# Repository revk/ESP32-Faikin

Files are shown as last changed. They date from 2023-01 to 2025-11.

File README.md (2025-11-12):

### Name change

Yes, it seems Daikin don't like Faikin, and I don't have the time or money to argue.

# ESP32-Faikout

Everyone knows Daikin make some of the best air conditioners out there, mechanically speaking. Sadly their WiFi control modules are not so good, especially the latest models which are all cloud based, require an internet connection to even work, and are slow.

[Faikout](https://www.youtube.com/watch?v=2QziOhK4P70 "Faikout")
Optional cabel
Optional case

This code/module provides local control via web interface, MQTT, and HomeAssistant integration, all with no cloud crap.



* There is also a new [Faikout Remote Control](https://remote.revk.uk/) available, BLE linked to the Faikout, with environmental sensors, available on Tindie now.

PCB designs are included, and also available to buy on [Tindie](https://www.tindie.com/stores/revk/), and on [Amazon UK](https://www.amazon.co.uk/dp/B0G1TP8XCQ). There are other people making and selling, e.g. on [eBay Australia](https://www.ebay.com.au/itm/186860658654).

I'd like to thank the contributors, but contributions are made and accepted on basis that you issue your contribution under the same GPL licence as the project. Forks are allowed on the basis that your forks are on the same GPL licence as the project.

## Trademark

This is an open source project, but bear in mind you cannot sell boards bearing the Andrews & Arnold Ltd name, the A&A logo, the registered trademark AJK logo, or the GS1 allocated EANs assigned to Andrews & Arnold Ltd.

## Further manuals / links

- [Work in progress / release notes](https://github.com/revk/ESP32-Faikout/wiki/Work-in-progress)
- [Wiring](https://github.com/revk/ESP32-Faikout/wiki/Wiring)
- [Setup](Manuals/Setup.md) Manual
- [Controls](Manuals/Controls.md) Manual
- [Advanced](Manuals/Advanced.md) Manual
- [ESP8266 port](https://github.com/Sonic-Amiga/ESP8266-Faikin) of this code
- [list of supported air-con](https://github.com/revk/ESP32-Faikout/wiki/List-of-confirmed-working-air-con-units) WiKi (please update as needed)
- [DoC](Manuals/DoC.md) and Vulnerability disclosure policy
- [S21](Manuals/S21.md) reverse engineered details of `S21` protocol

For support, see issues and discussions.

## PCB and case

The boards from [Tindie](https://www.tindie.com/stores/revk/), [eBay](https://www.ebay.com.au/itm/186860658654), and [Amazon UK](https://www.amazon.co.uk/dp/B0G1TP8XCQ) works with Daikin modules via an `S21` connector, or `X50A` and `X35A` connectors, or similar. The design is updated from time to time so may not look exactly like this.

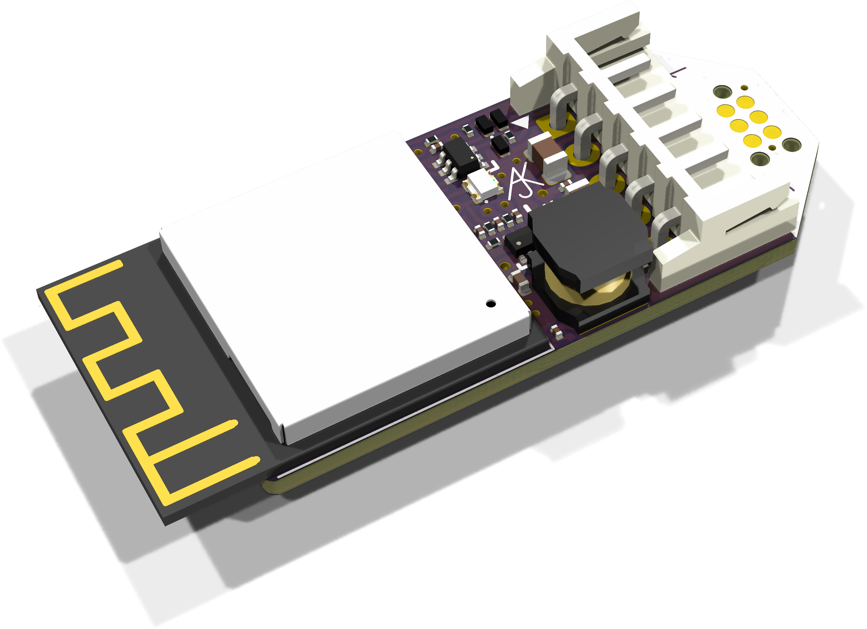
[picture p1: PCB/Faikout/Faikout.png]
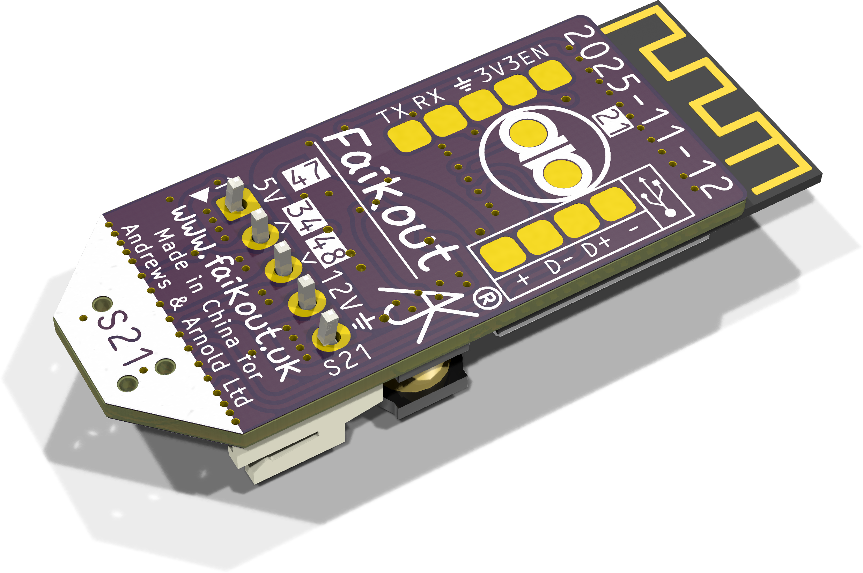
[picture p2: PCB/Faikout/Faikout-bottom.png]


The case design matches the PCB (check dates match). Designed for resin printing.

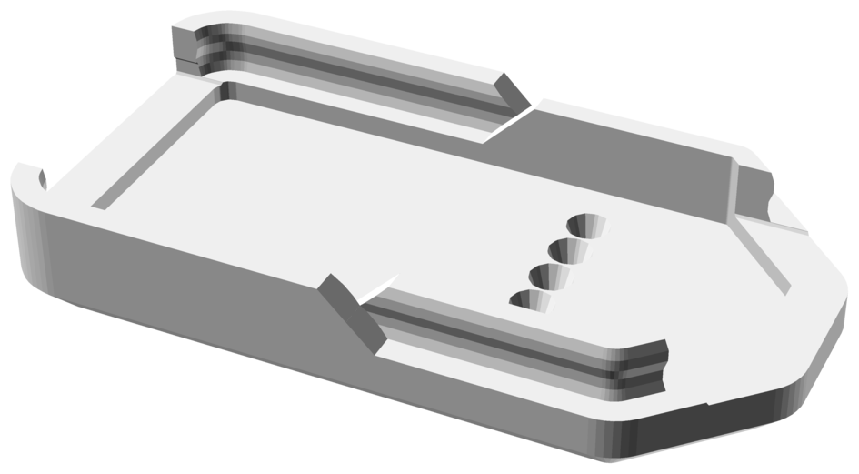
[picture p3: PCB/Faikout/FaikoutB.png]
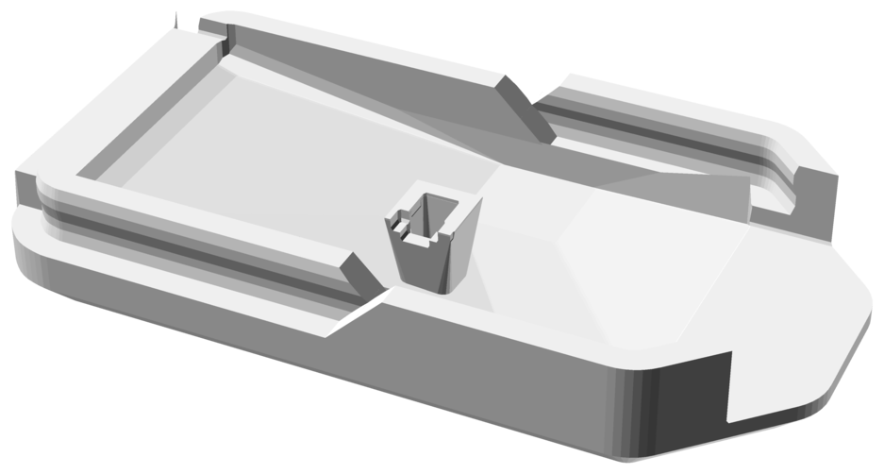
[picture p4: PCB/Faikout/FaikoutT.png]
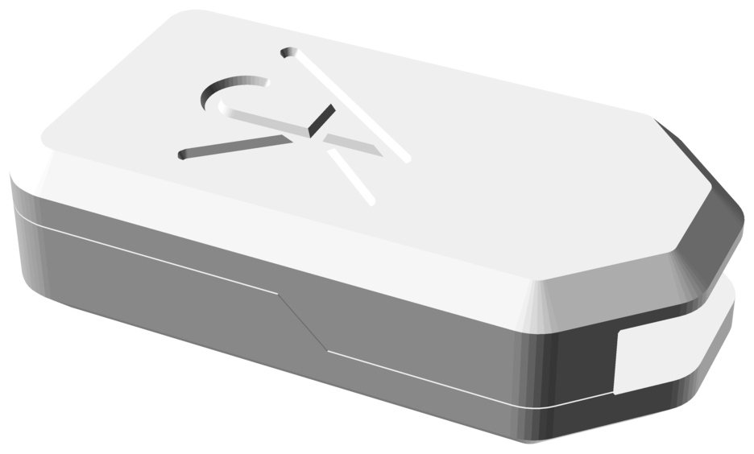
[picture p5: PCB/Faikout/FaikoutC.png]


Supplied in a 70x70 panel as an assembled PCB with snap off parts down to two sizes. 45x36mm or 40x16mm.

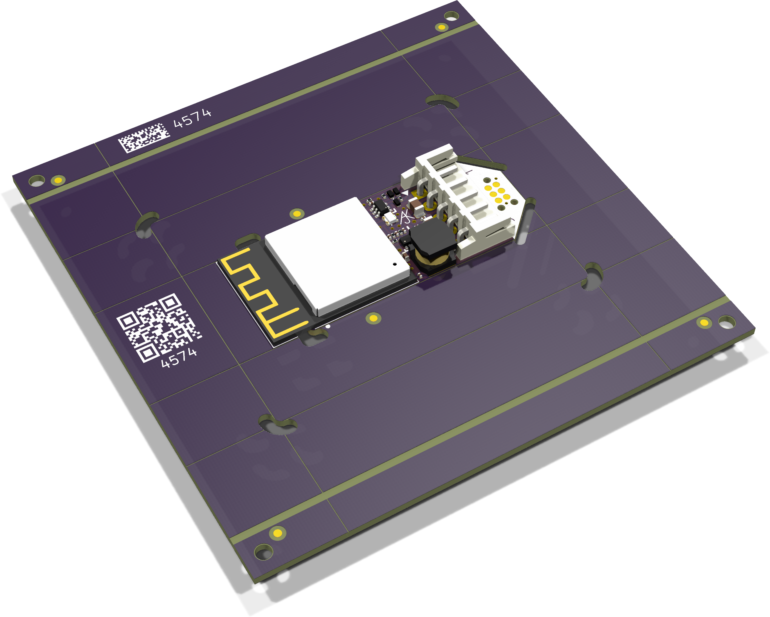
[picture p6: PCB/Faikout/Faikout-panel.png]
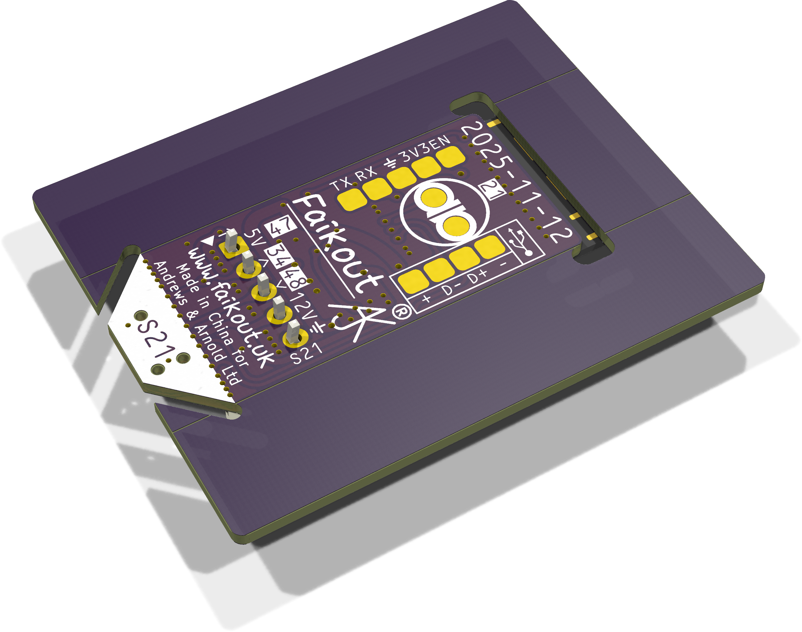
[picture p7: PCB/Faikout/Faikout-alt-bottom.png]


## Why I made this

The history is that, after years of using Daikin air-con in my old home, and using the local http control, in my new house in Wales the WiFi was all cloud based with no local control, and useless, and slow. Just configuring it was a nightmare. I spent all day reverse engineering it and making a new module to provide local control. Pull requests and feature ideas welcome.

This whole project is almost entirely by me, but with some valuable contributions from others (thank you). All of my bits are copyright by me and Andrews & Arnold Ltd who sponsor the whole project, and released under GPL. Whilst not required by the licence, attribution and links would be appreciated if you reuse this.

## How to get one

As mentioned, [Tindie](https://www.tindie.com/stores/revk/), [eBay](https://www.ebay.com.au/itm/186860658654), and [Amazon UK](https://www.amazon.co.uk/dp/B0G1TP8XCQ).

But also, the PCB designs are published, including production files for [JLCPCB](https://jlcpcb.com). You need to remove trademarks, etc, and you would also need something to program them (TC2030 lead). Obviously you need some experience with PCB ordering and diagnostics if getting your own boards made.

# Set-up

Appears as access point with simple web page to set up on local WiFI. On iPhone the setup page auto-loads.

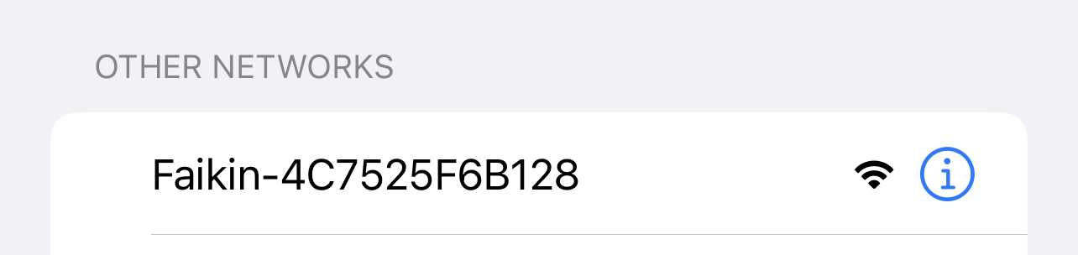
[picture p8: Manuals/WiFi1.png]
WiFi1


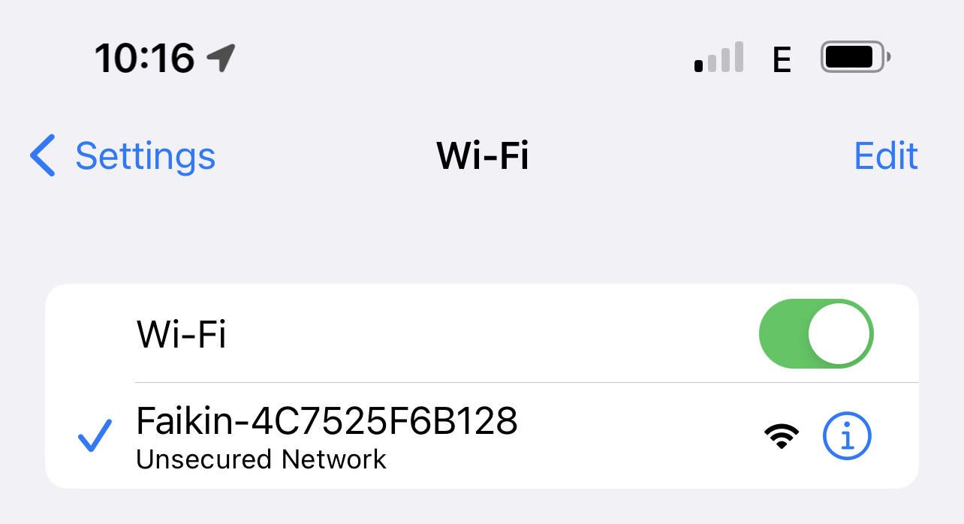
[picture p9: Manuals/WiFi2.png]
WiFi2


# Operation

Local interactive web control page using *hostname*.local, no app required, no external internet required.

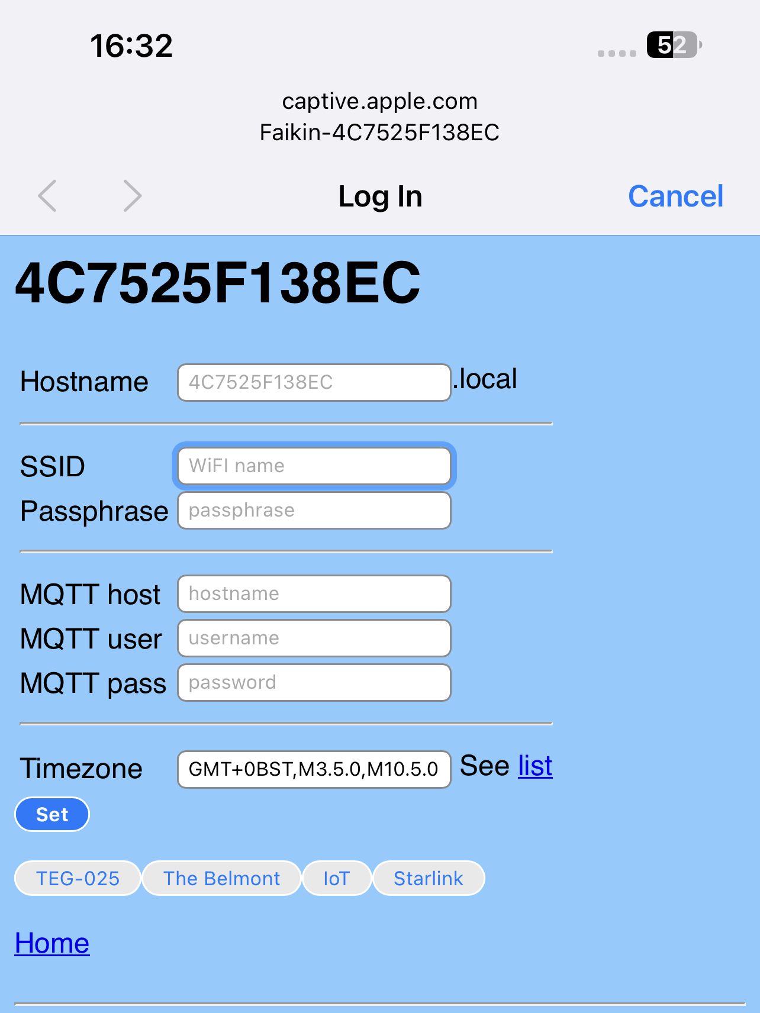
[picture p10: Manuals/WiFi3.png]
WiFi3


- [Setup](Manuals/Setup.md) Manual
- [Controls](Manuals/Controls.md) Manual
- [Advanced](Manuals/Advanced.md) Manual

# Design

* KiCad PCB designs included, with JLCPCB production files
* 3D printed case STL files
* Documentation of reverse engineered protocol included

Basically, Daikin have gone all cloudy with the latest WiFi controllers. This module is designed to provide an alternative.

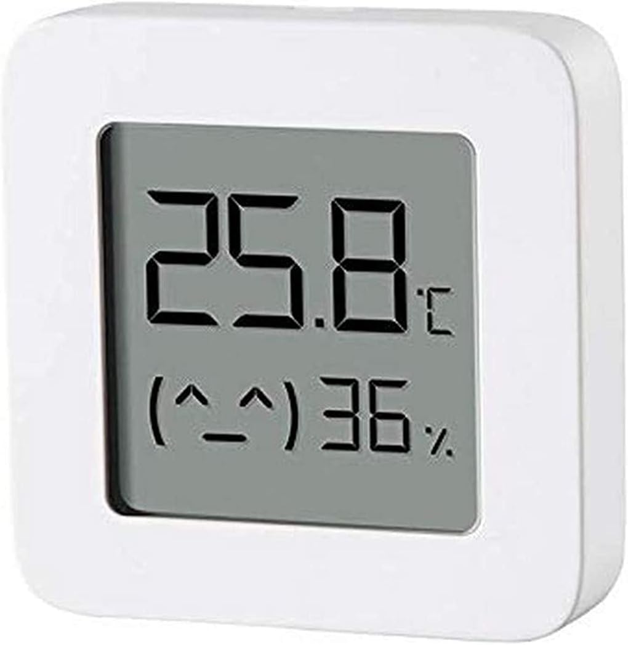
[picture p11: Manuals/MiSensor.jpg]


* Simple local web based control with live websocket status, easy to save as desktop icon on a mobile phone
* MQTT reporting and controls
* Works with Home Assistant over MQTT - note Home Assistant can work with HomeKit
* Includes linux mysql/mariadb based logging and graphing tools
* Works with [EnvMon](https://github.com/revk/ESP32-EnvMon) Environmental Monitor for finer control and status display
* or, works with BlueCoinT and Telink [BLE temperature sensor](Manuals/BLE.md) as a remote reference in an auto mode
* Automatically works out if S21 or X50 protocol (used on bigger/ducted units)
* Backwards compatible direct `/aircon/...` URLs

# Building code yourself

Git clone this `--recursive` to get all the submodules, and it should build with just `make`. There are make targets for other variations, but this hardware is the `make pico` or `make s3` version. The `make` actually runs the normal `idf.py` to build which then uses cmake. `make menuconfig` can be used to fine tune the settings, but the defaults should be mostly sane. `make flash` should work to program. If flashing yourself, you will need a programming lead, e.g. [Tazmotizer](https://github.com/revk/Shelly-Tasmotizer-PCB) or similar, and of course the full ESP IDF environment. The latest boards also have 4 pads for direct USB connection to flash with no adaptor. The modules on Amazon come pre-loaded and can upgrade over the air.

The code is normally set up to automatically upgrade the software, checking roughtly once a week. You can change this in settings via MQTT.

If you build yourself, you either need no code signing, or your own signing key. This will break auto-updates which try to load my code releases, so you need to adjuist settings `otahost` and `otaauto` accordingly. You can set these in the build config, along with WiFi settings, etc.

If you want to purchase a pre-loaded assembled PCB, see [Tindie](https://www.tindie.com/stores/revk/), and [Amazon UK](https://www.amazon.co.uk/dp/B0C2ZYXNYQ).

## Flashing code

You will need to connect a suitable programming lead. Boards have a header for USB. The very latest design (expected on Amazon around Sep 2024) has a tag-connect compatible header for a [TC2030-USB-NL](https://www.tag-connect.com/product/tc2030-usb-nl) lead. Note that the latest boards have testr pads on the back which include USB, so you can solder a USB lead if necessary.

See [https://github.com/revk/ESP32-RevK](https://github.com/revk/ESP32-RevK) for more details of how to flash the files easily.

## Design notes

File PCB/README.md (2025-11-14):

# PCB designs

The design is in [KiCad](https://www.kicad.org) and has production files for JLCPCB. The boards are available on [Amazon](https://www.amazon.co.uk/dp/B0C2ZYXNYQ).

The `PCBCase` directory is a tool for making 3D cases from the PCBs files, these are usually kept up to date as an `.stl` file in the `Faikout` directory. The `Makefile` simply runs this tool.

## Trademark

This is an open source project, but bear in mind you cannot sell boards bearing the Andrews & Arnold Ltd name, the A&A logo, the registered trademark AJK logo, or the GS1 allocated EANs assigned to Andrews & Arnold Ltd.



## Panel

Supplied in a 70x70 panel as an assembled PCB with snap off parts down to two sizes. 45x36mm or 40x16mm.



The panel includes slots and v-cuts to allow the unwanted parts of the panel to be snapped off. On the thicker (1.6mm) boards this can be a tad un-nerving, but just bend along the v-cut to snap the board on the cut line. I make the boards at 1.2mm thickness to make this easier.

The board design also allows the panel to be snapped off down to a 45mm x 36mm small board. This is the same size as commonly used for built-in Daikin WiFi modules, so if replacing the standard Daikin WiFi, it should fit exactly in the case. Obviously this only applies to some models.

You can further snap off down to the actual module, which is currently 40mm x 16mm. This is the usual way the module is used. The 3D print design is for this board.

The back of the board has no components, making it simple to stick to a flat surface with tape - you may want to crop the pins on the 5 pin connector if doing this. Do not stick to a metal surface as this may impact the WiFi or short the pins.

## S21 Connector

The connector is `JST-EH` 5 pin connector. This seems to be pretty standard in Daikin units. It is the connector used on the Daikin WiFi modules `BRP069B41` and `BRP069C41`. This means it should usually be possible to get a lead for your Daikin to a `JST-EH` 5 pin `S21` connector. If you have an `S21` connector on your air-con it will likely be the same pin out, so one to one wiring. If you have an `X50A` connector the wiring is different, and getting a suitable lead is a good idea.

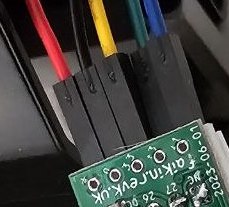
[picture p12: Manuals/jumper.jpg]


From what we can tell, the `S21` pin out is as follows :-

|Pin|Meaning|
|---|---|
|1|5V (not always present)|
|2|Tx from aircon - 5V logic levels|
|3|Rx to aircon - expects 5V logic and has 5V pull up, but some modeles work at 3.3V|
|4|12V, or 14V. We accept 4V to 36V|
|5|GND|

However, there are jumper wires readily available that can be used easily with these connectors, and can be used to connect to the `S21` connector on the aircon PCB one wire at a time.

**Please take care with your air-con unit - disconnect power before opening, and anything you do is at your own risk.**

## GPIO

This board is designed to work with the Daikin air-con, but it is a general purpose board. The latest boards use `ESP32-S3-MINI-N4R2` processor, with previous being `ESP32-MINI-PICO-01`.

The current boards include the GPIO numbers clearly in inverse silk screen.

For example, on this image, GPIO `34` and `48` for Tx and Rx. GPIO `47` is for the WS2812 style LED. GPIO `21` is one of two round pads.

The two round pads in the A&A logo can be shorted three times in a row to factory reset.

There are also test pins which allow connection for USB, and for diagnostics during production. A TC2030 connector is used for production programming.

Bottom

## Programming

The board has pads for a TC2030 USB lead for programming directly using `esptool`.

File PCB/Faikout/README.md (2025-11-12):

# Faikout

## Trademark

This is an open source project, but bear in mind you cannot sell boards or cases bearing the Andrews & Arnold Ltd name, the A&A logo, the registered trademark AJK logo, or the GS1 allocated EANs assigned to Andrews & Arnold Ltd.

## PCB Designs

These files are for use with [KiCAD](https://www.kicad.org).

- [Faikout](Faikout.kicad_pro)

## 3D

3D case designs are normally automatically created from the PCB so as to ensure correct details and placement of apertures, etc.

|Design|Bottom|Top|Combined|
|---|---|---|---|
|Faikout||||

## PCB Images

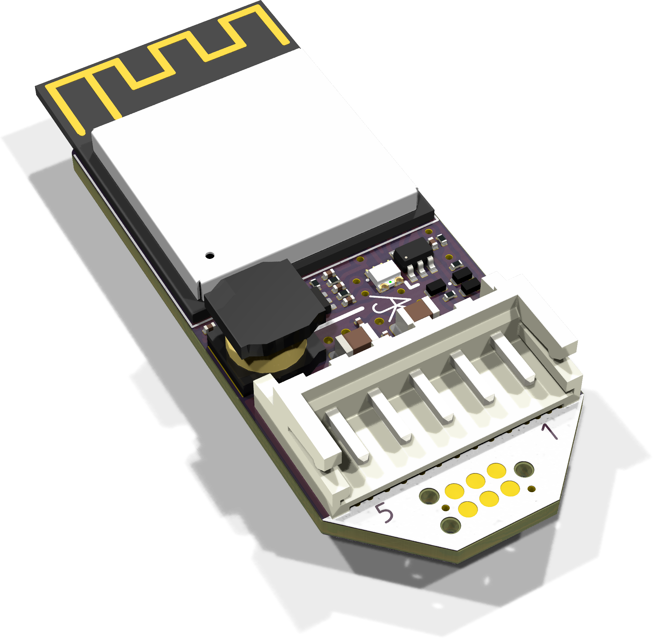
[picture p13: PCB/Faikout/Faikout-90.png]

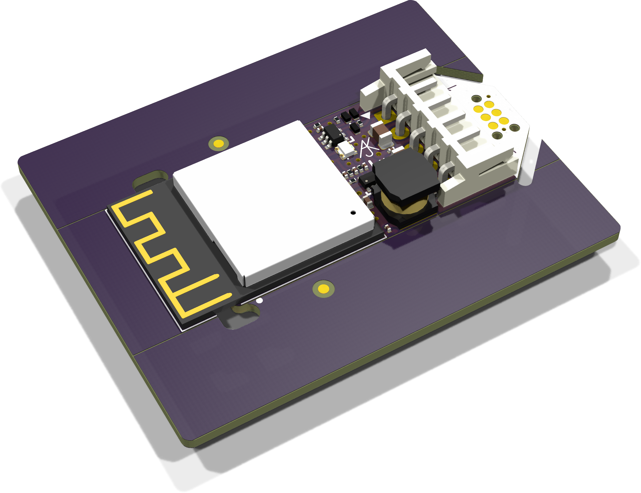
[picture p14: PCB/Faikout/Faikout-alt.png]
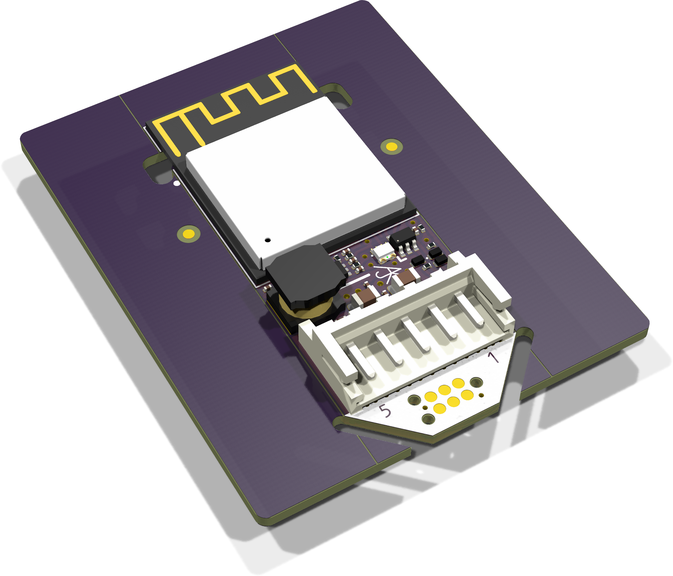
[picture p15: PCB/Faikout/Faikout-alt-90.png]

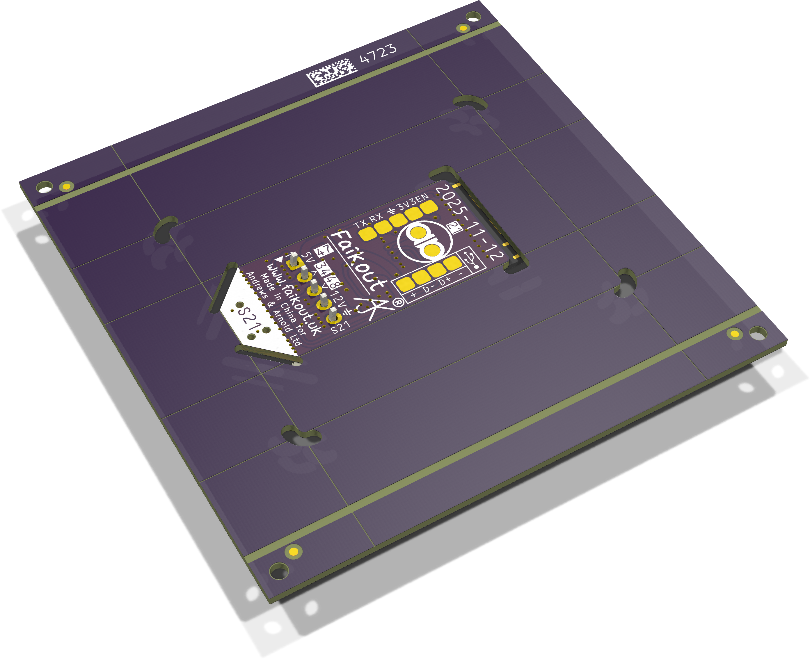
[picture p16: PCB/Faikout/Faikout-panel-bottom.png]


---

*Auto generated README.md 2025-11-12T08:11:45*

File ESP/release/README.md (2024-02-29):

# Reflashing

Ideally you build the code and flash, but that will be your code signing.

You can also flash these binaries.

You need `esptool`

## esptool

`esptool.py -p /dev/ttyUSB0 write_flash 0x1000 Faikin-S1-PICO-bootloader.bin 0x8000 partition-table.bin 0xd000 ota_data_initial.bin 0x10000 Faikin-S1-PICO.bin`

- The `Faikin-S1-PICO-bootloader.bin` needs to be the relevant release bootloader binary file for the chip used.
- The `Faikin-S1-PICO.bin` needs to be the relevant release binary file for the chip used.
- The bootloader address differs between ESP32 versions S1 and S3. For the S1 versions the bootloader is located at 0x1000. For the S3 models this needs to be changed to 0x0.

## 8266 port

The ESP8266 port is maintained by Pavel Fedin; project URL is: https://github.com/Sonic-Amiga/ESP8266-Faikin .
Since this is a backport; it may lack some features of the newest ESP32 version. Please contact the author for any questions.

Flashing command (addresses differ from ESP32 !!!)

`esptool.py -p COM3 -b 460800 --after hard_reset write_flash --flash_mode dio --flash_freq 40m --flash_size 8MB 0x8000 partition-table-8266.bin 0xd000 ota_data_initial-8266.bin 0x0 Faikin-8266-bootloader.bin 0x10000 Faikin-8266.bin`

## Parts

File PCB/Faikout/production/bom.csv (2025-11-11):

Designator | Footprint | Quantity | Value | LCSC Part #
C1, C18, C2, C4, C5, C7 | C_0201 | 6 | 100nF | C76934
C15 | C_0805 | 1 | 47uF 6V3 | C16780
C16, C3 | C_0402 | 2 | 100nF 25V | C56392
C17 | C_0805 | 1 | 22uF 25V | C45783
C19 | C_0201 | 1 | 18pF | C62164
C6 | C_0201 | 1 | 1uF
D1 | SMD1615-Blind | 1 | XL-1615RGBC-2812B | C5349954
D2, D3 | DFN1006-2L | 2 | ~ | C5137770
D4 | D_0402 | 1 | D | C28642302
J1 | JST_EH_S5B-EH_1x05_P2.50mm_Horizontal | 1 | 1x5 | C265103
L1 | L_5x5 | 1 | 4.7uH | C307876
Q1 | SOT-363_SC-70-6 | 1 | BSS138PS | C193381
R1, R2, R3 | R_0201 | 3 | 10k | C106225
R5, R6 | R_0201 | 2 | 150k 1% | C310173
R8 | R_0201 | 1 | 33k 1% | C320835
U1 | SOT-563 | 1 | TPS562246 | C41833479
U4 | ESP32-S3-MINI-1 | 1 | ESP32-S3-MINI-1-N4R2 | C3013941

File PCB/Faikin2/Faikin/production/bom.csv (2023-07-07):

Designator | Footprint | Quantity | Value | LCSC Part #
C1 | C_0402 | 1 | 1uF
C10 | C_0603_ | 1 | 100nF
C2, C5 | C_0402 | 2 | 100nF
C6, C7 | C_0402 | 2 | 33pF
C8 | C_0603_ | 1 | 10uF 50V | C1591
C9 | C_0603_ | 1 | 10uF 6.3V | C1691
D2 | LED-RGB-1.6x1.6 | 1 | RGB | C264508
J1 | JST_EH_S5B-EH_1x05_P2.50mm_Horizontal | 1 | 1x5 | C225427
L2 | L_4x4_ | 1 | 10uH
Q1 | SOT-363_SC-70-6 | 1 | BSS138PS | C193381
R1, R3, R4 | R_0402 | 3 | 10k
R10 | R_0402_ | 1 | 39k2
R11 | R_0402_ | 1 | 1M
R12 | R_0402 | 1 | 220R
R2, R8 | R_0402 | 2 | 100R
R5 | R_0402 | 1 | 680R
R6 | R_0402 | 1 | 2K
R9 | R_0402_ | 1 | 124k
U1 | ESP32-PICO-MINI-02 | 1 | ESP32-PICO-MINI-02 | C2980306
U3 | SOT-23-6-MD8942 | 1 | MD8942 | C2684786

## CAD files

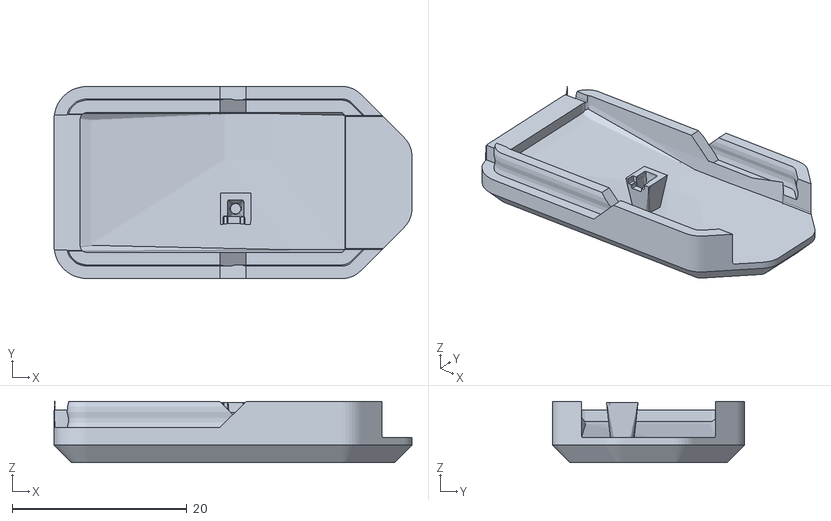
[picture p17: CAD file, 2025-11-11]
PCB/Faikin/FaikinT.stl
41.0 x 22.0 x 6.99

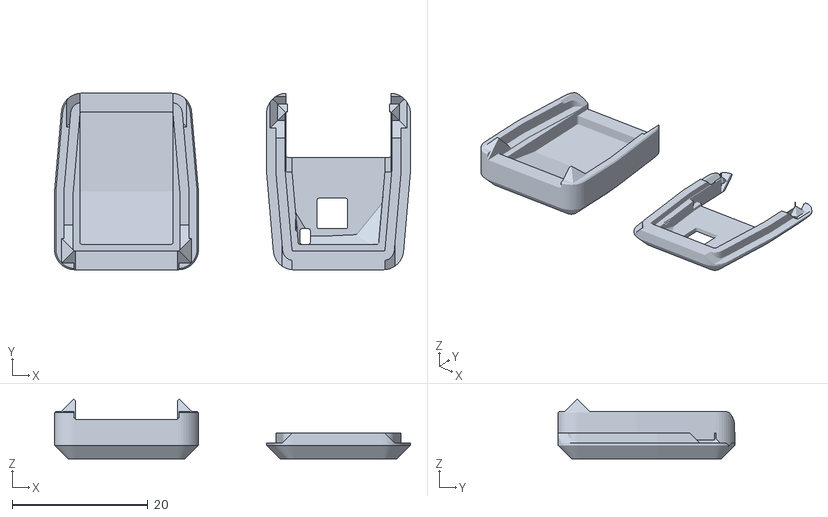
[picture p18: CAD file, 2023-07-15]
PCB/Faikin2/Faikin/Faikin.stl
52.4 x 26.0 x 8.79

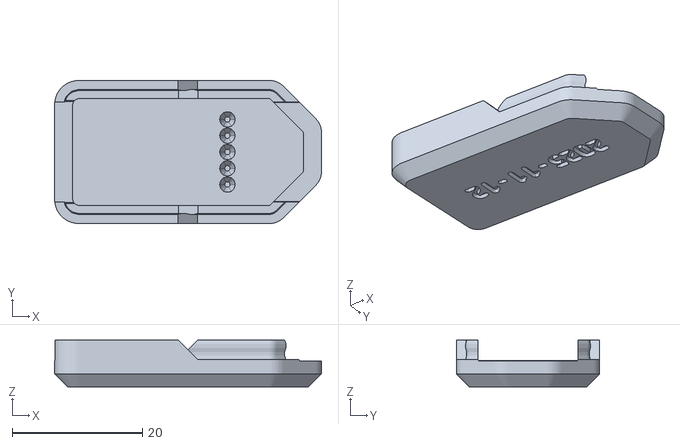
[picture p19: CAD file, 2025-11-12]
PCB/Faikout/FaikoutB.stl
41.0 x 22.0 x 7.20

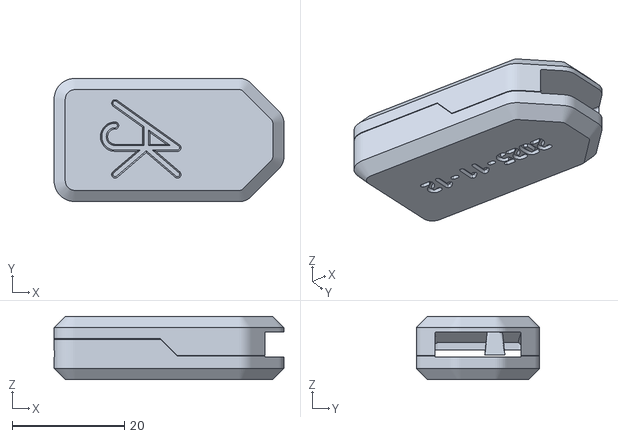
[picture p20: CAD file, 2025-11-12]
PCB/Faikout/FaikoutC.stl
41.0 x 22.0 x 11.3

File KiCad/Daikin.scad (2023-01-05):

// Generated case design for KiCad/Daikin.kicad_pcb
// By https://github.com/revk/PCBCase
// Generated 2023-01-05 14:30:20
// title:	Daikin ESP32-PICO-MINI Module
// date:	${DATE}
// rev:	1
// company:	Adrian Kennard, Andrews & Arnold Ltd
//

// Globals
margin=0.500000;
overlap=2.000000;
lip=0.000000;
casebase=2.500000;
casetop=5.000000;
casewall=3.000000;
fit=0.000000;
edge=2.000000;
pcbthickness=0.800000;
nohull=false;
hullcap=1.000000;
hulledge=1.000000;
useredge=false;

module pcb(h=pcbthickness,r=0){linear_extrude(height=h)offset(r=r)polygon(points=[[13.200000,0.400000],[13.200000,19.100000],[13.082843,19.382843],[12.800000,19.500000],[0.400000,19.500000],[0.117157,19.382843],[0.000000,19.100000],[0.000000,0.400000],[0.117157,0.117157],[0.400000,0.000000],[12.800000,0.000000],[13.082843,0.117157]],paths=[[0,1,2,3,4,5,6,7,8,9,10,11]]);}

module outline(h=pcbthickness,r=0){linear_extrude(height=h)offset(r=r)polygon(points=[[13.200000,0.400000],[13.200000,19.100000],[13.082843,19.382843],[12.800000,19.500000],[0.400000,19.500000],[0.117157,19.382843],[0.000000,19.100000],[0.000000,0.400000],[0.117157,0.117157],[0.400000,0.000000],[12.800000,0.000000],[13.082843,0.117157]],paths=[[0,1,2,3,4,5,6,7,8,9,10,11]]);}
spacing=29.200000;
pcbwidth=13.200000;
pcblength=19.500000;
// Populated PCB
module board(pushed=false,hulled=false){
translate([6.600000,13.906750,0.800000])translate([0.000000,2.700000,0.000000])rotate([90.000000,0.000000,0.000000])m0(pushed,hulled); // RevK:ESP32-PICO-MINI-02 ESP32-PICO-MINI-02
translate([6.600000,6.600000,0.800000])translate([1.250000,-3.600000,2.500000])rotate([-0.000000,0.000000,180.000000])m1(pushed,hulled); // RevK:Molex_MiniSPOX_H4RA 22057055
translate([1.050000,12.950000,0.000000])rotate([0,0,-90.000000])rotate([180,0,0])m2(pushed,hulled); // RevK:C_0805_ C_0805_2012Metric
translate([11.150000,13.375000,0.000000])rotate([0,0,-90.000000])rotate([180,0,0])m3(pushed,hulled); // RevK:R_0603 R_0603_1608Metric
translate([4.100000,9.350000,0.000000])rotate([0,0,90.000000])rotate([180,0,0])m4(pushed,hulled); // RevK:C_0603 C_0603_1608Metric
translate([10.850000,9.600000,0.000000])rotate([180,0,0])m5(pushed,hulled); // Package_TO_SOT_SMD:SOT-323_SC-70 SOT-323_SC-70
translate([4.170000,13.330000,0.000000])rotate([0,0,180.000000])rotate([180,0,0])m6(pushed,hulled); // RevK:D_1206_ D_1206_3216Metric
translate([8.550000,16.250000,0.000000])rotate([0,0,-90.000000])rotate([180,0,0])m4(pushed,hulled); // RevK:C_0603 C_0603_1608Metric
translate([9.125000,18.600000,0.000000])rotate([180,0,0])m3(pushed,hulled); // RevK:R_0603 R_0603_1608Metric
translate([9.900000,13.400000,0.000000])rotate([0,0,-90.000000])rotate([180,0,0])m3(pushed,hulled); // RevK:R_0603 R_0603_1608Metric
translate([12.450000,13.400000,0.000000])rotate([0,0,-90.000000])rotate([180,0,0])m3(pushed,hulled); // RevK:R_0603 R_0603_1608Metric
translate([2.100000,9.850000,0.000000])rotate([180,0,0])m3(pushed,hulled); // RevK:R_0603 R_0603_1608Metric
translate([7.300000,12.950000,0.000000])rotate([0,0,-90.000000])rotate([180,0,0])m2(pushed,hulled); // RevK:C_0805_ C_0805_2012Metric
translate([11.500000,15.900000,0.000000])rotate([180,0,0])translate([0.000000,-0.400000,0.000000])m7(pushed,hulled); // RevK:LED-RGB-1.6x1.6 LED_0603_1608Metric
translate([11.500000,15.900000,0.000000])rotate([180,0,0])translate([0.000000,0.400000,0.000000])m7(pushed,hulled); // RevK:LED-RGB-1.6x1.6 LED_0603_1608Metric
translate([2.100000,8.600000,0.000000])rotate([180,0,0])m4(pushed,hulled); // RevK:C_0603 C_0603_1608Metric
translate([6.450000,16.500000,0.000000])rotate([0,0,180.000000])rotate([180,0,0])rotate([-0.000000,0.000000,90.000000])m8(pushed,hulled); // RevK:SOT-23-Thin-6-Reg SOT-23-6
translate([2.550000,16.500000,0.000000])rotate([180,0,0])rotate([-0.000000,0.000000,90.000000])m9(pushed,hulled); // RevK:L_4x4_ TYA4020
translate([11.600000,18.600000,0.000000])rotate([0,0,180.000000])rotate([180,0,0])m3(pushed,hulled); // RevK:R_0603 R_0603_1608Metric
}

module b(cx,cy,z,w,l,h){translate([cx-w/2,cy-l/2,z])cube([w,l,h]);}
module m0(pushed=false,hulled=false)
{ // RevK:ESP32-PICO-MINI-02 ESP32-PICO-MINI-02
rotate([90,0,0])
translate([-13.2/2,-16.6/2,0])
{
	if(!hulled)cube([13.2,16.6,0.8]);
	cube([13.2,11.2,2.4]);
}
}

module m1(pushed=false,hulled=false)
{ // RevK:Molex_MiniSPOX_H4RA 22057055
N=5;
A=2.4+N*2.5;
rotate([0,0,180])
translate([-A/2,-2.94,-2.5])
{
	cube([A,4.9,4.9]);
	cube([A,5.9,3.9]);
	hull()
	{
		cube([A,7.4,1]);
		cube([A,7.9,0.5]);
	}
	translate([1,6,-2])cube([A-2,1.2,4.5]); // Assumes cropped pins
	// Plug
	translate([0.5,-20,0.6])cube([A-1,21,4.1]);
	translate([0,-23,0])cube([A,20,4.9]);
}

}

module m2(pushed=false,hulled=false)
{ // RevK:C_0805_ C_0805_2012Metric
b(0,0,0,2,1.45,0.2); // Pad size
b(0,0,0,2,1.2,1); // Chip
}

module m3(pushed=false,hulled=false)
{ // RevK:R_0603 R_0603_1608Metric
b(0,0,0,2.8,0.95,0.5); // Pad size
}

module m4(pushed=false,hulled=false)
{ // RevK:C_0603 C_0603_1608Metric
b(0,0,0,1.6,0.95,0.2); // Pad size
b(0,0,0,1.6,0.8,1); // Chip
}

module m5(pushed=false,hulled=false)
{ // Package_TO_SOT_SMD:SOT-323_SC-70 SOT-323_SC-70
b(0,0,0,1.26,2.2,1.2);
b(0,0,0,2.2,2.2,0.6);
}

module m6(pushed=false,hulled=false)
{ // RevK:D_1206_ D_1206_3216Metric
b(0,0,0,4.4,1.75,1.2); // Pad size
}

module m7(pushed=false,hulled=false)
{ // RevK:LED-RGB-1.6x1.6 LED_0603_1608Metric
b(0,0,0,1.6,0.8,0.25);
b(0,0,0,1.2,0.8,0.55);
b(0,0,0,0.8,0.8,0.95);
if(!hulled&&pushed)b(0,0,0,1,1,20);
}

module m8(pushed=false,hulled=false)
{ // RevK:SOT-23-Thin-6-Reg SOT-23-6
b(0,0,0,3.05,3.05,0.5);
b(0,0,0,1.45,3.05,1.1);
}

module m9(pushed=false,hulled=false)
{ // RevK:L_4x4_ TYA4020
b(0,0,0,4,4,2.1);
}

height=casebase+pcbthickness+casetop;
$fn=48;

module boardh(pushed=false)
{ // Board with hulled parts
	union()
	{
		if(!nohull)intersection()
		{
			translate([0,0,hullcap-casebase])outline(casebase+pcbthickness+casetop-hullcap*2,-hulledge);
			hull()board(pushed,true);
		}
		board(pushed,false);
		pcb();
	}
}

module boardf()
{ // This is the board, but stretched up to make a push out in from the front
	render()
	{
		intersection()
		{
			translate([-casewall-1,-casewall-1,-casebase-1]) cube([pcbwidth+casewall*2+2,pcblength+casewall*2+2,height+2]);
			union()
			{
				minkowski()
				{
					boardh(true);
					cylinder(h=height+100,d=margin,$fn=8);
				}
				board(false,false);
			}
		}
	}
}

module boardb()
{ // This is the board, but stretched down to make a push out in from the back
	render()
	{
		intersection()
		{
			translate([-casewall-1,-casewall-1,-casebase-1]) cube([pcbwidth+casewall*2+2,pcblength+casewall*2+2,height+2]);
			union()
			{
				minkowski()
				{
					boardh(true);
					translate([0,0,-height-100])
					cylinder(h=height+100,d=margin,$fn=8);
				}
				board(false,false);
			}
		}
	}
}

module boardm()
{
	render()
	{
 		minkowski()
 		{
			translate([0,0,-margin/2])cylinder(d=margin,h=margin,$fn=8);
 			boardh(false);
		}
		//intersection()
    		//{
        		//translate([0,0,-(casebase-hullcap)])pcb(pcbthickness+(casebase-hullcap)+(casetop-hullcap));
        		//translate([0,0,-(casebase-hullcap)])outline(pcbthickness+(casebase-hullcap)+(casetop-hullcap));
			boardh(false);
    		//}
 	}
}

module pcbh(h=pcbthickness,r=0)
{ // PCB shape for case
	if(useredge)outline(h,r);
	else hull()outline(h,r);
}

module pyramid()
{ // A pyramid
 polyhedron(points=[[0,0,0],[-height,-height,height],[-height,height,height],[height,height,height],[height,-height,height]],faces=[[0,1,2],[0,2,3],[0,3,4],[0,4,1],[4,3,2,1]]);
}

module wall(d=0)
{ // The case wall
    	translate([0,0,-casebase-d])pcbh(height+d*2,margin/2+d);
}

module cutf()
{ // This cut up from base in the wall
	intersection()
	{
		boardf();
		difference()
		{
			translate([-casewall+0.01,-casewall+0.01,-casebase+0.01])cube([pcbwidth+casewall*2-0.02,pcblength+casewall*2-0.02,casebase+overlap+lip]);
			wall();
			boardb();
		}
	}
}

module cutb()
{ // The cut down from top in the wall
	intersection()
	{
		boardb();
		difference()
		{
			translate([-casewall+0.01,-casewall+0.01,0.01])cube([pcbwidth+casewall*2-0.02,pcblength+casewall*2-0.02,casetop+pcbthickness]);
			wall();
			boardf();
		}
	}
}

module cutpf()
{ // the push up but pyramid
	render()
	intersection()
	{
		minkowski()
		{
			pyramid();
			cutf();
		}
		difference()
		{
			translate([-casewall-0.01,-casewall-0.01,-casebase-0.01])cube([pcbwidth+casewall*2+0.02,pcblength+casewall*2+0.02,casebase+overlap+lip+0.02]);
			wall();
			boardh(true);
		}
		translate([-casewall,-casewall,-casebase])case();
	}
}

module cutpb()
{ // the push down but pyramid
	render()
	intersection()
	{
		minkowski()
		{
			scale([1,1,-1])pyramid();
			cutb();
		}
		difference()
		{
			translate([-casewall-0.01,-casewall-0.01,-0.01])cube([pcbwidth+casewall*2+0.02,pcblength+casewall*2+0.02,casetop+pcbthickness+0.02]);
			wall();
			boardh(true);
		}
		translate([-casewall,-casewall,-casebase])case();
	}
}
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

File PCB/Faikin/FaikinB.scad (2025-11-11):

// Generated case design for Faikin/Faikin.kicad_pcb
// By https://github.com/revk/PCBCase
// Generated 2025-11-06 14:41:23
// title:	FAIKIN
// rev:	1
// company:	Adrian Kennard, Andrews & Arnold Ltd
//

// Globals
margin=0.200000;
lip=3.000000;
lipa=0;
lipt=1;
casewall=3.000000;
casebottom=3.000000;
casetop=7.000000;
bottomthickness=0.000000;
topthickness=0.000000;
fit=0.000000;
snap=0.150000;
edge=2.000000;
pcbthickness=1.200000;
function pcbthickness()=1.200000;
nohull=false;
hullcap=1.000000;
hulledge=1.000000;
useredge=false;
datex=0.000000;
datey=0.000000;
datet=0.500000;
dateh=3.000000;
datea=0;
date="2025-11-06";
datef="OCRB";
logox=-5.000000;
logoy=0.000000;
logot=0.500000;
logoh=10.000000;
logoa=-90;
logo="A";
logof="AJK";
spacing=51.000000;
pcbwidth=35.000000;
function pcbwidth()=35.000000;
pcblength=16.000000;
function pcblength()=16.000000;
originx=139.500000;
originy=65.000000;

module outline(h=pcbthickness,r=0){linear_extrude(height=h)offset(r=r)polygon(points=[[17.500000,-3.000000],[17.500000,3.000000],[12.500000,8.000000],[-16.750000,8.000000],[-17.125000,7.899519],[-17.399519,7.625000],[-17.500000,7.250000],[-17.500000,-7.250000],[-17.399519,-7.625000],[-17.125000,-7.899519],[-16.750000,-8.000000],[12.500000,-8.000000]],paths=[[0,1,2,3,4,5,6,7,8,9,10,11]]);}

module pcb(h=pcbthickness,r=0){linear_extrude(height=h)offset(r=r)polygon(points=[[17.500000,-3.000000],[17.500000,3.000000],[12.500000,8.000000],[-16.750000,8.000000],[-17.125000,7.899519],[-17.399519,7.625000],[-17.500000,7.250000],[-17.500000,-7.250000],[-17.399519,-7.625000],[-17.125000,-7.899519],[-16.750000,-8.000000],[12.500000,-8.000000]],paths=[[0,1,2,3,4,5,6,7,8,9,10,11]]);}
module C19(){translate([-0.250000,0.400000,1.200000])rotate([0,0,90.000000])children();}
module part_C19(part=true,hole=false,block=false)
{
translate([-0.250000,0.400000,1.200000])rotate([0,0,90.000000])m0(part,hole,block,casetop); // RevK:C_0201 C_0201_0603Metric (back)
};
module R6(){translate([-0.800000,0.400000,1.200000])rotate([0,0,-90.000000])children();}
module part_R6(part=true,hole=false,block=false)
{
translate([-0.800000,0.400000,1.200000])rotate([0,0,-90.000000])m1(part,hole,block,casetop); // RevK:R_0201 R_0201_0603Metric (back)
};
module R1(){translate([3.300000,5.400000,1.200000])rotate([0,0,90.000000])children();}
module part_R1(part=true,hole=false,block=false)
{
translate([3.300000,5.400000,1.200000])rotate([0,0,90.000000])m1(part,hole,block,casetop); // RevK:R_0201 R_0201_0603Metric (back)
};
module C5(){translate([4.100000,0.900000,1.200000])rotate([0,0,180.000000])children();}
module part_C5(part=true,hole=false,block=false)
{
translate([4.100000,0.900000,1.200000])rotate([0,0,180.000000])m0(part,hole,block,casetop); // RevK:C_0201 C_0201_0603Metric (back)
};
module V4(){translate([-4.500000,-18.000000,1.200000])children();}
module part_V4(part=true,hole=false,block=false)
{
};
module J2(){translate([15.000000,0.000000,1.200000])rotate([0,0,-90.000000])children();}
module part_J2(part=true,hole=false,block=false)
{
};
module D1(){translate([0.300000,3.000000,1.200000])rotate([0,0,180.000000])children();}
module part_D1(part=true,hole=false,block=false)
{
translate([0.300000,3.000000,1.200000])rotate([0,0,180.000000])m2(part,hole,block,casetop); // D1
};
module V5(){translate([-27.500000,0.000000,1.200000])rotate([0,0,90.000000])children();}
module part_V5(part=true,hole=false,block=false)
{
};
module V3(){translate([-4.500000,18.000000,1.200000])children();}
module part_V3(part=true,hole=false,block=false)
{
};
module C16(){translate([-1.250000,-3.500000,1.200000])rotate([0,0,-90.000000])children();}
module part_C16(part=true,hole=false,block=false)
{
translate([-1.250000,-3.500000,1.200000])rotate([0,0,-90.000000])m3(part,hole,block,casetop); // RevK:C_0402 C_0402_1005Metric (back)
};
module D3(){translate([3.400000,6.700000,1.200000])rotate([0,0,-90.000000])children();}
module part_D3(part=true,hole=false,block=false)
{
translate([3.400000,6.700000,1.200000])rotate([0,0,-90.000000])m4(part,hole,block,casetop); // D3
};
module R5(){translate([0.300000,0.400000,1.200000])rotate([0,0,90.000000])children();}
module part_R5(part=true,hole=false,block=false)
{
translate([0.300000,0.400000,1.200000])rotate([0,0,90.000000])m1(part,hole,block,casetop); // RevK:R_0201 R_0201_0603Metric (back)
};
module C7(){translate([2.580000,0.100000,1.200000])children();}
module part_C7(part=true,hole=false,block=false)
{
translate([2.580000,0.100000,1.200000])m0(part,hole,block,casetop); // RevK:C_0201 C_0201_0603Metric (back)
};
module C6(){translate([-0.429742,6.600000,1.200000])children();}
module part_C6(part=true,hole=false,block=false)
{
translate([-0.429742,6.600000,1.200000])m0(part,hole,block,casetop); // RevK:C_0201 C_0201_0603Metric (back)
};
module D4(){translate([2.500000,6.700000,1.200000])rotate([0,0,90.000000])children();}
module part_D4(part=true,hole=false,block=false)
{
translate([2.500000,6.700000,1.200000])rotate([0,0,90.000000])m4(part,hole,block,casetop); // D3 (back)
};
module Q1(){translate([0.100000,5.000000,1.200000])rotate([0,0,180.000000])children();}
module part_Q1(part=true,hole=false,block=false)
{
translate([0.100000,5.000000,1.200000])rotate([0,0,180.000000])m5(part,hole,block,casetop); // Q1
};
module C2(){translate([-1.250000,-7.100000,1.200000])rotate([0,0,90.000000])children();}
module part_C2(part=true,hole=false,block=false)
{
translate([-1.250000,-7.100000,1.200000])rotate([0,0,90.000000])m0(part,hole,block,casetop); // RevK:C_0201 C_0201_0603Metric (back)
};
module R3(){translate([-0.429742,7.200000,1.200000])rotate([0,0,180.000000])children();}
module part_R3(part=true,hole=false,block=false)
{
translate([-0.429742,7.200000,1.200000])rotate([0,0,180.000000])m1(part,hole,block,casetop); // RevK:R_0201 R_0201_0603Metric (back)
};
module D2(){translate([2.500000,5.000000,1.200000])rotate([0,0,90.000000])children();}
module part_D2(part=true,hole=false,block=false)
{
translate([2.500000,5.000000,1.200000])rotate([0,0,90.000000])m4(part,hole,block,casetop); // D3
};
module FID2(){translate([-9.750000,10.000000,1.200000])children();}
module part_FID2(part=true,hole=false,block=false)
{
};
module U1(){translate([0.200000,-1.387500,1.200000])rotate([0,0,90.000000])children();}
module part_U1(part=true,hole=false,block=false)
{
translate([0.200000,-1.387500,1.200000])rotate([0,0,90.000000])m6(part,hole,block,casetop); // U1
};
module C3(){translate([4.800000,-3.700000,1.200000])rotate([0,0,-90.000000])children();}
module part_C3(part=true,hole=false,block=false)
{
translate([4.800000,-3.700000,1.200000])rotate([0,0,-90.000000])m3(part,hole,block,casetop); // RevK:C_0402 C_0402_1005Metric (back)
};
module U4(){translate([-9.750000,0.000000,1.200000])rotate([0,0,90.000000])children();}
module part_U4(part=true,hole=false,block=false)
{
translate([-9.750000,0.000000,1.200000])rotate([0,0,90.000000])m7(part,hole,block,casetop); // U4
};
module C1(){translate([-1.350000,0.400000,1.200000])rotate([0,0,90.000000])children();}
module part_C1(part=true,hole=false,block=false)
{
translate([-1.350000,0.400000,1.200000])rotate([0,0,90.000000])m0(part,hole,block,casetop); // RevK:C_0201 C_0201_0603Metric (back)
};
module V2(){translate([-4.500000,-8.000000,1.200000])rotate([0,0,180.000000])children();}
module part_V2(part=true,hole=false,block=false)
{
};
module C15(){translate([4.100000,2.800000,1.200000])rotate([0,0,90.000000])children();}
module part_C15(part=true,hole=false,block=false)
{
translate([4.100000,2.800000,1.200000])rotate([0,0,90.000000])m8(part,hole,block,casetop); // RevK:C_0805 C_0805_2012Metric (back)
};
module J1(){translate([6.055000,5.000000,1.200000])rotate([0,0,-90.000000])children();}
module part_J1(part=true,hole=false,block=false)
{
translate([6.055000,5.000000,1.200000])rotate([0,0,-90.000000])m9(part,hole,block,casetop,05); // J1
};
module FID3(){translate([-9.750000,-10.000000,1.200000])children();}
module part_FID3(part=true,hole=false,block=false)
{
};
module R8(){translate([-1.100000,-0.600000,1.200000])rotate([0,0,180.000000])children();}
module part_R8(part=true,hole=false,block=false)
{
translate([-1.100000,-0.600000,1.200000])rotate([0,0,180.000000])m1(part,hole,block,casetop); // RevK:R_0201 R_0201_0603Metric (back)
};
module C17(){translate([4.100000,-1.000000,1.200000])rotate([0,0,90.000000])children();}
module part_C17(part=true,hole=false,block=false)
{
translate([4.100000,-1.000000,1.200000])rotate([0,0,90.000000])m8(part,hole,block,casetop); // RevK:C_0805 C_0805_2012Metric (back)
};
module L1(){translate([1.700000,-5.200000,1.200000])rotate([0,0,-90.000000])children();}
module part_L1(part=true,hole=false,block=false)
{
translate([1.700000,-5.200000,1.200000])rotate([0,0,-90.000000])m10(part,hole,block,casetop); // L1
};
module R2(){translate([1.600000,6.900000,1.200000])rotate([0,0,90.000000])children();}
module part_R2(part=true,hole=false,block=false)
{
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

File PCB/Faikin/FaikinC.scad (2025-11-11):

// Generated case design for Faikin/Faikin.kicad_pcb
// By https://github.com/revk/PCBCase
// Generated 2025-11-06 14:41:23
// title:	FAIKIN
// rev:	1
// company:	Adrian Kennard, Andrews & Arnold Ltd
//

// Globals
margin=0.200000;
lip=3.000000;
lipa=0;
lipt=1;
casewall=3.000000;
casebottom=3.000000;
casetop=7.000000;
bottomthickness=0.000000;
topthickness=0.000000;
fit=0.000000;
snap=0.150000;
edge=2.000000;
pcbthickness=1.200000;
function pcbthickness()=1.200000;
nohull=false;
hullcap=1.000000;
hulledge=1.000000;
useredge=false;
datex=0.000000;
datey=0.000000;
datet=0.500000;
dateh=3.000000;
datea=0;
date="2025-11-06";
datef="OCRB";
logox=-5.000000;
logoy=0.000000;
logot=0.500000;
logoh=10.000000;
logoa=-90;
logo="A";
logof="AJK";
spacing=51.000000;
pcbwidth=35.000000;
function pcbwidth()=35.000000;
pcblength=16.000000;
function pcblength()=16.000000;
originx=139.500000;
originy=65.000000;

module outline(h=pcbthickness,r=0){linear_extrude(height=h)offset(r=r)polygon(points=[[17.500000,-3.000000],[17.500000,3.000000],[12.500000,8.000000],[-16.750000,8.000000],[-17.125000,7.899519],[-17.399519,7.625000],[-17.500000,7.250000],[-17.500000,-7.250000],[-17.399519,-7.625000],[-17.125000,-7.899519],[-16.750000,-8.000000],[12.500000,-8.000000]],paths=[[0,1,2,3,4,5,6,7,8,9,10,11]]);}

module pcb(h=pcbthickness,r=0){linear_extrude(height=h)offset(r=r)polygon(points=[[17.500000,-3.000000],[17.500000,3.000000],[12.500000,8.000000],[-16.750000,8.000000],[-17.125000,7.899519],[-17.399519,7.625000],[-17.500000,7.250000],[-17.500000,-7.250000],[-17.399519,-7.625000],[-17.125000,-7.899519],[-16.750000,-8.000000],[12.500000,-8.000000]],paths=[[0,1,2,3,4,5,6,7,8,9,10,11]]);}
module C19(){translate([-0.250000,0.400000,1.200000])rotate([0,0,90.000000])children();}
module part_C19(part=true,hole=false,block=false)
{
translate([-0.250000,0.400000,1.200000])rotate([0,0,90.000000])m0(part,hole,block,casetop); // RevK:C_0201 C_0201_0603Metric (back)
};
module R6(){translate([-0.800000,0.400000,1.200000])rotate([0,0,-90.000000])children();}
module part_R6(part=true,hole=false,block=false)
{
translate([-0.800000,0.400000,1.200000])rotate([0,0,-90.000000])m1(part,hole,block,casetop); // RevK:R_0201 R_0201_0603Metric (back)
};
module R1(){translate([3.300000,5.400000,1.200000])rotate([0,0,90.000000])children();}
module part_R1(part=true,hole=false,block=false)
{
translate([3.300000,5.400000,1.200000])rotate([0,0,90.000000])m1(part,hole,block,casetop); // RevK:R_0201 R_0201_0603Metric (back)
};
module C5(){translate([4.100000,0.900000,1.200000])rotate([0,0,180.000000])children();}
module part_C5(part=true,hole=false,block=false)
{
translate([4.100000,0.900000,1.200000])rotate([0,0,180.000000])m0(part,hole,block,casetop); // RevK:C_0201 C_0201_0603Metric (back)
};
module V4(){translate([-4.500000,-18.000000,1.200000])children();}
module part_V4(part=true,hole=false,block=false)
{
};
module J2(){translate([15.000000,0.000000,1.200000])rotate([0,0,-90.000000])children();}
module part_J2(part=true,hole=false,block=false)
{
};
module D1(){translate([0.300000,3.000000,1.200000])rotate([0,0,180.000000])children();}
module part_D1(part=true,hole=false,block=false)
{
translate([0.300000,3.000000,1.200000])rotate([0,0,180.000000])m2(part,hole,block,casetop); // D1
};
module V5(){translate([-27.500000,0.000000,1.200000])rotate([0,0,90.000000])children();}
module part_V5(part=true,hole=false,block=false)
{
};
module V3(){translate([-4.500000,18.000000,1.200000])children();}
module part_V3(part=true,hole=false,block=false)
{
};
module C16(){translate([-1.250000,-3.500000,1.200000])rotate([0,0,-90.000000])children();}
module part_C16(part=true,hole=false,block=false)
{
translate([-1.250000,-3.500000,1.200000])rotate([0,0,-90.000000])m3(part,hole,block,casetop); // RevK:C_0402 C_0402_1005Metric (back)
};
module D3(){translate([3.400000,6.700000,1.200000])rotate([0,0,-90.000000])children();}
module part_D3(part=true,hole=false,block=false)
{
translate([3.400000,6.700000,1.200000])rotate([0,0,-90.000000])m4(part,hole,block,casetop); // D3
};
module R5(){translate([0.300000,0.400000,1.200000])rotate([0,0,90.000000])children();}
module part_R5(part=true,hole=false,block=false)
{
translate([0.300000,0.400000,1.200000])rotate([0,0,90.000000])m1(part,hole,block,casetop); // RevK:R_0201 R_0201_0603Metric (back)
};
module C7(){translate([2.580000,0.100000,1.200000])children();}
module part_C7(part=true,hole=false,block=false)
{
translate([2.580000,0.100000,1.200000])m0(part,hole,block,casetop); // RevK:C_0201 C_0201_0603Metric (back)
};
module C6(){translate([-0.429742,6.600000,1.200000])children();}
module part_C6(part=true,hole=false,block=false)
{
translate([-0.429742,6.600000,1.200000])m0(part,hole,block,casetop); // RevK:C_0201 C_0201_0603Metric (back)
};
module D4(){translate([2.500000,6.700000,1.200000])rotate([0,0,90.000000])children();}
module part_D4(part=true,hole=false,block=false)
{
translate([2.500000,6.700000,1.200000])rotate([0,0,90.000000])m4(part,hole,block,casetop); // D3 (back)
};
module Q1(){translate([0.100000,5.000000,1.200000])rotate([0,0,180.000000])children();}
module part_Q1(part=true,hole=false,block=false)
{
translate([0.100000,5.000000,1.200000])rotate([0,0,180.000000])m5(part,hole,block,casetop); // Q1
};
module C2(){translate([-1.250000,-7.100000,1.200000])rotate([0,0,90.000000])children();}
module part_C2(part=true,hole=false,block=false)
{
translate([-1.250000,-7.100000,1.200000])rotate([0,0,90.000000])m0(part,hole,block,casetop); // RevK:C_0201 C_0201_0603Metric (back)
};
module R3(){translate([-0.429742,7.200000,1.200000])rotate([0,0,180.000000])children();}
module part_R3(part=true,hole=false,block=false)
{
translate([-0.429742,7.200000,1.200000])rotate([0,0,180.000000])m1(part,hole,block,casetop); // RevK:R_0201 R_0201_0603Metric (back)
};
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

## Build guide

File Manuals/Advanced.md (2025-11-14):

# Advanced operation

There are a number of settings and commands that are available via MQTT. To use these you must have set up the device to connect to an MQTT server. You then need a means to send messages to the MQTT server for the device.

The *hostname* you picked is used for these messages. The format for commands and settings is defined in [RevK library](https://github.com/revk/ESP32-RevK). But is basically quite simple. We'll use `GuestAC` as the example hostname.

|Type|Format|Meaning|
|----|---|---|
|Command|`command/GuestAC/command`|This issues commands to the device to do something now.|
|Setting|`setting/GuestAC`|This allows settings to be set. The payload is JSON, with one or more settings. e.g. `setting/GuestAC {"fanstep":2,"reporting":60}`. With no payload the existing settings are returned in the same format.|
|Setting (direct)|`setting/GuestAC/thing`|This allows a single setting to be set, the payload is the value, e.g. `setting/GuestAC/debug 1`|
|State|`state/GuestAC/whatever`|Status messages - these are normally retained and relate to specific aspects of the operation. With no paramater, e.g. `state/GuestAC` this is the state of the device itself, with `false` meaning it is now offline.|
|Event|`event/GuestAC/whatever`|Event messages are one of things that have happened and are not retained.|
|Info|`info/GuestAC/whatever`|Info messages are informational, and don't relate to a specific event happening.|
|Error|`error/GuestAC/whatever`|Errors are reported using this.|

## Faikout auto

The *Faikout auto* logic allows a set point (with a margin) and a reference to external temperature. It uses simple prediction to see if we are going to exceed the maximum or minimum or be within range (see below), and aims to stay in range by basically turning the aircon just *on* or *off*. It does the *on* or *off* by changing the set point given to the air con to be *higher* or *lower*, in simplest terms.

However there are a few settings to control what *on* and *off* mean in this case. the simplest, default, is *much higher* than current temperature or *much lower* than current temperature, i.e. around ±6℃.

The actual set point logic set a set point, and adds `heatover` or subtracts `heatback` adjustment for *heating* or subtracts `coolover` or adds `coolback` for *cooling*. The basis for these is one of there options.

1. The default (`temptrack` off, `tempadjust` on) is your requested set point, adjusted for the air con temperature not matching your external temperature.
2. Non adjusted (`temptrack` off, `tempadjust` off) just uses the set point you have asked for as a basis.
3. Tracking (`temptrack` on) uses what the air con sees as the current temperature, allowing you to constantly nudge the aircon towards the target you want

There is also a setting hold off adjustments (e.g. when tracking) for a time period (`tempnoflap`).

### Staying in range

The auto mode has a target range, a *min* and *max*. On the web page this is set by a target and tolerance, so if you set 21℃ with ±1℃ that is a range of 20℃ to 22℃. This is the comfort zone, the range in which you would like the temperature to stay.

To achieve this the Faikout looks at the temperature and sets the heating/cooling *on* or *off* as explained above. When heating, it is basically looking to keep the temperature just above *min*, and for cooling just below *max*. Note, it it not *aiming* for the middle, just to be within the range.

When looking at the current temperature it looks ahead, as the aircon has some inertia, it samples every `tpredicts` seconds and looks ahead `tpredictt` periods. This allows it to act before the temperature goes too far one way or the other.

I simplest terms, if heating, if the temperature will be above *min* it turns off, and if it will be below *min* it turns on. However, that would simply mean a temperature hovering around *min*. To aim for somewhere between *min* and *max* it actually adjusts its target, increasing *min* by `pushtemp` (default 0.1℃) so it hovers a bit above *min*. For cooling this works the other way around and relates to *max*.

The temperature band is also used to work out if we need to reverse heating/cooling. This is where *max* comes in for heating (*min* for cooling). If we are heating but spending all the time over *max* we switch to cooling. If we are always within *min* to *max* it will turn off. Bear in mind this is based on predicted temperature, so we may be within *min* to *max* because the heating is turned on/off to keep us there, and that does not turn off as the predicted temp will have gone out of range. There is an adjustment to the switching temperature, e.g. in heating *max* is adjusted by `switchtemp`.

### Thermostat mode

You can set the `thermostat` - this changes the target we use. When not in this mode, heating aims for *min* and cooling aims for *max*. In thermostat mode heating aims for *max* until it gets there, and then lets things cool to *min* before turning back on again, adding hysteresis.

Thermostat mode also disables the `pushtemp`/`switchtemp` adjustment, and makes the default set point reference `min` or `max` depending on the current heating mode and hysteresis.

## Settings

There are a number of standard settings as per the [RevK library](https://github.com/revk/ESP32-RevK), including things like `hostname`, `mqtthost`, `wifissid`, etc. Settings specific to the Faikout module are as follows.

The web pages provide settings for the basic WiFi/MQTT, the Faikout specific settings, and an Advanced settings page listing a lot of more detailed settings.

Note that web settings can be disabled with `websettings`, and the web based control pages can be disabled with `webcontrol`. It is also possible to apply a password for the web settings 9this is not sent security, so use with care on a local network which you control).

### Automatic on/off

Auto mode can be enabled/dissbled via `autoe`.

Every `tsample` seconds the relationship of the adjusted *min*, *max* and *current* are assessed to consider how much time was *approaching* the target band, in the target band, or *beyond* the target band. Two whole samples in a row are considered. Sampling is reset on change of power or mode.

If `auto1` is set, the power on at start of that minute. If `auto0` is set, the power off at start of that minute.

If `autop` is set, and the last sample period is entirely outside the target band, and the current temperature is more than `autoptemp` degrees above or below the target band, then automatic power on.

If `autop` is set, and the last two sample periods are entirely inside the target band, then automatic power off.

### Remote

The system is designed to work with an external remote [Environmental monitor](https://github.com/revk/ESP32-EnvMon). This sends a command `control` periodically.

You can use for your own external control, which takes priority over *Faikout auto*, but you have to send the `control` command regularly.

|Field|Meaning|
|-----|---|
|`env`|Set the current room temperature.|
|`target`|Set the target temperature, either an array of *min* and *max*, or a single number.|
|`margin`|Mainly for when sending `target` as just a number, if present the *min* is reduced by half `margin` and the *max* is increased by half `margin`|

When remote working `autop` is assumed if `autoptemp` is not `0`.

### Reference temperature

In addition to the above, `env` in `control` you can set `autotopic` to subscribe to, and `autopayload` as the field name in a JSON payload in that topic, which is sent periodically will set the reference temperature.

### Special settings

Some more advances settings which you are unlikely to need to ever change.

|Setting|Meaning|
|---|---|
|`debug`|`true` means output lots of debug - notable for S21 this is one line with a set of poll responses. This also causes more fields to be polled than normal, so slower response times.|
|`dump`|`true` means output raw serial communications|
|`uart`|Which internal UART to use|
|`tx`|Which GPIO for tx, prefix `-` to invert the port|
|`rx`|Which GPIO for rx, prefix `-` to invert the port|

## Commands

|Command|Meaning|
|---|---|
|`on` `off`|Power on/off|
|`heat` `cool` `auto` `fan` `dry`|Change mode|
|`low` `medium` `high`|Change fan speed|
|`temp`|Set target temp (argument is temp)|
|`status`|Force a status report to be sent|
|`control`|JSON payload with aircon controls, see below|
|`send`|Force sending S21 message, e.g. `D62000`, can be a JSON string, or a JSON array of strings to be sent. Use \u0080 to \u00FF for high bit bytes|

## Status

Regular status messages are sent.

- `state/` topic indicate current state, and are reported periodically and on some state changes.
- `Faikout/` topic are sent, typically every minute, and intended for the `faikoutlog` command to store in a database. 
- `*MAC*/` topic are sent for HomeAssistant if enabled, and are reported periodically and on some state changes.

The setting `livestatus` causes the `state/` topic on any change.

|Attribute|Meaning|
|---|---|
|`online`|Boolean, if the aircon is connected and online|
|`heat`|Boolean, if in heating mode|
|`slave`|Boolean, set if we are not master for heat/cool and hence cannot do requested mode|
|`antifreeze`|Boolean, set if in antifreeze mode and hence not operating as normal|
|`model`|Model name, if known|
|`home`|Temperature at remote / measured|
|`outside`|Outside temperature, if known|
|`inlet`|Inlet temperature, if known|
|`liquid`|Liquid coolant feed temperature, if known|
|`control`|Boolean, if we are under external/automatic control|

The `faikoutlog` reports the last periods for values. For each value, if it is the same for the whole period it is reported as is. If not, then for numeric is reported as an array of *min*, *ave*, *max*. For an enumerated type it is the current value. For a Boolean, it is a value `0.0` to `1.0` indicating how much it was `true` in the period.

The `fixstatus` setting forces the format as if the value had changed during the period, i.e. min/ave/max array or 0.0-1.0 for Boolean.

## Aircon control

The controls are things you can change. These can be sent in a JSON payload in an MQTT `control` command (with no suffix), and are reported in the `status` MQTT JSON.

|Attribute|Meaning|
|---|---|
|`power`|Boolean, if aircon powered on|
|`mode`|One of `H` (Heat), `C` (Cool), `A` (Auto), `D` (Dry), `F` (Fan)|
|`temp`|Temperature, in Celcius|
|`fan`|One of `A` (Auto), `Q` (Night) and `1` to `5` for manual fan levels|
|`swingh`|Boolean - horizontal louvre swing|
|`swingv`|Boolean - vertical louvre swing|
|`powerful`|Boolean|
|`econo`|Boolean|
|`target`|This can be a single temperature, or an array of two temperatures (`min`/`max`) which forces Faikout auto mode|
|`env`|This is the temperature reference used for the Faikout auto mode|
|`streamer`| Boolean|

There are also settings that can impact the Faikout auto mode. These are also reported in the status messages, if not using remote `control`.

|Attribute|Meaning|
|---|---|
|`autor`|Range for automation, `0.0` means off - this sets the `autor` setting |
|`autot`|Target temp for automation, This sets the `autot` setting|
|`autob`|The name of the BLE device. This sets the `autob` setting|
|`auto0`|Time to turn off HH:MM, `00:00` is don't turn off. This sets the `auto0` setting|
|`auto1`|Time to turn off HH:MM, `00:00` is don't turn on. This sets the `auto1` setting|

For remote controlled Faikout auto mode, you typically send a `control` message with `target` and `env` in the JSON payload. This needs to be sent regularly to avoid it revertign to normal (not Faikout auto mode).

## Debug

All of the protocols are reverese engineered, and some times now things come to light and new models.

The `snoop` and `dump` and `debug` settings can help decode what is happening.

For anyone in the UK trying to reverse engineer operations using an offical remote / control, we have a small number of dual port *pass through* modules to assist with debug.



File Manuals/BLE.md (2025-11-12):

# BLE sensors

Supported temperature sensors - once BLE is enabled, these appear in the list of found sensors (on main page, unless settings are password locked).

## ELA BlueCoinT

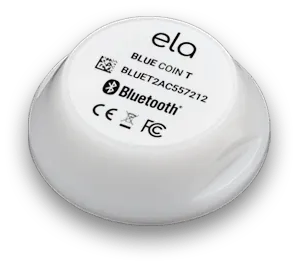
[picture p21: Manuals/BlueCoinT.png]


The ELA BlueCoinT is an industrial BLE temperature sensor from [ela innovation](https://elainnovation.com/en/product/blue-coin-t-en/). They are not cheap (€31), but are waterproof (not hot tub proof though, sorry). It is sealed and had battery build in - non changable.

I purchased some of these direct from ELA, and they arrived and were announcing temperature via BLE.

It appears with the name as printed on it, usually somethiung like `C T 802B03`, though the app allows this to be changed.

**However** I ordered some from Amazon and they were not advertising. I had to download the app and *activate* via NFC - which was very tricky as the sensor is small, so has to be in just the right place by the top of my phone.

## Telink  sensors (e.g. Mi Temperature and Humidity Monitor 2)



It seems there are a lot of very cheap sensors (£9), even with displays. Amazon sell the [Mi Temperature and Humidity Monitor 2](https://www.amazon.co.uk/dp/B08C7KVDJW). However, it seems the price can be as low as £3 from AliExpress.

It does need a CR2032 battery. But the battery is replaceable. Not waterproof.

These sensors seem to require an app, and then to be activated. The app needs a login, I nearly did not add them at all. However, it seems someone has done some customer firmware and it is easy to reflash!

The instructions are [here](https://github.com/pvvx/ATC_MiThermometer#flashing-or-updating-the-firmware-ota) and pretty easy to follow. You go to a [web page](https://pvvx.github.io/ATC_MiThermometer/TelinkMiFlasher.html), select `Connect` and find the sensor, select `Activate`, then `Custom Firmware`, then `Start flashing`. Simple as that, takes a few minutes. Note the `LYWSD03MMC` may be more complex as only accepting signed updates now.

You can reconnect (it changes its name to start `ATC_...`) but then you have loads of options.

The default `custom format` advertisement is understood. The device will appear with its MAC address as its name. If you use Home Assistant, BTHome and BTHome2 advertisement are also understood by Faikout and will be recognised automatically in HA so it may be worth sending BTHome/BTHome2 config while you have the Telink paired.

## GoveeLife



There is support for one of the [GoveeLife sensors](https://www.amazon.co.uk/gp/product/B0CDX6SNJ3/).

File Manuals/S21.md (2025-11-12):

# Daikin S21 protocol

The Daikin has an `S21` and `S403` port which talks the `S21` protocol. This is not documented by Daikin, and so all of this document is based on reverte engineering and testing.

- The protocol has a common format, but the exact messages and features are not the same from model to model, so not all work on all models.
- The reverse engineering is far from complete, and may have errors, but the idea is to update this document, and in particular to cover the usage of `S21` protocol by the Faikout code.
- Some settings are in more than one place, so different on different models!

# Physical

The physical interface is basic serial data, low is `0`, high is `1`. However the Daikin appears to operate with a 5V internal pull up on Tx and Rx lines, and a pull down. The Faikout uses a FET each way, which means internally the lines are inverted.

The `S403` port is a *non-isolated* `S21` port, i.e. it is at **MAINS POWER** levels, and dangerous. Any connected device, such as a Faikout, needs to be inside the case.

The `S21` port pin out is 1:1 the same as the Faikout pin out :-

|Pin|Meaning|
|---|---|
|`1`|5V reference. If connected to the Faikout, it is used as a pull up for Tx line. Not always connected.| 
|`2`|Tx (from aircon)|
|`3`|Tx (to aircon)|
|`4`|Power, notionally 12V, used to power the Faikout. Faikout can handle 4V to 35V.|
|`5`|GND|

Note that pin 1 is usually marked with a triangle/arrow, and unusually it is not GND.

# Data packets

The serial data is 2400 Baud, 8 bit data, even partity, 2 stop bits.

The packet format uses ASCII a lot, but not entirely. The payload design avoids clashes with STX/ETX for example. The basic packet format is :-

||Example packet|
|---|---|
|`02`|STX (start of packet)|
|`46`|First byte of packet type, e.g. `F`|
|`51`|Second byte of packet type, e.g. `Q`|
||Additional bytes of payload, normally none or 4 bytes/characters, avoiding `00`-`1F` bytes by design|
|`97`|Checksum|
|`03`|ETX (end of packet)|

The checksum is the sum of all bytes after the initial `02` STX byte, to end of payload. But if this is ETX (`03`) then ENQ is used instead (`05`). This avoids ever seeing ETX (`03`) within a packet.

The payload is empty for some simple poll requests, and in almost all other cases is 4 bytes/characters.

The other end then sends an ACK (`06`) byte if OK, or NAK (`15`) if not OK.

# Data formats

The 4 byte/characteer payloads are used to convery various types of data.

## Simple characters

- Simple number, e.g. a character `0` to `7` for a status, each number having a meaning.
- Value coding, e.g. a character `@`± value, e.g. for temp `@` is 18.0℃, `A` is 18.5℃, but can also be negative, so `?` is 17.5℃
- More complex valuue, e.g. fan speeds can be `3` to `7` but also `A` or `B`
- Bigger number, e.g. a character ` ` (space) plus value 0-100 for *demand*|

## Bits/flags

In some cases the character can contain bits. This is based on `0`. This allows bits 0, 1, 4, 5, 6, or even 7, to be used based on `30` (`0` chartacter).

## Numeric decimal

In some cases a numeric value is conveyed as 4 characters, but they are backwards, and have a `+` or `-`, so `581+` means `+185` which means 18.5℃. There are also cases where this is just a value, e.g. `001+` may be 100° angle of a vent.

## Numeric hex

In somde cases a numeric value is hexadecimal, and again backwards, so `25A3` means `0x3A52` which is 14930.

# Request/response

The general operation is that the controller sends a message (which gets an ACK), and the aircon sends a response message (which the controller ACKs).

The request can be a simple poll for data, which gets a status response message, or could be a command to change a value.

# D/F/G commands

The commands starting `F` are used to poll for responses starting `G`. However you can also send a command starting `D` to set the value. The format for the `G` response and `D` command are the same. These are generally *settings*, but in some cases *sensors*.

Using `D` to set a value results in next `F` poll returning the `G` response with the new value. However, in some cases the selected value cannot be accepted by the aircon, in which case it is not returned as new value. It may be returned as old value, or may be limited, e.g. setting a target set-point out of range will usually end up set to the *max*/*min* that is allowed. It is also possible for settings to change independantly, e.g. via IR remote, etc.

||`D`/`G` Meaning|
|---|---|
|`1`|Main control mode: power/mode/set-point/fan|
|`3`|Auto start/stop logic|
|`5`|Swing/vents|
|`6`|Additional settings: powerful mode|
|`7`|Additional settings: Econo mode|
|`9`|Course temp measurement: inside/outside|
|`H`|?|

# R/S commands

The commands starting `R` are used to poll for responses starting `S`. These are normally *sensors*.

||`S` Meaning|
|---|---|
|`H`|Inside temp|
|`a`|Outside temp|
|`X`|Set point temp|
|`N`|? another temp|

# Payloads

The following are the known payloads. Where settings have more than one place (e.g. econo) you can usually work it out on basis that one of the controls does not exist (NAK) and the other does. So you can tell based on which `D` commands work and which do not.

||Byte 0|Byte 1|Byte 2|Byte 3|
|---|---|---|---|---|
|`G1`|Bit 0: Power on|Mode|Set point (`@` based)|Fan mode|
|`G3`|Bit 1: Powerful|
|`G5`|Bit 0: V-Swing, Bit 1: H-SWing|
|`G6`|Bit 1: Powerful, Bit 6: comfort, Bit 7: Quiet|Bit 7: Streamer||Bit 3: Sensor, Bit 2+3: LED|
|`G7`|Demand ('0'+*0-100*)|Bit 1: econo|
|`G9`|Home temp (`@` based)|Outside temp (`@` based)|
|`GM`|Hex, Wh total energy usage|
|`SL`|Fan rpm, numeric (multiply by 10 for rpm)|
|`Sd`|Compressor rate, numeric|
|`SN`|Vertical swing angle|
|`SH`|Home temp, numeric (0.1℃ steps)|
|`Sa`|Outside temp, numeric (0.1℃ steps)|
|`SI`|Liquid temp, numeric (0.1℃ steps)|

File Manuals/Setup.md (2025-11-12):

# Faikout - set-up

The *Faikout* is a small circuit board that can replace the common Daikin air-con control WiFi modules.

- Local web control over WiFi, no cloud/account needed, no Internet needed
- MQTT control and reporting
- Integration with Home Assistant using MQTT

## Installation

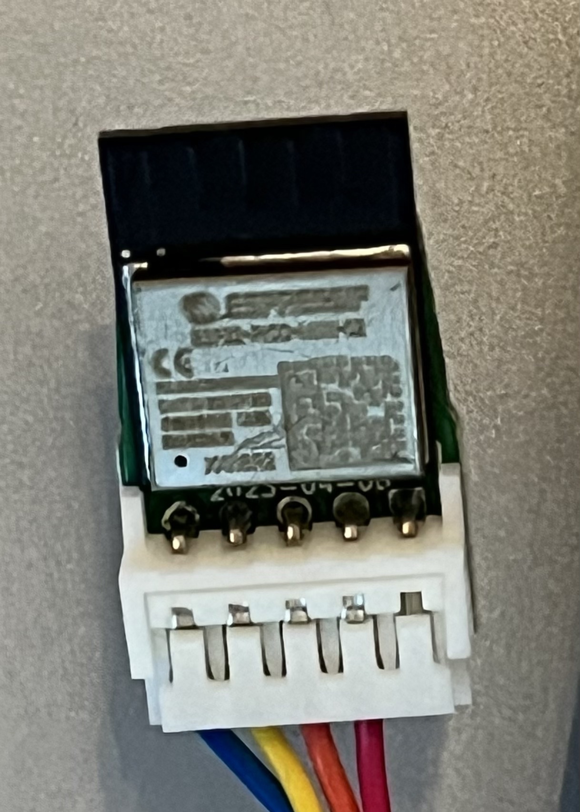
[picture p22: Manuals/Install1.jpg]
The latest boards have the 5 pin connector to match the plug for the official Daikin WiFi modules. Simply plug in.

However, you do need a lead, and Daikin charge a lot for these. Typically it will be an S21 lead. However customers have reported simple header wires (i.e. wires with sockets on each wire intended to go on 0.1" pitch headers) work just as well. You need to locate the GND, Power, Tx, and Rx pins on the S21 connector and connect appropriately as marked on the PCB. The board is designed to handle 4V to 40V power, and the air-con typically provides 12V.

A 3D printable case design is included on GitHub.

## LED

There is an LED on the module. It is possible to disable it with a setting, e.g. `setting/GuestAC {"blink":[0,0,0]}`. Otherwise it blinks a colour.

If `dark` is set, then only loopback or offline show, otherwise the LED is off.

|Colour|Meaning|
|----|-----|
|Green solid|Startup (first few seconds)|
|Red|Heating (heat or auto mode)|
|Blue|Cooling (cool or auto mode)|
|Orange|Fan mode|
|Cyan|Dry mode|
|Yellow|Power off|
|Magenta|Daikin is offline|
|Red/Green/Blue|Loopback test|
|White|Rebooting|
|White/Red|No wifi config|
|White/Blue|AP+sta mode|
|White/Cyan|AP mode|
|White/Magenta|No wifi on|
|White/Yellow|Link down|

Note that the loopback is useful for testing, a simple link from Tx to Rx will set loopback and flash LED in a repeating sequence red, green, blue, testing the Tx, Rx, and LED are all working as expected.

## WiFi set up

Once installed, the LED should light up and blink.

Look for a WiFi Access Point called Daikin (or Faikout), e.g.

WiFiAP

Select this and it should connect, needing no password.

WiFiAP

On an iPhone this should automatically open a web page. On other devices you may need to check the IP settings and enter the *router IP* in to your browser. The page looks like this.

WiFi

Enter details and press **Set**. Setting a *Hostname* is a good idea so you can name your air-con. For HomeAssistant you will probably need an MQTT username and password. If not in the UK, please look up the *timezone* string needed in the link provided.

### Hostname

Pick a simple one work hostname to describe your air-con, e.g. GuestAC.

### SSID/Password

Enter the details for your own WiFi. You will note a list of SSIDs that have been seen are shown - you can click one to set the SSID to save typing it. Make sure you enter the passphrase carefully. If the device is unable to connect the page should show an error and allow you to put in settings again. Only 2.4GHz WiFi is supported, and some special characters in SSID may not be supported.

### MQTT

If using MQTT, which could be Home Assistant running MQTT, enter the hostname or IP address of the MQTT server.

In addition you will usually see the option for an MQTT *username* and *password* - these are usually needed if using Home Assistant MQTT server. You can add a user on Home Assistant and then enter the details here.

## Accessing controls

Once set up, the device connects to your WiFi. From the same WiFi you should be able to access from a web browser using the hostanme you have picked followed by `.local`, e.g. `GuestAC.local`.

The controls page shows the controls for your air-con, and also has a link for *WiFi settings* allowing you to change the WiFi and MQTT settings if needed.

# Software Upgrade

We recommend you upgrade the software when you receive the device, as new features are often added.

Go to the web page, and select *WiFi settings*. You can click on *Upgrade*. This does need internet access.

## Re-flash Firmware

If you've forgotten your login credentials or, for some reason, you are denied access to the settings page, you will need to reflash your device.

### Prerequisites:

- A USB to serial converter (such as this one: Amazon Link or Tasmotizer-PCB).
- Some Dupont wires.
- Download the correct firmware binaries for your device (PICO, S1, or S3) from this link.
- Note that newer boards may need a TC2030 lead for USB instead

### Connection
Connect the USB to serial converter according to this pinout diagram::
357787461-10591127-4cfe-4293-a29b-56408e83f4b8

### Erase Flash
Run the following command in the shell::

``` 
esptool.py --chip esp32s3 erase_flash
```

### Flash the New Firmware
Run the following command in the shell (for S3 chip):

```
esptool.py -p /dev/cu.usbserial-A50285BI write_flash 0x0 Faikout-S3-MINI-N4-R2-bootloader.bin 0x8000 partition-table.bin 0xd000 ota_data_initial.bin 0x10000 Faikout-S3-MINI-N4-R2.bin
```

or (for S1 chip)

```
esptool.py -p /dev/ttyUSB0 write_flash 0x1000 Faikout-S1-PICO-bootloader.bin 0x8000 partition-table.bin 0xd000 ota_data_initial.bin 0x10000 Faikout-S1-PICO.bin
```

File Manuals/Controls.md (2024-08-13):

# Web controls

The web controls can be accesses using the name that has been set, we'll use `GuestAC` as an example. So visit `GuestAC.local` as a web page.

Example

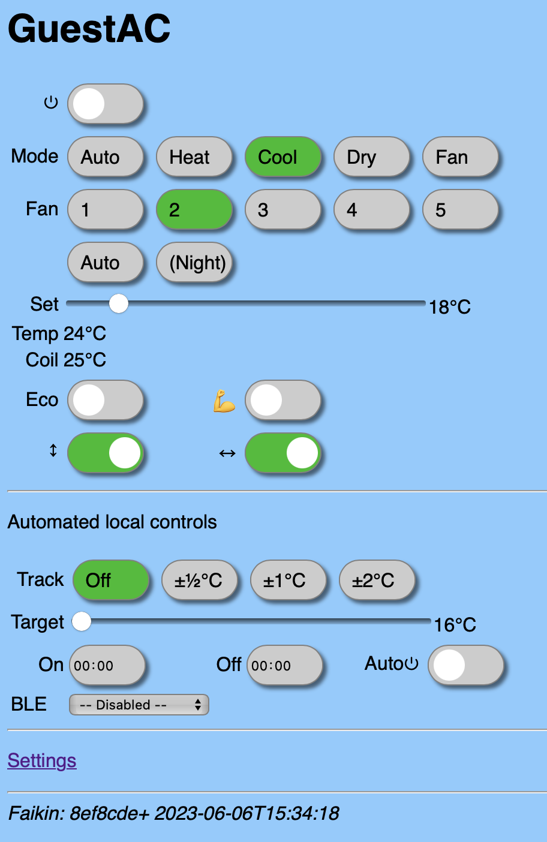
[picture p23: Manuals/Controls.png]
Controls


## Main operation

The first section coverrs teh direct controls and status for the air-con unit. the exact options depends on the units and settings.

Making changes has immediate effect, and changes by other means, such as IR remote, show immediately (within seconds).

## Automated controls

The automated controls allow a separate layer of controls to be applied. These work by setting "Cool" and "Heat" as needed to achieve a desired temperature, much like the air-con's own "Auto" mode. But with more options.

The "Track" setting, if not "Off", enables the auto setting of *heat* and *cool* modes to aim for a target within a range.

The "Target" is the target temperature. You will see the "Set" in the main controls change to be many degrees below or above the target at various times to *aim* for the target.

The "On"/"Off" times can be set. If not `00:00` (midnight) then they cause the air-con to turn on, or off, at the time specified. Note, you may need to ensure the correct timezone in *settings*. Each is disabled by setting `00:00` (midnight) or setting both to the same time.

The "Auto⏻" control enables automatic *on*/*off* based on temperature. If well outside target range and off, it turns on. When inside range for a time when on, it turns off.

## BLE

The *Target* uses the air-con's own temperature sensor normally, but if you have a BlueCoinT BLE or Telink sensor you can select that as an external reference. This allows the room to be controlled based on a sensor that may be by your bed or where your sit.

For more about sensors, see [here](BLE.md).

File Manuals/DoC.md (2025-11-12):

# Compliance statement

The Faikout hardware is an open source PCB design in this repository, and so you can make it yourself. However, we (Andrews & Arnold) do have the boards made and imported and we sell them.

# Not a product

*CE/UKCA*: What we sell is very specifically an "assembled PCB", a "component", and not itself a "finished product". It has no case, leads, or power supply. You need to snap out of the PCB panel. Whilst the system on chip has a CE mark in itself, we don't make any CE/UKCA conformance statement for this as a product as it is not a product. If someone sells/installs air conditioning units with these modules then the whole thing is a product and they need to ensure compliance with legislation.

*Other regulations*: It is unclear if the UK law: [The Product Security and Telecommunications Infrastructure Act 2022](https://www.legislation.gov.uk/ukpga/2022/46/contents), and [The Product Security and Telecommunications Infrastructure (Security Requirements for Relevant Connectable Products) Regulations 2023](https://www.legislation.gov.uk/uksi/2023/1007/contents/made) apply here or not. As we say, it is not a "finished product". However, just in case it does apply, this statement is an attempt to meet the requirements.

As the Faikout hardware can be made and distributed by anyone, obviously, if they make it, they have to consider compliance, so this statement only applies to cases where we (Andrews & Arnold) have made the Faikout hardware, or distribute it.

# The product (if somehow it is deemed a product)

As the Faikout hardware is a general purpose module / circuit, it only really makes sense to make any statement about it "as supplied", which is with the Faikout software pre-loaded for your convenience.

If you choose to load any other software, or even build a variation of the Faikout software with your own (or someone else's) changes, then it is no longer "as supplied", and you now have a different "product" (if it is a "product") that you have made, so compliance is then up to you.

It may be that the regulations also apply to the Faikout software even when loaded on your own hardware, this too is not entirely clear, or entirely clear which country's laws would apply, especially as that typically means you "build" the software yourself (so is it your software now, built in your country, from a regulatory point of view?).

The code is also in a fork built for ESP8266, and may be in any number of other forks. Obviously I cannot make any statement for those forks, or clones, or copies based on this code.

# Type/batch

So, the "product" (if it is one) is the software on this repository, all batches and builds, on the Faikout hardware made and supplied by Andrews & Arnold, and "as supplied", or as updated from this repository or OTA server.

# Who

The software is made by Adrian Kennard, and other contributors. However, I can only speak for me (Adrian Kennard), I have no idea if any and all contributors also need to make a compliance statement, sorry.

When Andrews & Arnold manufactures and distributes boards, its name is "Andrews & Arnold Ltd", UK company 3342760, and its registered office address is Enterprise Court, Downmill Road, Bracknell, Berkshire, RG12 1QS.

# Statement made by manufacturer

The hardware covered here is made by/for Andrews & Arnold. This statement is prepared by Adrian Kennard, director Andrews & Arnold, on behalf of the "manufacturer".

# Compliance

It is the opinion of the manufacturer that we have complied with Schedule 1 & 2, and 5.1-1 of ETSI EN 303 645. Specifically that where passwords are used, they are user specified, and that we have a vulnerability disclosure policy, etc.

- Normal web access to controls for your aircon on the Faikout have no passwords.
- Access to settings can have no password, or can have a user specified password.

# Vulnerability disclosure policy

Please raise any security issue on this GitHub respository. I would expect to reply promptly but at the very least within one month, and will provide any status updates on the GitHub issue. As this is free software with no contract or warranty, saying I'll reply in a month is not a contractual statement. In practice I usually reply within hours.

Please note that not all *issues* are *security issues*, and this policy applies only to "security issues".

# Support / updates

Updates are made available via this repository. I also provide an OTA server, with full and beta releases. Some older code did not auto update but allowed manual updates, however, these days, auto updates are enabled by default.

The ultimate place to get the latest code, with any security updates, is this repository.

# You can help

Not something the legislation seems to consider, but I am also happy to consider merge requests that address a vulnerability.

# Support period

I plan to continue to support this product until I get bored, or drop dead, whichever is sooner. I expect that to be many more years.

# Issued

The place this was issued? Well, err, this repository, issued on 2024-03-14 (Pi day). Though check the GPG signature for definitive date/time.

Failing that, it was issued from my computer, in Wales.

# Signed

See [signature](DoC.md.asc).

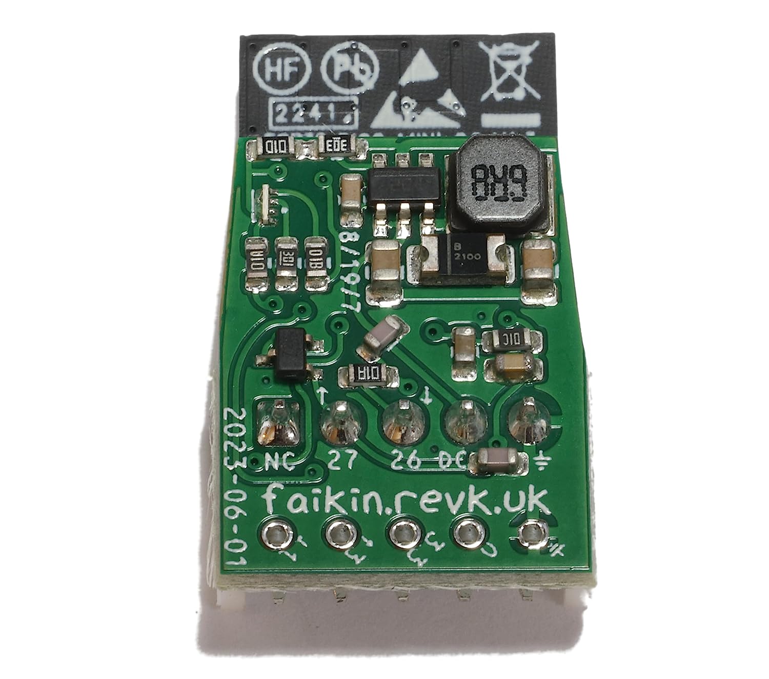
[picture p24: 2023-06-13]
Manuals/Board.jpg

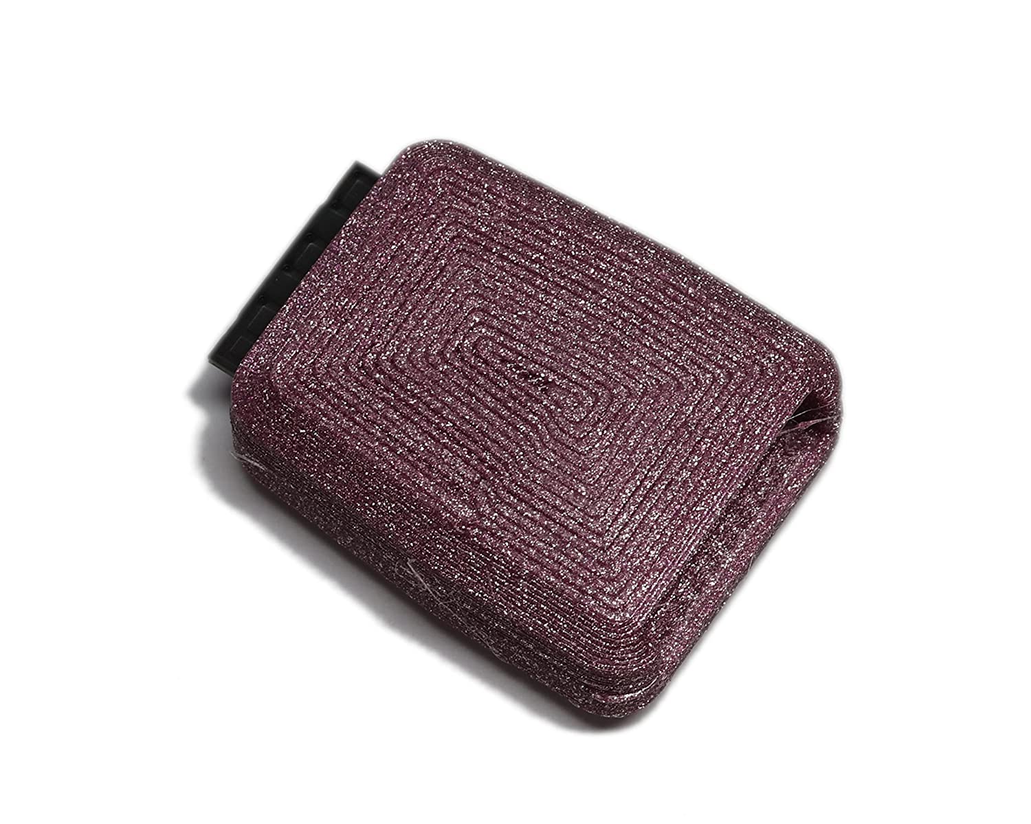
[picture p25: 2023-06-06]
Manuals/Cased.jpg

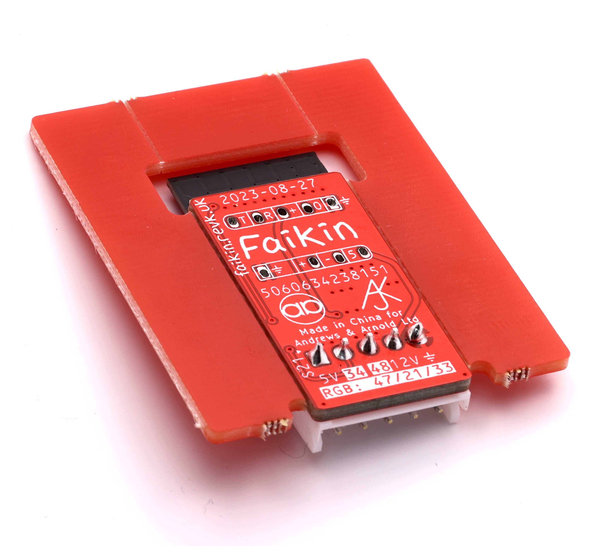
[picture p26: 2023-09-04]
Manuals/knockout.jpg

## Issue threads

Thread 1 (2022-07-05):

Will it be possible to purchase this board?

msx80, 2022-07-05:
Hi there, i'd really love to have one of these boards. Are you planning on selling some of them?

Thank you!

revk, 2022-07-05:
I have a few prototypes, but getting components is a nightmare. When we can get components we expect to sell, yes. Are you in UK, if so I could post you a one of the prototypes maybe, for some feedback…

Boki3333, 2022-07-16:
> I have a few prototypes, but getting components is a nightmare. When we can get components we expect to sell, yes. Are you in UK, if so I could post you a one of the prototypes maybe, for some feedback…

Hey mate.
May i ask you , what is your email to contact you ?

revk, 2022-07-17:
I don't usually give out emails, but tweet at me and we can DM.

Boki3333, 2022-07-17:
> I don't usually give out emails, but tweet at me and we can DM.

I do not have tweeter, facebook, nothing .. (
I see also here its not possible to sent messeges....
I am modern, but still not as modern to be everywhere.
I use either mail, or apps for chat.

Please send me email on : moja.poraba@gmail.com

Thank you in advance.

Boki3333, 2022-07-17:
> I don't usually give out emails, but tweet at me and we can DM.

First question : Which element is to be choosen for onboard connector from AC to the module ?
                         I am searching this onboard right-angle male plug, but i am not able to find it.
                         I am using EasyEda, to do module based on your published schematics.
                 
 Second question : Why Rx signal acts as " reversed " ? Is there any specific reason behind this ?
                              It has to be reversed constantly or the reason is ESP32 module ?
                      
 Third question : Since i do not see any benefits in ESP32, and my whole home is automated based on Esp8266, probably
                           i could do the same module, only with Esp8266 instead of ESP32, correct ?
                           And those " rgb " lights are actually not needed for me, so i would remove them.
                           I will check more in detail, why those RGBS are for, but in my case not needed.
                   
  THANK YOU in ADVANCE for your replies and your help.
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

revk, 2022-07-18:
1. The RGB LED is just for show, it is on most of my boards and in this case shows cooling/heating, so not needed.
2. The Daikin units I have already have a lead, and it has a connector that plugs in to this (5 pin connector but only 4 pins used). I believe on most of them the PCB side is called S21, and you need to set the s21 flag in the settings in my code for that as I have not yet made it automatically detect.
3. No reason you could not do this on an ESP8266, it is just serial comms - but the code is all designed for ESP32, so no idea how difficult it would be to make it compile for an ESP8266, sorry. I'd suggest an ESP32 would be easier.
4. The Rx uses a FET because the Daikin is 5V not 3.3V. For Tx, sending 3.3V to the Daikin works and is safe, but for Rx it is not ideal for it to be 5V in to the ESP. I works, but using a FET is a better way to do it, and has the side effect of inverting the Rx signal. My code is designed to allow inverted or non inverted GPIO for Tx or Rx so not a problem if you make a circuit that is not inverted.
5. I do have a load of spare unpopulated PCBs if you want me to post you one.

Boki3333, 2022-07-19:
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

Hi.

Thanks for all the answers, i appreaciate it, and it makes things clearer to me.
Please look at my number 2 more accurately, so that i could solve it :)

1 ) Ok, i understand.
3) Yes maybe can be easier, but Esp8266 has enough of the " needed capacity " for this work. So yes,
    this code will have to be compiled - rewritten for Esp8266. So this means work work work work......
4) Yes, i know, that 5V tolerancy on pins for esp8266 are ok, but not ok, if you understand what i mean. Its quite
    an interesting way of " solving " this tollerancy, and leaving it for RX. I was thinking about putting rather
    a 10k resistor , so that RX pin would be connected on 1 side and then on other side 5V from voltage converter.
    Maybe that should do the work also, what you think ? But since it works with this FET, and the side effect is " inversion " ,
    probably i should leave it.... You think so ?
5) You mean by " unpopulated " as not assembled and for ESP32 ? Is this what you mean

And here is this nr.2 , that i do not have answer for yet :
S21 - i am not able to find in EasyEda. There is so many different parts, i had to focus on the ones, that i am assuming
will fit.
Here are few examples  - much appreciated for your cconfirmation :
a) https://datasheet.lcsc.com/lcsc/1810222341_Ckmtw-Shenzhen-Cankemeng-W-2510R05P-F000_C169030.pdf
b) https://datasheet.lcsc.com/lcsc/1810221937_BOOMELE-Boom-Precision-Elec-C61410_C61410.pdf
c) https://datasheet.lcsc.com/lcsc/1810221710_BOOMELE-Boom-Precision-Elec-C45012_C45012.pdf ( looks excatly the same
    as the previous one )

Boki3333, 2022-07-19:
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

Look, here are attached pictures from the Module, and from the cable.
And those parts do not look like molex to me, neither similat to the one i have choosen, because
in my " chosen parts " there can not be any " click " sound , because are unshielded from the side.
What you advise ?
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

revk, 2022-07-19:
Odd, there were additional comments on here but not showing now. The connector on the board is 4 pins, and could be simple 0.1" molex style pins which will fit in the 5 pin socket on the end of the remote control lead, if that makes sense.

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
.

Boki3333, 2022-07-21:
> Odd, there were additional comments on here but not showing now. The connector on the board is 4 pins, and could be simple 0.1" molex style pins which will fit in the 5 pin socket on the end of the remote control lead, if that makes sense.
>
> 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 .

Hey there.... Been busy with the module.
Yes, i see that comments are not showing ? What is this ?
Well, i have found the correct connector. Its from JST, and also i have managed to do the module, based on Esp82, because as i said , esp32 is not needed.

Here is a picture of a module, i created.

What you think ?
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

It fits perfectly into Daikin unit :)

Boki3333, 2022-07-25:
> Odd, there were additional comments on here but not showing now. The connector on the board is 4 pins, and could be simple 0.1" molex style pins which will fit in the 5 pin socket on the end of the remote control lead, if that makes sense.
>
> 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 .

Hi there.
I hope this reply and request will stay, and will not be gone.
I had almost no time to get back, i was completely busy with some work.
May i ask you few more questions about the design ?

1) You wrote on schematics " TX and RX " pins, when actually you used on ESP32 not TX and RX pins, but GPIO26 and GPIO27 .
    This is a bit confusing to me, because you marked original TX and RX pins differently. I dont get this.
    Is this TX or RX used for connection to Daikin or i am missing any point  ?
2) Colors of the wires are assigned as my assumption is :
    BLUE - GND
    YELLOW - Power
    ORANGE - TX
    RED - RX
3) If my assumption is correct, please help me out witht he correct connections :
    ORANGE - TX   goes on TX pin on ESP ?
    RED - RX goees on RX pin on ESP ?
    Am i right or is it turned around as :
    ORANGE - TX  goes on RX pin on ESP ?
    RED - RX goes on TX pin on ESP ?
4) Why you used regulator Vin / 4V -60 for mains and then Vout 5V ? Daikin Vin is higher then 5V ?

Thank you very much in advance for your answer .

revk, 2022-07-26:
1. The ESP32 can assign Tx and Rx on any of the three UARTs to any GPIOs. I have assigned those to the communications with the Daikin module. The "default" tx and rx on UART 0 are assigned to the 5 pin pads (J2) for programming.
2. The schematic shows the order of J1: GND, DC Power, Tx (to Daikin),Rx (from Daikin). Looking at your cable, and mine, that is Blue, Yellow, Orange Red, yes.
3. As per the schematic, with arrows on the tabs even, the third pin is Tx *to* Daikin, forth is Rx *from* Daikin.
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
msx80, 2022-07-27:
Hi all, in the end i went ahead and made myself a board, out of off the shelf components. They're a bit bigger but still fit the slot quite nicely. Seems to work well, i've done 3 now and the first is up for more than a week without issues.

For the software, i used Tasmota to handle all the basic configuration/http/mqtt stuff, and i wrote driving code with Berry (tasmota esp32 scripting language).

If anyone is interested, sources and pictures are at https://github.com/msx80/FakeA41

revk thanks again for your kind offer and for the informations you made available on this repo!

PS at 2400 baud the ESP32 is more than fast enougth to drive the serial with software, which i did on my project so you can choose any two pins

boehla, 2022-09-17:
> I have a few prototypes, but getting components is a nightmare. When we can get components we expect to sell, yes. Are you in UK, if so I could post you a one of the prototypes maybe, for some feedback…

Hello revk, are you selling devices now? Would be interested in one device. I am from AT.

revk, 2022-09-17:
Once components are available I plan to have some made up and sold on Amazon, but that is not likely before next year at this rate, sorry.

boehla, 2022-09-17:
> Once components are available I plan to have some made up and sold on Amazon, but that is not likely before next year at this rate, sorry.

Ok thanks for the info :)
With the KiCad folder it should be possible to order an already assembled pcb?
Otherwise I can wait.

revk, 2022-09-18:
Well yes - making a BOM for your supplier may need a bit of editing but all the details are there.

nightwatcher74, 2022-09-18:
Hi revk,

at first... I'm an absolute ESP32 beginner... :(

What do you think, would it be possible to user an M5Stack Atom Lite Module for the Daikin integration??
https://shop.m5stack.com/products/atom-lite-esp32-development-kit
(The Grove Pins G26/G32 are 5V)

There is also an 6-24VDC => 5V available:
https://shop.m5stack.com/collections/m5-accessories/products/5v-buck-converter-unitme3116am6g

when i understand it correctly, it should be possible to connect in the following scheme:

Daikin     => ESP32
 V+         => PowerConverter +
GND       => PowerConverter -
RX           => G26 (Grove Pin)
TX           => G32 (Grove Pin)

is it possible to run ESP32-Daikin in such an environment??

Thanks
Frank

revk, 2022-09-19:
It should run on any ESP32. The make file has builds for solo ESP32 even, ESP32 PICO, and ESP32 WROOM. And you can configure the GPIOs to use over MQTT.

mx5gr, 2022-09-24:
@nightwatcher74  I am interested in this as well, i.e. using a M5 Atom Lite (for small size) and a buck converter.

However, the GPIOs of the Atom are at 3.3V. Isn't a level shifter required as well since the Daikin serial I/O operates at 5V (if I am not mistaken)?

revk, 2022-09-24:
You can get away with it, but in my design I added a FET to do the level shift on input. On output the Daikin is happy with 3.3V to its input.

mx5gr, 2022-09-24:
I am thinking of powering the Atom through the USB connector and use a readily-available level shifter, such as https://www.sparkfun.com/products/12009 (High side the Daikin 5V supply and as channels the two respective lines, Low side the 3.3V coming from the Atom and 2 respective GPIO lines).

I am thinking of a bidirectional connection. If Daikin is happy with 3,3V as its input, the ESP32 might not be happy with the 5V coming from the Daikin unit to its respective GPIO input.

In that sense, not even a buck converter is required... that is, if my assumptions are correct :) :) :)

Closed 2022-12-30.

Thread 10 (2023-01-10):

Automatically work out if S21

revk, 2023-01-10:
Try initial comms as S21 or not and work it out, rather than a config.

antonsb, 2023-01-11:
Does this means that S21 socket interconnection may be supported as well?
Currently my BRP069C4X has very small connector that i have problem to find online as well as connect pins to it without cutting the wire - thus voiding warranty on the unit. But there is a free S21 slot

revk, 2023-01-11:
There is an MQTT based setting for S21 mode, but I really should make it auto detect some time. Both types of unit I have had a WiFi connect lead and the Daikin WiFi so was easy.

antonsb, 2023-01-11:
lead goes to mine as well, but it's small JST SHJ 1mm pitch type connector (on both sides).On PCB it does not connect to S21,but to some other port module looks like this:
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

antonsb, 2023-01-11:
If it worked from S21,it would be much easier (at least for my case) to make custom wire harness, then to hunt down that small connector.

revk, 2023-01-11:
I can look in to making it auto detect soon. But I can probably sort a make menuconfig for S21 in the mean time. Probably in the morning.

antonsb, 2023-01-11:
Damn that's fast. I just ordered JST EH for S21 from Ali, not sure when they will arrive and i will be able to test this.

revk, 2023-01-11:
Well I hope it works. I'll let you know when I have tested.

revk, 2023-01-12:
I have added the S21 setting to make menuconfig now. Like the other settings this is just the default and can be overridden using MQTT, but it should allow you to build an S21 based build to try.

antonsb, 2023-01-12:
build seems to be working for me with S21 option, i would check functionality next week as i will get some connectors for cabling

revk, 2023-01-20:
Ok not working very well...

revk, 2023-01-20:
It seems to be working well now, and clean from power up as well.

Only concern is the non S21 model could, with a lot of poking crap at it, get in to a state of just reporting errors. This may mean we need a null header or some such. Something to consider if the problem is seen in the wild.

Closed 2023-01-20.

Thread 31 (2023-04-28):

Is an external temperature source supported?

matt-nz, 2023-04-28:
Firstly thanks for the great project, since I couldn't order the PCB not being in UK I built a very simple version using just an ESP32 and 32pin dev board which handles the 12v power conversion. I learnt that ESP (and experienced in previous projects) can handle 5v on input pins so didn't even use a level shifter (Just removed the use of invert on TX). I then used dupont wires to connect to the S21 port ran those out of the metal shielded areas and taped internally on the side. All working great so far and discovered in HA.

Anyway my question was I was looking at the docs and code and I see there is support for an external remote [Environmental monitor]. Can I just a sensor for my home assistant and get HA to send a temp update when it changes? I tried using MQTT on topic `command/heatpump/control` with a payload of
`{
  "env":"22"
}`
but didn't seem to work as expected, instead it looked like auto control was activated and a scale of builtin / external being applied.

I just want to change the temperature source to be external rather than the heatpumps inbuilt is that possible with the current build?

revk, 2023-04-28:
Basically it handles some specific MQTT messages from the other sensor. I may even have documented them now.

But also can now handle a BlueCoinT BLE temperature sensor directly, which seems to work very well.

revk, 2023-05-28:
The external temp logic only works by the Faikin controlling the settings hight/low, it is not possible to tell the Aircon the external temperature itself sadly (that would be nice), so sending external control temperature tells it to take control, setting heat/cool/fan accordingly. This means you need to send target too as the Faikin can no longer rely on the target from the Aircon itself as that would need to be set high/low to control it.

An example of the external control is:

`command/GuestAC/control {"env":22.00,"target":[16.000,32.000]}`

Closed 2023-05-28.

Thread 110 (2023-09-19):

Work With ESP-Home

fantasiataiwan, 2023-09-19:
Can Faikin work with ESP-Home?

revk, 2023-09-19:
The hardware is just an ESP32 with serial at right levels. If esp home can run on ESP32 and handle inverted UART to a Daikin then I see no reason why not. You would need a suitable serial lead to load code (see Tasmotiser).

joshbenner, 2023-09-19:
I use [esphome-daikin-s21](https://github.com/joshbenner/esphome-daikin-s21) on a Faikin board. README there includes the config I use for dealing with the serial invert.

fantasiataiwan, 2023-09-28:
I tried to flash esphome and your v1.bin but it's not working.
I haven't see the hotspot SSID maybe I have something wrong haha.

revk, 2023-10-28:
The board is pretty generic, so maybe raise this with the esphome designers. The schematic for this board is published.

shikousa, 2023-11-26:
@revk What is the reason that your board is inverting the TTL-UART?

revk, 2023-11-26:
The reason is down to the fact the Daikin works at 5V. Using a FET each way is an inexpensive solution to allow that to work with the 3.3V of the ESP32. It has the side effect of inverting, but as the ESP32 has hardware tx/rx invert options it is no problem.

shikousa, 2023-11-26:
I was thinking of an ADUM1201 to also get isolation. There is the 3,3V from the ESP32 for VDD1 of the ADUM1201. On PIN1 of the S21 socket is there always 5V? This would be for VDD2 of the ADUM1201. Then the ADUM1201 might also be an approach, what do you think?

revk, 2023-11-26:
Most 3.3-5V converters expect a 5V supply. The issue is the Daikin units and wiring vary so I can't be sure to always have a 5V available. It does seem the signal to the Daikin does have internal pull up though, so this circuit has been found to work well.

shikousa, 2023-11-26:
In your schmatic you take PIN1 for having the 5V for PIN3 (RX). What if these 5V are not available?

revk, 2023-11-26:
Yes, that is just in case. What seems to be the case is the data to the Daikin always has a pull up, so just the FET pulls down. And sometimes there is 5V (not on my units, for example). By having both there is a good chance of it working with all models (that have S21 or X50A). So far it seems to be working well.

shikousa, 2023-11-26:
Thanks. It would be interesting how other gateways have solved this. The Zennio KLICDDv3 has KNX, actually it should have a galvanic isolation.

revk, 2023-11-26:
I did not consider isolation necessary, but I understand some Daikin have non isolated S21 like ports but they then sell an adaptor to isolate. It would obviously be more complex to add isolation.

shikousa, 2023-11-26:
The power consumption of an ESP32 is pretty high, recommended is a supply with 500mA. Do you know if PIN4 (>5V) can deliver this long term.

revk, 2023-11-26:
My understanding is that the 5V cannot deliver the power needed.

shikousa, 2023-11-26:
Yes, but you are using PIN4 with e.g. 12V. Do you know what this PIN can deliver?

revk, 2023-11-26:
We have had no problem with the 12V (often reported and 14V, or some such) powering the ESP32.

Closed 2023-10-28.

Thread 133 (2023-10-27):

BLE Device (show all temps on web page)

ckvsoft, 2023-10-27:
I would be interested to know how Faikin gets the BLE data. Is this queried directly via Bluetooth or in the mqtt broker?
The strange thing is,
In Faikin "none" was always offered as a choice. Thereupon
I installed ESP32-BLE-Env on an ESP32. This was apparent relatively quickly in the mqtt broker. In Faikin it took a while until he was available for selection.

Now I sent the same values   to the mqtt broker via my Raspberry with onewire sensor. However, this data is not recognized by Daikin. What are you looking for/filtering for here?
I turned on the ESP32-BLE-Env for testing purposes and the BLE entry remains in Faikin. Even if I delete all related data from the mqtt broker.
Please provide some details
Thanks

revk, 2023-10-27:
The Faikin uses same library as ESP32-BLE-Env, just make sure latest version.

So it should see the same devices, directly, via BLE.

The library recognises a few different types, including ELA Bluecoin, and refreshed simple temperature sensors with ESP Home mode, and another mode.

wurmtal868, 2023-10-27:
For Xaomi device I had to flash the custom FW using the Telink Flasher webpage. I had to disconnect the Telink Flasher before the sensor appeared in the menu of the Faikin module.

revk, 2023-10-27:
The sensor has to be advertising, which normally means it has to not be in a "connected" BLE session, if that helps.

ckvsoft, 2023-10-27:
My mistake. Until now I thought I needed ESP32-BLE-Env which reads the device and forwards it to the mqtt broker.
And then Faikin gets the temperature from the mqtt brocker. I then manually sent such entries to an mqtt broker and was wondering why Faikin doesn't recognize this data.
I misunderstood and misinterpreted everything

revk, 2023-10-27:
There are also commands via MQTT to tell the Faikin current and target temp from my environmental monitor/display project - they are also in the manual.

But no, the BLE is done direct.

ckvsoft, 2023-10-27:
can you give me an example?
I can't find anything about what an mqtt message looks like

revk, 2023-10-28:
Best to look in the manual. An MQTT message has a topic (text with / separators) and a payload (which can be anything but is quite often JSON these days).

ckvsoft, 2023-10-28:
Yes, I already know what a message looks like. Just not the one for Faikin. where does Faikin expect this point to be accepted as the current temperature. I can't find any information in the description

revk, 2023-10-28:
OK, so `command/nameoffaikin/control` with payload like `{"env":20.6,"target}:[20,21]}`

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

ckvsoft, 2023-10-28:
Thanks. I guess I missed that :)

ckvsoft, 2023-10-28:
should I see the sent temperature on the Daikin webpage? Like with BLE-Env?

revk, 2023-10-28:
Hmm, not sure, maybe.

ckvsoft, 2023-10-28:
If you ever have time. I would like the sent remote temperature to be displayed and used in Faikin Web in the same way as the BLE device temperature is displayed and used. That would be great
Thanks

revk, 2023-10-28:
I'll have to look in to it... Should be easy enough to add to the web page.

ckvsoft, 2023-10-28:
Wenn Du schon dabei bist. Kannst Du vielleicht auch die Außentemperatur anzeigen?

revk, 2023-10-28:
I thought it did that, but OK, yeh, will look at what temperatures we have and display them all.

ckvsoft, 2023-11-01:
@revk
Since the update (Faikin-S1-PICO: faf663c 2023-11-01T11:51:03) the coil temperature is no longer displayed instead of additional temperatures

revk, 2023-11-01:
I cannot see any changes that would have caused that!

However, I agree, mine is not showing it either!

Ah, javascript error, FFS, OK, one sec.

ckvsoft, 2023-11-01:
@revk
Nice. Is back ;-)
Are you on the other side of the temperature display or are you busy doing something else?

revk, 2023-11-01:
Uh?

revk, 2023-11-01:
Ah, OK, is `outside` the only one left?

revk, 2023-11-01:
Ok I have added outside, making an release now.

ckvsoft, 2023-11-01:
That's great. Thanks
Now all that would be missing is the temperature for remote (command.DaikinWZ.control, DaikinWZ is my Faikin climate in the living room)

revk, 2023-11-01:
OK is that a temp we have? Do you know the S21 command to get it?

ckvsoft, 2023-11-01:
The temperature comes from the mqtt server. Or have I misunderstood that?

ckvsoft, 2023-11-01:
ESP32-Envmon sends to the mqtt server and faikin then also displays this temperature from the mqtt server. That's what I mean

revk, 2023-11-01:
Sorry, I am being thick today, ok, I'll take a look.

revk, 2023-11-01:
I may look in the morning

ckvsoft, 2023-11-01:
Thanks. No problem
Just don't stress, I'll survive until then ;-)

revk, 2023-11-02:
It is showing the external temp but next to the internal.

My plan it so re-layout all the temps we show to much clearer. Maybe even add tooltips.

Hopefully this morning.

revk, 2023-11-02:
I have changed the display for temperatures (and BLE humidity) completely. Should be a lot clearer.

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

ckvsoft, 2023-11-02:
That's pretty clear.
If I want to emulate an EnvMon on my Raspberry, sending the message command.Faikin.control is probably not enough. Can you tell me which message faikin is looking for to find out the status?

revk, 2023-11-02:
It just expects the control message regularly (not sure of timeout, maybe once a minute). If they stop for any length of time it reverts to normal control mode rather than trying to manage the aircon to a remote temperature/target.

ckvsoft, 2023-11-02:
Thanks.
That's strange, I send the message every second
`command/nameoffaikin/control` with payload like `{"env":20.6,"target}:[20,21]}` but it doesn't show up in Faikin.

I'm assuming that `nameoffaikin` is the name I gave my climate. In my case `DaikinWZ`

revk, 2023-11-02:
Is that a typo? Target ending } not "  ?

ckvsoft, 2023-11-02:
Yes ;-)
`{"env":21.44,"target":[22,23]}`

revk, 2023-11-02:
Working now?

ckvsoft, 2023-11-02:
Unfortunately no.
Are you sure there isn't some way to check whether a device is online? You can't tell from the command whether there are any changes coming. For example, my temperature has risen. not changed for 2 minutes.

revk, 2023-11-02:
Well, it is on-line if it is sending us messages, and not on-line if it is not. That seems pretty simple.

MQTT can do retained messages and "last will" messages, which means a device could leave a "state" in the MQTT server that says on-line or off line, but making such messages for your app will be much more work, and at the end of the day, just "whether we are seeing the messages" seems the obvious way to do this and is pretty fail safe - i.e. even if a device claims to be on-line, if not sending messages we should stop assuming it is on-line.

Example of my MQTT messages for this, if that helps

`
command/GuestAC/control {"env":19.12,"target":[16.000,32.000]}
`

No, the `.000` won't be significant. Send at least every minute (there is a config setting for the timeout I believe).

Just to check, you have BLE turned off on the Faikin, yes, as it does either MQTT external messages or BLE external, not both.

ckvsoft, 2023-11-02:
It seems like I'm too stupid for it or we're talking past each other.

Example:
I send a message to the MQTT server 10.1.1.254 port 11883

`command/DaikinWZ/control {"env":21.1,"target":[22.0,23.0]}`

These are saved in the data point.

On the other hand, Faikin is connected to this MQTT server and checks whether there is anything in the data point command/DaikinWZ/control.

However, this data point is not deleted if I no longer send messages. Aside from the fact that I don't see anything in Faikin, how would Faikin know it wasn't an old entry?
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
ckvsoft, 2023-11-03:
state/DaikinWZ

```
{
  "ts": "2023-11-03T08:55:47Z",
  "id": "308398D3D848",
  "up": 5,
  "mqtt-up": 1,
  "app": "Faikin",
  "version": "d24d314",
  "build-suffix": "-S1-PICO",
  "build": "2023-11-03T08:31:25",
  "flash": 8388608,
  "rst": 3,
  "mem": 57560,
  "spi": 2091372,
  "ssid": "ckvsoft_ext",
  "bssid": "78D294E9E754",
  "rssi": -51,
  "chan": 6,
  "ipv4": "10.1.1.88"
}
```

revk, 2023-11-03:
OK and if you send `command/DaikinWZ/test`

ckvsoft, 2023-11-03:
status
```
{
  "protocol": "S21",
  "env": null,
  "online": true,
  "home": 13.5,
  "heat": true,
  "fanrpm": 0,
  "comp": 0,
  "outside": 9,
  "liquid": 22,
  "power": false,
  "mode": "H",
  "temp": 25.5,
  "fan": "A",
  "swingh": true,
  "swingv": false,
  "econo": false,
  "powerful": false,
  "comfort": false,
  "streamer": false,
  "sensor": false,
  "quiet": false,
  "autor": 0,
  "autot": 25,
  "auto0": "00:00",
  "auto1": "00:00",
  "autop": false
}
```

ckvsoft, 2023-11-03:
> OK and if you send `command/DaikinWZ/test`

test = {"ts":"2023-11-03T09:16:08Z","description":"Unknown","prefix":"command","suffix":"test"}

revk, 2023-11-03:
OK you do not get an `info/DaikinWZ/debug` message?!

ckvsoft, 2023-11-03:
> OK you do not get an `info/DaikinWZ/debug` message?!

no

revk, 2023-11-03:
Arg, I see  ` "otahost": "ota.revk.uk",`

I thought you changed it to get my test code!

ckvsoft, 2023-11-03:
Thought I should put it back. Sorry

ckvsoft, 2023-11-03:
switch back. now
`debug = {"prefix":"command","target":null,"suffix":"control","payload":"{\"env\":21.4,\"target\":[17.0,26.0]}"}`

ckvsoft, 2023-11-03:
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

revk, 2023-11-03:
OK it is definitely seeing the `control` - I need to add more debug for you... One moment.

revk, 2023-11-03:
Yeah change `otahost` back **when we have finished**... Stay with it for now so we can test with extra debug.

I have added more debug, so upgrade and see if any new response to `control` now.

ckvsoft, 2023-11-03:
`debug = {"autob":true,"remote":false,"min":17.000000,"max":26.000000,"env":21.000000}`

looks like min/max has been adopted

`automation = {"hot":true,"approaching":600,"beyond":0,"samples":600,"period":900,"temp":13.00,"min":17.00,"max":26.00}`

revk, 2023-11-03:
OK I said BLE and this would not work together, you have `"autob": "A4C138BECD3C"`

I suspect this issue is that this is left set after you tried BLE, and then turned off BLE.

So I need to clear/ignore `autob` if BLE is off. I'll make that change now.

ckvsoft, 2023-11-03:
I once had BLE in operation. Apparently it doesn't turn off when you turn it off

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

revk, 2023-11-03:
Yes, BLE sensors off, but you had picked one at some point, and that is still stored. I'm issuing new code now. Try that in a few minutes.

ckvsoft, 2023-11-03:
Habe ein Update erhalten doch
`debug = {"autob":true,"remote":false,"min":17.000000,"max":26.000000,"env":20.900000}`

revk, 2023-11-03:
That is not updated. Try again.

ckvsoft, 2023-11-03:
Up to date
Faikin-S1-PICO: 0faa4d0 2023-11-03T10:52:44

revk, 2023-11-03:
Ok I'll build and issue again anyway, but that code does not even have the "debug" output. It should just work now.

ckvsoft, 2023-11-03:
Nice
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

Got two more things.
The min/max target replaces the +/-, or what is it used for?

I have an error that the temperature of 32 degrees cannot be set. Can your Daikin do that? Mine can only do a maximum of 31

revk, 2023-11-03:
Min/max is whatever you want. When not using this, the settings do ± values instead, yes.

It will be whatever the Daikin can do. I think mine can do 32C, but I know it varies from model to model.

ckvsoft, 2023-11-03:
Thank you for your efforts and sorry for being so lazy

ckvsoft, 2023-11-03:
Env works now. But if no more messages are sent, Env still remains visible

revk, 2023-11-03:
It is not really geared up for it coming and going. It should stop doing the "auto" control if no messages sent but might not remove the last value from the screen. This could perhaps be improved.

revk, 2023-11-04:
OK, odd, I have checked. Looks like the default timeout is 10 minutes. After that the remote control logic and env all get cancelled. Loading the main page after that should no longer show Env temp.

It looks like the power has to be on for that, so that is something I can improve.

Closed 2023-11-03.

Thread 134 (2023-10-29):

Regular reboots and failing auto updates

ozonejunkieau, 2023-10-29:
Good Day,

Just wondering if you were able to provide some pointers on how to diagnose this one.

FWIW the unit is connected to a CTXM25RVMA unit via the S403 connector, powered from the +14V pin.

I've got a few behaviours that aren't quite right:
1) The unit sometimes just fails to connect, but if left alone will apparently come good after a few hours. During this time the Web UI is accessible and MQTT is up, it just polls awaiting a response. Even a complete power cycle of the unit doesn't seem to convince it to connect.

2) Frequent logging of `error/spareroomac/comms {"protocol":"S21","badlength":"3","command":"SD","data":"303030"}`. I assume this is just an unsupported command that hasn't timed out yet, possible related to the frequent reboots?

3) Frequent Reboots:
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
This is a plot of the reported uptime values from the unit. The unit only seems to report them very infrequently, though it appears to reliably report the initial near zero value reliably?

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
This includes the reported memory usage, so it doesn't appear to be running out of memory?

_Hardware Version_
Relatively recent files from git ordered from JLC directly:
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

_Software Version_
Built using `make s3`  from commit `1272a2fdd7793b5dcdab628740e00f53368a868c`. I've tried issuing an update command to force an upgrade to the current version on the cloud but I get an error `ESP_ERR_OTA_VALIDATE_FAILED` - is this related to having to generate a self signed certificate as part of setting up the environment for the `make` script to run? Or possibly due to using a newer version of the firmware than is currently published?

Thanks for any help you are able to provide, and additionally thank you for what appears to be a most excellent project!

revk, 2023-10-29:
Very comprehensive report indeed!

The log shows it trying S21 which will fail but it should cycle through some options within a few seconds and find the right one. So odd if taking a long time. I suspect if the rebooting is solved it won't be an issue though. Even so, it should have saved the protocol to use when it next boots. So it is unexplained.

I suspect the reboot is the main problem. Can you connect a serial console and get a log of the reboot / crash when it happens. That will be the big clue as to what is wrong.

There is both serial and USB on the back of the board.

revk, 2023-10-29:
Oh. And yes. The upgrade is signed. You can set otahost to point to your server to upgrade to your build.

ozonejunkieau, 2023-10-29:
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

Thanks for the pointers.

When the unit is working it reports the protocol as S21 in the status message, which I believe is expected. Apparently the only difference between the S403 pinout and the S21 pinout is that the S403 is not isolated. There is an adaptor board available from the manufacturer to provide the S21 signals in the usual isolated fashion.

On this point - I'll have to work out the best way to safely capture the data from the unit, no isolation means that I can't directly connect to a laptop. I'll see what I can work out.

Just quickly, is there an explanation in the docs somewhere on what the reported "spi" value is that is broadcast as part of the state? When the unit goes through an "unstable patch" I do see this value jump around a bit.

What is the best method for setting up a PCB that I have programmed myself to support the auto update features, or is this not really a supported configuration.

revk, 2023-10-29:
Ah, OK, S403 must be S21 then, sorry, my mistake. So yes, good.

And yes, I see the issue, if not isolated, ouch, OK.

"spi" is the amount of external RAM (psram connected via SPI). There is internal RAM and external - either getting low is bad.

You can set up the auto upgrade using your own host, the URL is just the name of the binary. But it won't load from *my* updated binaries as they are signed with my key. So you'd have to build whenever I issue new code. Not sure of a good way around that.

ozonejunkieau, 2023-10-29:
I left a script running last to acquire logs via MQTT from the host, and it seems the periodic reboots are occurring as the OTA update is failing.

The timestamps where the uptime resets line up with an attempt to apply an update, which fails and then reboots the device. I've attempted to turn this off this morning by setting `setting/spareroomac/otaauto` to `0`. I'll see how that behaves today.

revk, 2023-10-29:
Ah, bingo, yes, there is a catch for failing to auto update. If there is no update that is different. But any failure causes a reboot. Wow. Well spotted.

ozonejunkieau, 2023-10-30:
Yep, that was definitely the cause of the reboots! After turning off automatic updates, no reboots and the uptime plot seems well behaved - thanks very much for that! Do you mind if I submit a pull request with some improved notes on the build process that note this as likely if you build yourself?

Unfortunately, the data from the unit still doesn't seem all that reliable in its collection - I'm seeing pretty regular time periods of more than 30 minutes where the unit drops offline and no data is received at all:
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

Even when the unit is online I get the following in what appears to be every poll:

```
info/spareroomac/tx {"protocol":"S21","dump":"0252449603","RD":""}
info/spareroomac/rx {"protocol":"S21","dump":"0253443030302703","SD":"000"}
error/spareroomac/comms {"protocol":"S21","badlength":"3","command":"SD","data":"303030"}
```

I assume this is just a message that my unit doesn't support, though it's still retried every time from what I can see?

revk, 2023-10-30:
Pull request is fine. Thanks.

As for comms, that is odd. An unsupported message has a specific response and my code stops sending unsupported messages.

That seems more like some sort of comms problem. It could be interference or more likely a marginal timing of some sort. It may be that some tweaks to the protocol handling are needed.

The fact it takes long to recover is also a concern. It may be worth my adding a pause when there is an issue to help things that have got out of step somehow.

revk, 2023-10-30:
I have issued code with a an extra part flush and pause on any error in S21.

ozonejunkieau, 2023-10-30:
> I have issued code with a an extra part flush and pause on any error in S21.

Thanks very much for that, I've just built and updated the firmware, will see how it goes over the next 12 or 24 hours.

FWIW, I'm still seeing the regular `error/spareroomac/comms {"protocol":"S21","badlength":"3","command":"SD","data":"303030"}` lines in the log output.

revk, 2023-10-30:
That is odd, I hope it recovers faster. There is a debug setting and I think a dump setting which may offer more clues.

ozonejunkieau, 2023-10-30:
> That is odd, I hope it recovers faster. There is a debug setting and I think a dump setting which may offer more clues.

Yep, one of the posts above includes the dump output that goes with that error. I'll log all the MQTT data overnight again and see if it yields any differences.

I was also reflecting on your comment about timing - as I mentioned, I'm using the non isolated S403 port to get this data, I'm wondering if the few microseconds of difference in timing that may arise from not have optoisolators in the signal path may be a factor here. Is the timing of the protocol analysis likely to be that sensitive?

revk, 2023-10-30:
The timeouts are quite long, having checked, so that seems less likely now. Other than playing with an oscilloscope it may be hard to tell.

revk, 2023-10-31:
The bad length looks like a red herring, seems `SD` response is normally 3 bytes, and the code was expecting more. The `SD` is only sent in debug.

ozonejunkieau, 2023-10-31:
Ahh okay, thanks for that!

I've not had a chance to go through my device log in detail yet, but the slightly modified code is definitely more reliable at reporting data. The longest period that I've seen is now 15 minutes between data points, which is substantially improved!

I do think there may be something in the interference idea too, I'm slowly gaining confidence to deploy a second one of these so will be intrigued if the behaviour is the same. At the moment I'm a bit worried about the very high input impedance of the unprotected FET gate, wondering if some parallel capacitance and a board level pull up may help - have you tested anything like this?

revk, 2023-10-31:
The input should be driver both ways by the air-con so I was not expecting any problems on that - the problem is the air-con seem to vary from model to model, and the only issue I had was actually with Tx to the Daikin which needed the current circuit.

matt-nz, 2023-11-01:
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

I've been following this thread with interest as I have a second AC with only the S403 port and I don't have the S21 adapter board (KRP413AB1S). From what I read you have connected via the S403 and it mostly works? I understand somewhat what non isolated means in electronics but I'm not clear what risks or additional precautions I should take if I wanted to try this. Have you just connected the Faikin / ESP32 directly in the same way as with the S21?

revk, 2023-11-02:
Everyone please bet careful not to electrocute yourself. And don't blame me if you do!

matt-nz, 2023-11-02:
Haha, 😊 thanks. I'm not going to electrocute myself more likely I wondered if it's non isolated that mains voltage flows nearby / though so want to avoid a short circuit or damage AC or Faikin.

ozonejunkieau, 2023-11-04:
Sorry for the delay in getting back to this - I think I have finally worked out a few more things to be useful!

I think the periods that I am now missing a few minutes at a time are due to a bit of a quirk in the way I was logging MQTT data. I was only graphing data that was provided by the `state/spareroomac/status` topic, and this would sometimes go periods of many minutes with no apparent update. Having said this, I've now gone back through my logs and I can see that the `Faikin/spareroomac` topic gets a more frequent update of almost the same data and it appears to be still being reported during my times of missing logged data. I've just updated my logging script to include data from the second topic, so will see how that behaves over the next few days.
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
revk, 2023-11-04:
It would be interesting to know if it can work without the pull up, ie it was just a loose connection.

My experience so far is the daikin has an internal pull up. The 5V pull up was done "just in case" there is a model without.

But good write up. I may update the manuals to explain the non isolated port. So you have a pin out & picture?

ozonejunkieau, 2023-11-04:
I'll grab some photos tomorrow from the two units that I have - they have slightly different connectors (because who needs standards). I'll also grab the exact model numbers to add to the wiki page too.

I do also have some photos of how I have done the install too, one of the S403 connectors I had was a 2.0mm pitch connector that was particularly narrow, but I managed to get it working with a Dremel and a 2mm JST connector to start with.

My own adventures have basically entirely been based on this thread: https://community.openenergymonitor.org/t/hack-my-heat-pump-and-publish-data-onto-emoncms/2551/99. Someone has documented the S403 pinout and provided high resolution images of the Daikin conversion board in it.

revk, 2023-11-04:
Ah, nice.

ozonejunkieau, 2023-11-05:
Just in case you would like some photos for any of the doco:

Populated S403 Connector on an FTXM71UVMA. 2.0mm pitch connector, using a heavily modified JST connector to mate with the pins.
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

Matching module, with Polymorph as strain relief and wrapped in heatshrink. Mounted within the shielded enclosure:
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

S403 connector on a CTXM25RVMA. This one is 2.54mm pitch:
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

Closed 2023-11-03.

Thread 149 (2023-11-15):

[BUG] Device is not working after flashing binary from release folder

UgniusBur, 2023-11-15:
**Faikin hardware**
FDXM50F9

**Daikin hardware**
2023-09-08 Faikin PCB + custom made X50A + X35A -> S21 lead.

**Describe the bug**
I have recently assembled a Faikin device to connect to my AC unit.  Everything flashes, the device creates a hotspot and successfully connects to the house wifi. After flashing and connecting the LED is always RED/WHITE it does not change any color (even after connecting wifi still red/white). If I connect 34 and 48 pins together - the LED doesn't change too. The oscilloscope on those pins is also silent. The device looks like stuck in some kind of loop(?) and doesn't change LED modes, UART is not working.  Is there any chance that release firmware is not correct? I do not rule out the possibility that it is my soldering issue, but I have tried 2 different boards and the behavior is the same. Is there any way to debug print this device?

**To Reproduce**
Steps to reproduce the behavior:
1. Flash device using: command `esptool.py -p /dev/ttyACM0 -b 460800 --before default_reset --after hard_reset --chip esp32s3 write_flash --flash_mode dio --flash_size keep --flash_freq 40m 0x0 Faikin-S3-MINI-N4-R2-bootloader.bin 0x8000 partition-table.bin 0xd000 ota_data_initial.bin 0x10000 Faikin-S3-MINI-N4-R2.bin
`
2. Connect to Faikin's Wifi
3. Enter wifi SSID  and password

**Expected behavior**
UART is sending any info. LED light changes regarding status. Loopback test is working

revk, 2023-11-16:
Sorry for delay, the loopback test may not work on latest board unless 5V is connected. Also may not show on oscilloscope unless 5V connected or connected to the Daikin which has an internal pull up.

Can you check with the 5V connected and see if there is data flowing?

UgniusBur, 2023-11-16:
Thank you for the reply.

I have tried to power up 5V. Now I see inverted UART data on lines every ~20 seconds, but no loopback mode indication.

I am a little bit concerned why my LED is not changing. The documentation mentions that it should be BLUE/WHITE(?) but the LED is always RED/WHITE no matter what.

P.S. I already tried it on Daikin - no luck. Even with RX/TX swapped. That's why I put it under the oscilloscope.

revk, 2023-11-16:
When not connected to loopback, it should cycle through inverted and non inverted and two different baud rates.

Once looped back the LEDs should change to red/green/blue cycle.

Yes, blue/white means AP and wifi mode - once connected to your wifi it should stop the AP and just be something else. red/white is non wifi config. Is it definitely connecting to your wifi?

I don't suppose you have another one in case it is faulty?

UgniusBur, 2023-11-16:
I am 100% it is connected to wifi. I can connect to Faikin control page using local network.

I have a few spare boards, they all act the same, but they are hand soldered.
Is there ant posibility to print any debug logs to the USB?

revk, 2023-11-16:
The latest boards have 4 pads for USB on the back of the processor, and allow USB logging using esptool.

Is it on mqtt? If so we can send new settings including upgrading to a test build I can make with extra debug.

UgniusBur, 2023-11-16:
I connected to the logs using ‘make monitor’.
I can see that device prints “Loopback” once, but LED is still RED.

What I also noticed:
1. TX is always HIGH (inverted uart) while rx is always LOW (normal uart). Shouldn’t it swap between interted/normal modes?
2. I can confirm that device transmits “something” and my Daikin has 5V power. But when trying to power on using webpage - nothing works. Do Faikin waiting for some kind of response?

revk, 2023-11-16:
Rx on the Faikin will be low, it expects to be drive.

Tx should (if not connected to loop back) cycle between inverted and non inverted. The MQTT should show something for this. Once it gets a sane response it knows what mode it is in and should communicate.

It could take a minute to find the right setting, but then it stores it in flash to be quick next time.

UgniusBur, 2023-11-16:
I have found why LEDs are not working:
sdkconfig defined LEDs to a single pin: `CONFIG_REVK_BLINK "47 47 47"`.
Both "Blink LED GPIO(s) defined in library" and "Blink LED update done in library" were enabled. I disabled "Blink LED GPIO(s) defined in library" and now it is working.

Now I need to find out why UART is not communicating with daikin.

revk, 2023-11-16:
Ah, sorry, missed the fact it is your build. Yes, the code has moved on with the chip design a bit.

Check the GPIOs very carefully!

Send setting/... as well or erase flash and re flash, as GPIO settings are designed to persist once first set and not follow new defaults in code.

UgniusBur, 2023-11-16:
I noticed the same behavior in release firmware too. I built it by myself only because I wanted to have more debugging options.
I think I need to create MQTT server to be able to access settings then.

UgniusBur, 2023-11-16:
I managed to create an MQTT server.  I tried to power on Daikin using power (0/1) slider in the web application.
It instantly turns off and I can see: "{"field":"power","error":"Setting cannot be controlled"}" on topic: "error/AC/control".

How should I interpret this message?

revk, 2023-11-16:
If it has not managed to talk to the Daikin it will not know what settings can be controller. Need to get it talking first.

UgniusBur, 2023-11-16:
I swapped TX/RX lines and got messages to "error/AC/comms" topic:
`
{"protocol":"X50¬Rx","timeout":true}
{"protocol":"S21¬Rx","cmd":"F1","noack":true}
{"protocol":"X50¬Rx¬Tx","timeout":true}
{"protocol":"S21¬Rx¬Tx","cmd":"F1","noack":true}
{"protocol":"X50","timeout":true}
`

Now I have swapped lines back and this topic is silent. I assume that it already communicated.

revk, 2023-11-16:
Ok that suggests it is talking.
There is a setting for `debug` and `dump` that can be set to `1` which shows what it is sending and receiving.

UgniusBur, 2023-11-16:
I periodically get these lines:

```
{"protocol":"X50","dump":"06AA0701000146"}
{"protocol":"X50","dump":"06AA0701210026"}
{"protocol":"X50","cmd":"AA","payload":"00"}
{"protocol":"X50","cmd":"CA","payload":"0000000000000000000000000000000000"}
{"protocol":"X50","cmd":"CB","payload":"0000"}
{"protocol":"X50","cmd":"AA","payload":"01"}
{"protocol":"X50","dump":"06AA0701000146"}
{"protocol":"X50","dump":"06AA0701210026"}
{"protocol":"X50","cmd":"AA","payload":"00"}
{"protocol":"X50","cmd":"CA","payload":"0000000000000000000000000000000000"}
{"protocol":"X50","cmd":"CB","payload":"0000"}
{"protocol":"X50","cmd":"AA","payload":"01"}
```

revk, 2023-11-16:
Hmm, does the topic explain if `tx` and/or `rx` on those? It may help.

UgniusBur, 2023-11-16:
Sorry, should have thought about it first:

```
info/AC/tx {"protocol":"X50","dump":"06AA0701000146"}
info/AC/rx {"protocol":"X50","dump":"06AA0701210026"}
info/AC/rx {"protocol":"X50","cmd":"AA","payload":"00"}
info/AC/cannot-tx {"protocol":"X50","cmd":"CA","payload":"0000000000000000000000000000000000"}
info/AC/cannot-tx {"protocol":"X50","cmd":"CB","payload":"0000"}
info/AC/tx {"protocol":"X50","cmd":"AA","payload":"01"}
info/AC/tx {"protocol":"X50","dump":"06AA0701000146"}
info/AC/rx {"protocol":"X50","dump":"06AA0701210026"}
info/AC/rx {"protocol":"X50","cmd":"AA","payload":"00"}
info/AC/cannot-tx {"protocol":"X50","cmd":"CA","payload":"0000000000000000000000000000000000"}
info/AC/cannot-tx {"protocol":"X50","cmd":"CB","payload":"0000"}
info/AC/tx {"protocol":"X50","cmd":"AA","payload":"01"}
```

revk, 2023-11-16:
OK good, data is going both ways! This is a good start...

OK, this may be something I can look in to. It may be a timing issue, as AA is getting a reply. It could be a timeout change needed.

UgniusBur, 2023-11-16:
I turned the AC unit off and on again. Looks like the output is the same...

I forgot to mention that this unit is "fresh" and was never started with any other controller. Maybe it has something to do with this "not ready" response.

revk, 2023-11-16:
OK not a scenario I have encountered. Mine had other controllers, but did not expect any sort of setting the enable them. I guess it is possible. I mean we could carry one ignoring the `00` response perhaps. Line 479-480 of `Faikin.c` if you want to play.

revk, 2023-11-16:
That would be a shame. I hope it works.

UgniusBur, 2023-11-17:
I bought an original Daikin controller. It is not able to connect either. I sniffed UART - I get the same response.
1. I got faulty Daikin.
2. I should do some kind of start-up procedure I don't know about.

revk, 2023-11-17:
Wow, and if you find an installation process for it, please do let me know :-)

UgniusBur, 2023-11-21:
Okay, so it was my mistake. Ducted Daikins must have remote controller: wall mounted or infrared in order to work. Just Wi-Fi controller is not enough for proper functionality.  They all must be purchased separately.

I have installed wall mounted controller and now Wi-Fi is working. For now I just tested the original Wi-Fi adapter, not Faikin but I already hate the genuine one. The Onecta app is terrible. If you want you change the temperature you have to set it multiple times because it likes to "wooble back" (I think it reads actual value from the cloud and sets the temperature back) and such simple operation becomes exhausting.

Also I regret my choice to install ducted Daikin. I wanted to hide it in the ceiling, and it hid well BUT IT SCREAMS ALL THE TIME. There is no auto fan mode. You just set the fan speed and it spins 24/7. No matter what temperature. It doesn't bother during the day time but that constant fan blow is terrible at night. The lowest fan is already too loud. I would love if I would be able to make it spin a little bit slower or just turn it off when the temperature is right. Now I have to manually turn on/turn off the entire AC to achieve such functionality and I don't know if it is very efficient.

UgniusBur, 2023-11-21:
By the way I am closing this issue but I still see that release firmware does not control LEDs. It just lights them all and RGB is always white. I can open another issue for this.

revk, 2023-11-21:
OK? But check what is set in blink matches the GPIOs

Closed 2023-11-21.

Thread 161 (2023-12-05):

[BUG] Odd behavoir when using the auto mode with BLE temp sensor in Home Assistant

wurmtal868, 2023-12-05:
**Faikin hardware**
S1 / S3 Mini modules from Amazon

**Daikin hardware**
Daikin Perfera Mulitsplit

**Describe the bug**
When I try to turn on the fan to stir up the air in my living room while heating with my wood stove, the Faikin module sets cooling mode on instead of turning on the fan.
Same happens, when I turn on heating in Home Assistant while the BLE temp is higher than the auto set temperature. The idea of tuning the heating on while it's warm enough, is that the AC unit should keep a minimum temperature in room when fire burns down.

This is happening despite the lock mode "on" for  heat/cool modes and is not obvious when using the HA GUI.
Home Assistant just shows auto mode although I pushed the button for heat or fan only.

**To Reproduce**
Set Lock mode "on". Auto mode on with BLE sensor.
Turn the indoor unit off while in heat mode is on.
The Faikin GUI will show heating while the unit is off.
When the BLE temperature  is higher the auto set temperature, turn the unit on.
The mode will be switched to cooling.

**Expected behavior**
When tuning on the indoor unit, I expect the unit to stay in last mode chosen. If it's warmer than the max temperature for heating it should do nothing until the temperature drops below the lower threshold for heating.
If it's cooler than desired in cooling mode it should do nothing.

**Additional context**
I'm not sure how to address the issue when tuning on just the fan in HA. In any case the unit should not switch between heating and cooling with Lock Mode="ON"

revk, 2023-12-05:
When turning on, it sets heat/cool depending on whether hotter or colder, normally. When running it waits before "switching" to minimise switching back and forth all the time. This is intentional behaviour. It may be worth documenting.

There is now a `lockmode` (can be set from settings link on web control page) which stops it switching mode. However, looking at the code, the "initial" heat/cool is not disabled when that it set. I'll make a change for that so you can use `lockmode`.

wurmtal868, 2023-12-05:
I don't understand, I think I set the lockmode in the web control page.
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

revk, 2023-12-05:
Yes you did, but as I said, the code was not honouring that for the initial start from power off.

I have issued code now that does, so upgrade.

wurmtal868, 2023-12-05:
I updated the FW and it did not switch :-)
However,
instead of waiting for the temperature to drop the unit starts heating:
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

wurmtal868, 2023-12-05:
This may be related to a issue I have when I set two indoor units hooked to the same outdoor unit to keep the same temperature. Both are set to 17°C " Wohnen" is fine within 0.5° while "Kochen" is going higher and higher  :-(
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

When only one unit is on at the same time everything seems to be fine.

revk, 2023-12-05:
I think I have seen Daikin do that. At the end of the day this is just applying settings to the Daikin. If, when you have it set to heat to lower than current temp it still heats, that is how it works. I'm not sure what other setting we could sensibly apply in such cases.

revk, 2023-12-05:
Err, ok, then don't turn it on?

I have not tried making it cancel what you do generally. It does have an auto on/off control you can use instead. Maybe that will do what you need?

Or are you saying it did auto turn on?

Sorry if I am misunderstanding.

I may have to make that consider lock mode as well?

wurmtal868, 2023-12-05:
A multisplit will heat up all indoor at the same time and the indoor unit decides whether the fan should be on for heating. For some reason the fan turns on although the temperature is already higher than the set temperature. Is possible that the Faikin turns on the fan when it detects that the compressor is on because another indoor unit requested heat?

wurmtal868, 2023-12-05:
Do you have a minute for a call?
https://meet.jit.si/GloriousMethodsUnveilRuthlessly

revk, 2023-12-05:
You can see what it is doing to the settings now.

I am not clear what you want it to do exactly, sorry. This sounds like a work around for something the Daikin does rather than a bug at this point. I'm just going out at the moment.

wurmtal868, 2023-12-05:
Do you have access to an Daikin Multisplit set up?

wurmtal868, 2023-12-05:
I have two three way split units. Using in a hybrid heating system with my wood stove.The third indoor unit on both systems is installed in the basement and usually turned off. My idea is to set abase temperature with the other AC units and heat up rooms individually to a higher value by either increasing the set point for the room or firing up my wood stove. When I just try to maintain a minimum temperature of 17°C like above the two units hooked to same outdoor unit diverge which I don't understand, when both set to exactly the same values. The happened on both outdoor units.

revk, 2023-12-05:
I have not tried to create anything for multiple units to work together at all. The only logic I have is to report when one is not working because it wants to cool when another is heating or the other way.

It is an interesting idea, but may be better for a separate tool, e.g. something on a raspberry Pi, or using home assistant. The Faikins can simply take instructions over MQTT.

It may be possible for the Faikin to do more - we do have settings to control the offsets for "not heating" and "not cooling" which could maybe be used to adjust what it sent to the Daikin in these cases. e.g. telling it to heat to an even cooler temperature, etc. It may be worth trying the various settings.

wurmtal868, 2024-01-19:
I think, I figured out why some of the indoor units keep heating beyond the BLE temperature limit.
In my hybrid system when using my wood stove, the heat in the room does not come from the indoor unit.
When BLE limit is reached, the Faikin module set the indoor unit to some 2K less than desired BLE temperature.
However,
to achieve the new temperature limit the indoor unit will heat up itself to some 3-4K more than this new limit because it tries to compensate for a temperature gradient inside of the room. Especially in my  bedroom the tmeperatur gradient is exactly the opposite from what is expect from the indoor unit, when heating with wood. So 2K delta is not enough to turn off the indoor unit.

revk, 2024-01-19:
There are settings to adjust how much over/under it aims for, see [Manual](https://github.com/revk/ESP32-Faikin/blob/main/Manuals/Advanced.md)

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

Closed 2023-12-05.

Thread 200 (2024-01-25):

Floating part in stl file

mike-yowen, 2024-01-25:
There is a floating part in the case stl file. Is this an artifact or actually something that should be printed?

https://github.com/revk/ESP32-Faikin/blob/main/PCB/Faikin/Faikin.stl

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

revk, 2024-01-25:
It is an artefact, don't print. I need to work out how to eliminate it.

Closed 2024-01-25.

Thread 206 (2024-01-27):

General Troubleshooting

smnino, 2024-01-27:
I am having a few issues that I hope someone can assist me with.

I am no electronics major but I have a very basic understanding. I am working with a Daikin FTX18BXVJU head unit.  I purchased my Faikin from Amazon UK although I am located in the US.

I can get the board to boot via usb serial adapter by connecting the usb adapter's VCC pin and GND to the Faikin's 12V and GND. The Faikin boots up fine and I can access the web UI. The VCC pin of the adapter is providing 4.9 volts to the Faikin. The Faikin only boots when voltage is connected to the 12V pin on the board.

My AC has an S21 connector. When I measure the voltage of the AC's pins, I get 4.9 on pin 5 and 9.4 on pin 4. When I connect the GND on the AC to GND on the faikin board and pin 5 on the AC to the  12V pin on the faikin board, the AC's control board starts making a slight buzzing noise and then the pizo buzzer beeps as if the AC's board is rebooting? At no point does the faikin boot. The faikin's LED does not light up at all. I am afraid to continue attempting this as I do not want damage the AC's control board.  I literally just had this AC installed less than 2 weeks ago.

I am including a few images of the AC's control board as well as the Faikin. I have updated the Faikin to the latest OTA firmware.

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

revk, 2024-01-27:
The S21 is connected one to one.

The power for the failing is on the "12V" (which may be 14V even). It actually works with anything from 5V to 35V.

The 5V connection (pin 1) is for a pull up. It does not power the Faikin board. If you try to power the Faikin from this it is likely to not have enough current (hence upsetting the aircon if you do that).

Elwell, 2024-01-27:
As the daikin boards aren't terribly clearly marked, it might be worth
having a diagram/ photo in the readme indicating which end of the s21 is
pin1. I was nervous of hooking mine the wrong way round (and couldn't
trivially find a ground reference to check pinout against). Can confirm
that jumper leads fit nicely, but I checked the shape of the connector vs
references multiple times.

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

revk, 2024-01-27:
I could add a 1. But as the plugs only fit one way around and it is one to one wired this has not really come up before. I agree that it is very unconventional of Daikin not having GND on pin 1 though. I'll see if the manual can be a tad clearer.

Elwell, 2024-01-27:
Yeah, your board is fine. It's the aircon end that wasn't clear (from the top side - it may well be marked underneath but I'm not pulling it out). Knowing it's a 1:1 maping meant I was holding yours beside it when running cables

revk, 2024-01-27:
Yeh, if you have the right plugs, it should be simple to make a one to one cable. If using jumper wires, I can see it may be harder. The board does have a "1" on it, I see.

smnino, 2024-01-27:
So, I made a 1:1 cable and I get no response from the faikin or the AC. I checked the continuity of the cable and the cable is good on all connections.

The faikin does nothing...

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

smnino, 2024-01-27:
> Not an expert, but I would double check your measurements of the board. The 5V pin shouldn't be next to the 12V pin on the S21 connection. You are attempting to connect here, correct?
>
> ![image](https://private-user-images.githubusercontent.com/10055220/300152952-92b262dc-5d92-440a-9e8f-e2b6084796b9.png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)

Yes, this is where I am connecting as this is labeled on the board as S21.

revk, 2024-01-28:
Can you check voltages on back of Faikin relative to GND (brown, pin 5)?

smnino, 2024-01-28:
I have gotten it to work. Seems there was something amiss with the cable I had made. When I removed the cable and used header cables, I was able to get it working.  An option to purchase an S21 cable along with the faikin would have been nice. I certainly would have paid extra for one....

Thank you for making this available to me & the masses.

My shipment from the UK came pretty quickly, maybe a week or 10 days and I didn't need a forwarder or have to pay anything extra. That said, if there is anything I can do to assist distribution of the fakin in the US, please let me know. The Daikins are starting to become popular here in the states and the faikin should be included with every unit in my opinion.

One more thing; Is there a way to change the display from celsius to fahrenheit?

revk, 2024-01-28:
If I could find a sensible source of S21 cables I would sell, or at least recommend/link. It does seem the most common configuration.

As for Fahrenheit - I was half expecting this one day. The underlying protocol is all Celsius, which makes it tricky.

I suspect Home Assistant can cope.

One option would be on the web interface to output the temperatures and even the settings in F along side the C, so you actually set in C but can see what that means in F. Would that help?

smnino, 2024-01-28:
Yes, seeing the conversion from C to F would be helpful. Although, it may not be worth the effort as I have it integrated into home assistant now and as you suggested, HA converts it fine.

There's very little about the faikin to be found. I did find a thread [here](https://community.home-assistant.io/t/need-daikin-wifi-use-the-open-source-faikin-esp32-hardware-instead-of-the-official-wifi-modules/644370/8) and posted the following questions. (C to F you've already answered)

- Is there a way to change the UI display from celsius to fahrenheit
- how does one set the timezone? The linked list doesn’t look anything like the default values
- I don’t understand a few of the UI icons: Green Dot/Blob, emoji with hands above head, left/right arrow, teddy bear
- what are the temps listed? They are labeled ‘Home’ & ‘Outside.’ Does the unit have an outdoor thermostat as well as one in the head unit?

revk, 2024-01-28:
The buttons all have mouse over tool tips (but not easy on a mobile).

The timezones should match the linked page, what time zone are you in? I'll look.

The temps come from the air-con, and yes there is an outside temperature sensor. Home is the inside one built in. Others relate to coolant temperature, etc.

smnino, 2024-01-28:
I did not mean to imply 'it was just you' I just didn't understand what they meant, like the teddy bear?

As for the TZ, I'm in the New York, eastern TZ.

revk, 2024-01-28:
Sorry.. fair enough. That is, I believe "comfort" mode, whatever that does.

I'll look up timezone when I get up. It is 2:30am in my timezone :-)

revk, 2024-01-30:
Ok following that link, under `America` I see

`{"name":"New_York", "tz":"EST5EDT,M3.2.0,M11.1.0"},`

So set `tz` to `EST5EDT,M3.2.0,M11.1.0`

gentlecat, 2024-02-06:
Just to add another datapoint, I ran into the same issue with buzzing sound after plugging in Faikin into S21 using jumper wires. Missed the fact that connector is supposed to be one to one. The sound seems to be happening due to backwards connection. Luckily that didn't break anything. Faikin started working fine after I flipped the wires.

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

Wasn't sure if my models (CTXS07WVJU9, FTXS09WVJU9, FTXS15WVJU9) will have the right connector since they were not listed in the wiki, but it turned out they do. I added them to the list already.

Thanks for making this awesome alternative! Shipping from Amazon UK to Canada was pretty quick.

Closed 2024-01-27.

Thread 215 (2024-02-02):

[BUG] powerful mode is changing from on to off on its own once enabled.

turbolooser, 2024-02-02:
When I switch on powerful mode then its changing back to off and on and vice versa (flipping) every couple of seconds

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

revk, 2024-02-02:
Ok that is weird, I am away for a few days, but I'll see if I can reproduce it when I get back.

MuzzaMcD, 2024-02-03:
I believe the black Asterix next to the Set 28C slider control indicates that you are in Faikin Auto mode. (?)
Not sure that trying to also tell the unit to enforce 'Powerful Mode' is logical.
I see that when Faikin Auto mode is Enabled the message " ✷ Automatic control means some functions are limited" is displayed.
In other words, on the one hand the Faikin Auto setting is trying to perform gradual controls to keep your unit at a specific set temperature and in a very specific range +-1c (?)  but the 'Powerful' request button is saying 'all in' (max thrust from the engine room'), forget set temperature just pump as much heat (or cool) as possible now.

revk, 2024-02-04:
Even so, it should not be flipping continuously. Does you aircon have *powerful*, it seems some settings are used for different things on different models.

Failing that, enabling `debug` and logging MQTT messages may give a clue what is happening.

revk, 2024-02-05:
If you can get me a dump, I'll re-open. I could not reproduce it here.

Closed 2024-02-05.

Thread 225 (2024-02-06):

[BUG] thermostat breaks hysteresis

miniluma, 2024-02-06:
**Describe the bug**
When _thermostat_ is not set to 1, the heating hysteresis is not working properly.
E.g. lower target temp is 20.5°C
BLE sends 20.48 -> heating starts (code goes in "if" because current < min), but hysteresis is not set to 1.
BLE toggles a bit and sends 20.52 after a second -> heating stops (code goes in "else" because current >= min)
As a result, AC is constantly going on and off within seconds around _min_.

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

revk, 2024-02-06:
Once it is set it is comparing to
max, surely?

miniluma, 2024-02-06:
> Once it is set it is comparing to max, surely?
>
> 20.52 is < max (I assume) so stays on (does not do else).

Yes, after I set thermostat to 1, it worked fine.

max was 21.5

miniluma, 2024-02-06:
But was defaulted to thermostat = 0 obviously

revk, 2024-02-06:
I mis read as when `thermostat` is set, sorry.

That is not a bug, that is how it is designed. It uses some prediction so normally does not change constantly, but it makes it a very tight temperature control.

Feel free to set `thermostat` to `1` if you prefer that way of working.

miniluma, 2024-02-06:
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

No, no, that's not how I prefer to work. (as you can see here as well https://github.com/revk/ESP32-Faikin/discussions/226) ;-)

Then, I don't understand how it should work with thermostat=0.
It behaved like this yesterday:
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
I had heatover=0, heatback=6, Automation on with Target=21 and +/-0.5°C and BLE sensor for Room temperature configured.

Maybe you have a hint how I can get it running as you expect.

revk, 2024-02-06:
Which line is temperature, the dark one? that looks pretty level. But yes, it turns on/off a lot. That is how I expect it to work, to maintain a very close temperature between min and max.

miniluma, 2024-02-06:
The black line is the inlet temp.
The red line is the settemp of the unit.
The dark red line is the fan speed.

All values are from the Daikin cloud, not from faikin, so it's a bit delayed.

miniluma, 2024-02-06:
Btw, the blue line here is the power consumption of the outdoor-unit.
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

revk, 2024-02-06:
OK so inlet temp was very flat. So as expected.

miniluma, 2024-02-06:
Sure, because the compressor only had a couple of seconds to a minute or two to pump something into the pipes and the fan was far below level one speed (like 400rpm).
To explain the situation:
The room was at ~20.5°C with 12°C outside air temp. The door was closed and all rooms around (below, above, and at the sides) were heated. With no active heating, it would take hours to come from e.g. 20.6 to 20.4.

The logic war jumping from 24 to 16°C unit target temp while the BLE temp was at 20.5 +/- 0.02. My desired room temp was set to 21.
So even if the inlet temp was stable, the unit wasn't really running and the algorithm wasn't doing something useful to reach towards the desired temp.
Probably, some internal values ran away ;-)

Today morning, the room was at ~19.8 and I tried again. thermostat=0, heatover=0, heatback=6, switchtemp=pushtemp=0
desired 21 +/-0.5
It set fan to 5 (I think this is expected) and did some target-temp control and heated the room to 21.4x (let's say ok). Fan was reduced to 4 an approx 21.3.
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
Now, it seem to cool down.
So far, so good.

One thing (refers to the discussion): The outdoor unit took >300W for nearly the whole time. With a lower target temp (inlet-2 or 3) and fan level 1, it takes 120-200W and the room temp is more stable. Of course, it takes longer to reach max, but the desired room temp is 21, not 21.5. ;-)

revk, 2024-02-06:
OK it is working perfectly for me like this, so rather puzzled.

There are settings to find turn it, to adjust where the targets are for heating and cooling, to make it close. A ±0.02 is very tight.

Closed 2024-02-06.

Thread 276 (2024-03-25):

Faikin does not connect to Emura 3

migueldc73, 2024-03-25:
I finally found the right PA 2mm pitch connector and got my Emura s21 port connected to the Faikin.

The Faikin clearly gets power and I can access the webpage, but there seems to be no connection with the FTXJ50A2V1BB indoor unit
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

System is offline and I also cannot turn it on neither via the webpage or Home Assistant
I also don't get temperate info in Home Assistant

I connected the S21 pins 1-5 to the same pins on the Faikin as per the instructions
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

I have suspicion that there is something wrong in the pin layout though
Pin 5 (black) : GND, seems to be OK on both
Pin 4 (red) : VCC 12V seems to be OK on both as the Faikin boots and I get the webpage
Pin 3 (yellow) : should be RX on S21 side, hence TX on Faikin side ? Faikin board just says "48"
Pin 4 (orange) : should be TX on S21 side, hence RX on Faikin side ? Faikin board just says "34"
Pin 5 (brown) : I connected it through as per isntructions although many users say it's "unused"

The Emura 3 Wifi seems to work fine as I can turn it on/off and change settings via the Onecta cloud app.

So what did I do wrong ?

revk, 2024-03-25:
It is normal 1:1, you don't normally swap tx and rx at all. It is always an issue with Tx and Rx and shoes side it is viewed from, Pin 1 (not 5) is typically unused, yes. 48 is "from the Faikin" (see little arrow), and 34 is "to the faikin" (again, and arrow). Does that help?

migueldc73, 2024-03-25:
I actually didn't swap the TX and RX, sorry should have said that.

If you look at the pics of both S21 and Faikin side, yellow is on Pin 3 on both sides, same for orange on Pin 4

Do you think I should disconnect Pin5 (cut brown cable ) ?

revk, 2024-03-25:
Depends what voltage, if 5V, should be fine, if GND, then would break it.

migueldc73, 2024-03-25:
I could measure the pins. Do you think yellow and orange should be swapped then on my setup if you look at both pictures ?

revk, 2024-03-25:
I would hope they have not gone for a different wiring.

If you can check voltages from pin 5 (GND) to each other pin when not connected to the Faikin.

Be very careful in case there are mains levels on anything!!!

migueldc73, 2024-03-25:
So I have
GND to Pin 4 (red) : 14.4V
GND to Pin 3 (yellow, supposedly TX) : 0V
GND to Pin 2 (orange, supposedly RS) : 0V
GND to Pin 1 (brown, unused) : 0V

migueldc73, 2024-03-25:
I cut the brown wire (nothing exploded, LOL), but still same issue
- Faikin is alive and on the LAN
- system still offline, so no communication over TX/RX

Is there maybe a setting (or dipswitch) on these new Emura 3 to enable/disable communication over S21 ?
But then it's still weird there is 14.4V over pin 2

revk, 2024-03-25:
OK, you have me at a loss now. Sorry, not sure if anyone else in a discussion may have an answer on this.

The fact the rx/tx are 0V not 5V is a concern, and probably why not working. I guess maybe it needs enabling?

migueldc73, 2024-03-25:
The problem is probably my self-made cable with PA connector. I measured the voltage directly on the S21 connector and the TX/RX seem to have 5V there.
Luckily my official Daikin EKRS21 cable just arrived at my Daikin shop, so will try that tomorrow.

revk, 2024-03-25:
Cool.

migueldc73, 2024-03-26:
So I connect the EKRS21 cable and the Faikin started up, but then it completely hung.
The magenta/white flashing light went on solid for a few seconds and then died out completely
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

I suspect something is wrong with my Faikin unit, but why is a mystery.

Checking the voltages on the end of the new EKRS21 cable now to be sure

migueldc73, 2024-03-26:
So it seemed that the 15V I took from the S21 is not stable (called my Daikin dealer to maybe replace the board), so I took the 5V from Pin1 (unused) of the S21 and fed it into Pin 4 (supposedly 12V) on the Faikin.

**Do you think the Faikin will run reliable with 5V ?**

I can now control my untit, turn it on/off, but it does weird things like turning telling the fan settings are wrong, selected temperature is jumping around, ....

revk, 2024-03-26:
The voltage is not the issue, it is the current available. On a normal S21, the 12V (or more) usually has enough power, but the 5V seems to be just a low current reference of some sort. So usually you can't run off the 5V.

If you have a 5V that is running the Faikin at all then it is likely an actual power supply, so is probably fine. The Faikin itself will be fine at 5V (the reg is rated roughly 4V to 36V).

migueldc73, 2024-03-26:
Well, I am actually powering the Faikin from the 5V (so-called reference, pin 1) and it starts up fine.
So you are saying that if it boots up from the 5V, it will probably be running fine all along, right ?

The behaviour of my indoor unit is very strange though. I can turn on/off and select mode, but when I try to change fan speed, it gives this error message that the fan speed is wrong. Will make some screenshots later.

revk, 2024-03-26:
Yes, if that works then it has to be a power feed of some sort, I suspect.

Fans are fun, but we can dump the S21 messages and see.

migueldc73, 2024-03-26:
ok, will do that later. I guess the manual explains how to dump the messages either from the Faikin webpage or HA ?

Something weird though : I powered the Faikin from the 5V of a USB connector on my laptop and sometimes it just stops working after a few mins, but now I restarted it seems to be running 10mins fine...

migueldc73, 2024-03-26:
I think there is actually something wrong with my unit, because even after disconnecting my Faikin I have strange fan behaviour
- in Heating mode, I can only select Auto fan. It is not possible to choose Silent of any of the manual fan modes. Not with the Onecta app, but also not the remote control. I actually noticed this issue already right after the install, because I thought it was Onecta related.
- in other modes, it does work though
- my other 4 units are Stylish (with the old local API wifi module) and everything works fine there.

So, there is no point to let you debug if there is most probably something wrong with my unit.

But Daikin support will be a tough cookie, I'm afraid

migueldc73, 2024-03-26:
it might also be that because I used Pin 1 (5V, probably reference) as power source for the Faikin, that it somehow makes the TX/RX voltage variations flaky, resulting in flaky serial communication.

So, does anybody know of any other source of 5-15V power on the Daikin board ?
With enough amps obviously,

revk, 2024-03-26:
It should not, we drive low, using the internal pull up on the Tx, and the Rx goes in to a FET, so both should be fine whatever power we run from. Only other possible is maybe also connecting the 5V to pin 1 as that will then add a pull up to 5V on the Faikin side.

migueldc73, 2024-03-26:
OK, so we have now contained and identified that
1) using 5V instead of 15V ps is not an issue as long as the Faikin boots and runs
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
migueldc73, 2024-03-26:
Well, I actually integrated the Faikin directly into Daikin AC local integration into HA.
That's maybe why Mosquitto didn't recognize it, either one or the other.

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

Is the Daikin AC integration logfile useful to you ?

migueldc73, 2024-03-26:
I have to admit that everything seems to be working fine now, apart from the one issue that is when changing from any of the modes to heating mode, this fan error pops up in HA (as well as in the Faikin web interface)

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

migueldc73, 2024-03-26:
Update :
- this fan mode message actually always appears after changing any mode (so not only heating) and changing temperature.
- You then see the dot (undefined fan mode)
- after 5-10 seconds, HA corrects itself and the actual mode (auto, silent, 1-5) appears and it all seems to work as it should

Seems like a status feedback issue on the fan state.

MUN0X, 2024-03-26:
> I have to admit that everything seems to be working fine now, apart from the one issue that is when changing from any of the modes to heating mode, this fan error pops up in HA (as well as in the Faikin web interface)
>
> ![Screenshot_20240326_164941_Home Assistant](https://private-user-images.githubusercontent.com/107763234/316943431-70cd4bd7-bd2a-41f8-a50d-1b876fed088e.jpg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)

Unrelated question bit how did you configure that mushroom card?

migueldc73, 2024-03-26:
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

It's the new Tile Card, available since a few months on HA. I am quite happy with it, considering I make most of my cards completely with custom yaml code

MUN0X, 2024-03-26:
Nice! Missed that introduction completely. Might have to redo my heating dashboard now 😀

migueldc73, 2024-03-27:
Everything work fine for 24hours and I thought I was out of the storm, but something weird happened just now
- can't access the Faikin over the local IP address
- I can ping it though
- MQTT in Home Assistant is working fine (no fan errors)
- Daikin HA integration is not working though (worked fine yesterday, allthough with the fan error)
- rebooting Faikin (so power off through the mains and back on) solves the issue

It seems like the Faikin state gets corrupted. So I wonder
- known bug ?
- wrong setting (will send screenshots in a min)
- not enough amps on the 5V (but then I guess it would just power off and not even be pingable...)
- something wrong with my Faikin ?

migueldc73, 2024-03-27:
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

sjaakie09, 2024-03-27:
mine has also this issue can't access the Faikin over the local IP address
I can't  ping it though the last known address? and also not with lan scan?
is there an other way to find the unit it also does not been shown with the host name?

MUN0X, 2024-03-27:
I had the same problem a few days ago with 1 of my faikins. Worked fine via mqtt, webinterface was not available. Unplugging it resolved the issue.

migueldc73, 2024-03-27:
Would be nice if we get fix for this because I actually like the Faikin HA integration

Pro Daikin HA :
- responsiveness
- See the fan states with same naming convention as Daikin : Auto, 12345 and Indoor Silent
- it's elegant to see my Emura integration next to the other Daikin's with the old local API wifi module

Pro MQTT
- Offers more functionality (actually all of them)
- no annoying fan error bug

revk, 2024-03-28:
I am not sure I understand your fan issue. Does it not work even via the Faikin web interface.

By the way, "silent" is a known issue, and a problem with the underlying S21 protocol, but other fan modes should all work as expected.

revk, 2024-03-28:
New beta.

1. I have changed `temptrack` to mean basing target on Daikin measured temp
2. I have added `tempadjust` to mean applying the adjustment for Daikin measured not being external measured

migueldc73, 2024-03-28:
> I am not sure I understand your fan issue. Does it not work even via the Faikin web interface.
>
> By the way, "silent" is a known issue, and a problem with the underlying S21 protocol, but other fan modes should all work as expected.

I will make a detailed report later today, but I suppose it's better we start a new thread for this, right ?

Closed 2024-05-06.

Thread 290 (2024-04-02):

[FEATURE] Modulate hvac_action (Home Assistant) based on fan and compressor activity

sm-Fifteen, 2024-04-02:
**Daikin hardware**
Two FTXS12LVJU heads (connected to the same multiizone compressor) with one Faikin each, plugged over S21 port

**Is your feature request related to a problem? Please describe.**

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

On Home Assistant's climate history graphs, my heatpumps appear to be running constantly so long as they are turned on, even though the fan and compressor activity graph shows pretty clearly that it's not actually running for most of that time. (Note: despite the names, both these controllers are connected to the same compressor)

**Describe the solution you'd like**
Even with no direct marker of demand, fan and compressor activity could be enough to guess what the indoors unit is doing.

* In heating mode
  * Fan & compressor running: Heating
  * Compressor running but no fan: Defrosting/Hot start (`HVACAction.PREHEATING`) or possibly idle on a multizone if a different head is runnning
    * Could pe possible to distinguist between each if demand is available?
    * Unclear (to me) how individual Faikin controllers could be aware of the state of other heads on the same pump.
  * Compressor and fan not running: Idle (`HVACAction.IDLE`)
  * Fan running but not compressor: Unclear, but you can see it happen in the graph. Might just go with `HVACAction.FAN`
* In cooling mode
  * Mostly the same, but with cooling (`HVACAction.COOLING`)
* So on for dehumidify (`HVACAction.DRYING`) and fan-only
* Off is obviously just `HVACAction.OFF`

**Describe alternatives you've considered**
I believe the "demand" field normally provides that information in a more accurate way, but as I found out while investigating  #101, it turns out that my unit not only doesn't have energy metering (or it's at the very least not being reported), but also does not report demand or powerful mode (among others).

```js
{
  "G1": "16FA", // Status, currently Fan-only, target 21C, powerful
  "G2": "=;\u0000\u0080",  // Unknown
  "G3": "0þþ\u0000", // Timer
  "G4": "0\u0000\u0080\u0000",  // Unknown
  "G5": "2?0\u0080", // Swing
// No G6 : Active modes (powerful, quiet, comfort airflow, flash streamer, intelligent eye)
// No G7 : Current demand, econo mode
  "G8": "0\u0000\u0000\u0000", // Unknown
// No G9 : Demand
// No other G
  "SH": "542+",
  "SI": "062+",
  "Sa": "090+",
  "SL": "980",
  "Sd": "000",
  "SN": "440+",
  "SM": "440+",
  "SX": "012+",
  "SD": "000"
}
```

Not being able to read demand is unfortunate (it looks to be about how much each indoor unit is reporting to the compressor that it wants to heat/cool), because  I was hoping to use that in home assistant to more accurately track when each is actually heating or cooling. It might still prove useful for other users, though, assuming the metric says what I think it does.

revk, 2024-04-02:
In this just the hvac action field?

I added that to show what the "Faikin auto" mode is doing, as it was apparently not clear.

It is not trying to actually work out what is going on otherwise.

MUN0X, 2024-04-02:
What you describe will most likely not work for multi-splits.

Also dont forget that units have a “searching” routine when idle. They will turn their fan on for 1,5min every 6 minutes.
In your logic this will trigger “heating” while another unit is active.

sm-Fifteen, 2024-04-02:
In this just the hvac action field?
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

I prefer leaving the units in default Daikin config rather than mamaged Faikin config, personally. One of the downsides of the Home Assistant HVAC integration is that you can't (AFAICT) make your own custom sensors, so if this sort of introspection isn't provided by the device, you can't make that kind of "algorithm" work with local config.

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

Is this what these little fan spikes mean? Can you describe in more detail what that behavior is and why you think it would make such a heuristic not work properly?

sm-Fifteen, 2024-04-02:
I actually tried putting a custom state tracker together, and it looks mostly reliable so far, for what it's worth.

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

It's basically just tracking the variables I mentionned before:
* Is compressor running? (hz > 0)
* Is fan running? (hz > 0)
* Is coolant warm? (temp > 15°C)

And then I try making a truth table of the probable action for the given combo of variables at every HVAC mode (currently just heating, as this was a quick test written on my phone).

It's not perfect, you can see an orange sliver in the second screenshot where the compressor and fan are both running, but the fluid is still colder than 15°C. It also can't distinguish between the "stand by for defrost" and "stand by for warmup" phase, but there's no HVAC action that woukd distinguist the two, so that's probably fine. I think it's looking like a promising heuristic, and certainly better than making it look like it's heating all the time.

sm-Fifteen, 2024-04-02:
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

Interesting, good to know. I would have to check if this is a fan speed that units normally reach down to in any mode, as the service manual (for my unit at least) seems to say there is an "LLL speed" that the automatic fan setting will never reach (unclear whether that includes night/quiet/motion sensor away mode, though "SL speed" seems more likely).

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

If that's what the units use for that "searching routine", and nothing else, there might be a way of identifying and discarding these, though I understand that this may probe tricky, as this is the sort of behavior that can vary between units. Even if it can't be done, though, and these short fan bursts to circulate the air intake are erroneously seen as heating activity, I would still consider it an improvement over the current state of things.

sm-Fifteen, 2024-04-04:
> > One of the downsides of the Home Assistant HVAC integration is that you can't (AFAICT) make your own custom climate sensors, so if this sort of introspection isn't provided by the device, you can't make that kind of "algorithm" work with local config.
>
> I use this via HACS: https://github.com/jcwillox/hass-template-climate to make scripted climate wrapper entities with custom logic

Actually, having looked into it a bit more, since these are MQTT devices, I may be able to declare custom devices that point towards the same topics as the originals and replace the `action_template`, at least for testing while figuring out the logic. Haven't had any luck so far, though, and testing detection of the defrost cycle is going to get trickier as we move into spring.

Also, HAss' [HVAC MQTT entities](https://www.home-assistant.io/integrations/climate.mqtt/) don't currently have the "preheating" action, so defrosting would have to be labeled as either cooling or drying.

sm-Fifteen, 2024-04-05:
The truth table of states I had in mind goes like this:
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
trullock, 2024-04-05:
@sm-Fifteen Please share your HA implementation :)

sm-Fifteen, 2024-04-05:
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

Would you accept a PR if were to get a Faikin implementation working?

> @sm-Fifteen Please share your HA implementation :)

It's just a "Data entry" template object that uses Jinja logic to return a string matching the current state. I haven't been able to make an HVAC entity reflect that yet.

revk, 2024-04-05:
I'd rather some S21 that provides the state.

sm-Fifteen, 2024-04-05:
> I'd rather some S21 that provides the state.

Understandable, and I would rather go with that myself, but the power meter thing (specifically how my unit doesn't report it, nor powerful mode), combined with how Daikin's own thermostats don't seem to display that info is all making me start to think that there could very well not be any S21 flag for that.

Assuming there isn't, you would rather report nothing at all, outsite of Faikin's auto mode?

revk, 2024-04-05:
Well for now, it seems a lot of guess work to get anything remotely correct, to me.

There is a lot in S21 we do not understand and one thing I am planning it more tests and documentation.

sm-Fifteen, 2024-04-05:
> Well for now, it seems a lot of guess work to get anything remotely correct, to me.
>
> There is a lot in S21 we do not understand and one thing I am planning it more tests and documentation.

That's fair. I did notice the wiki page documentaing S21 seems to be somewhat behind what the code knows how to handle, so that would definitely be a good thing. It might also be a good thing to list what official devices were tested to find these signals, in case there are some interesting ones that have yet to be tried (like Daikin One adapters + thermostats or ~~the [wired navigation remote](http://4ae617e62d.nxcli.net/content/commercial/accessories-and-controllers/navigation-remote-control-brc1e73brc1e72brc1e52a7/)~~ nevermind, that's P1P2-only).

The logic I'm proposing isn't as complicated and "guessy" as it may look, since at its core it's mostly "if stuff is spinning and the liquid's hot, then it's heating, and if it's cold we're cooling", with a few edge cases and the added ambiguity of dealing with multi-zone systems.

revk, 2024-04-05:
As long as you are not trying to Jia Tan me, I'll maybe take a look.

hubrikt, 2024-04-20:
Is there any way to stop reporting "HVAC_Action" in HomeAssistant?

@sm-Fifteen have you been able to prepare the template in HA to define your truth table?
Thanks!

revk, 2024-04-20:
Setting `nohvacaction`

sm-Fifteen, 2024-04-22:
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

@hubrikt : I tried, but no luck. The correct hvac_action does show up in the state viewer in the dev tools, but the UI amd sensors don't reflect it. Looks like this is for display purposes only, and the actual state needs to come from the MQTT topic.

For good measure, here's what I was using in my HAss config:

```yaml
homeassistant:
    customize:
        climate.faikin_entree_mqtt_hvac:
            action_topic: DC9999EEEEEE
            action_template: |
                {% set fan_running = value_json.fanfreq > 0 %}
                {% set comp_running = value_json.comp > 0 %}
                {% set liquid_warm = value_json.liquid > 10 %}
                {% if value_json.mode == 'off' -%}
                    "off"
                {%- elif value_json.mode == 'fan_only' -%}
                    {% if fan_running -%}
                        fan
                    {%- else -%}
                        idle
                    {%- endif %}
                {%- elif value_json.mode == "heat" -%}
                    {% if not comp_running -%}
                        idle
                    {%- elif not fan_running -%}
                        idle
                    {%- elif fan_running and liquid_warm -%}
                        heating
                    {%- else -%}
                        cooling
                    {%- endif %}
                {%- endif %}
```

It doesn't do anything useful (it sets the entity's state attributes according to the dev tools, but that's not recognized by the HVAC integration) and doesn't implement cooling and dry modes, but it shows the logic I was going for.

sm-Fifteen, 2024-09-05:
I hope we can find a "native" way of doing this as part of #408. Home Assistant just added a "defrost" action as  complement to the existing "preheat" action, and while it's not mentionned in the [MQTT climate documentation](https://www.home-assistant.io/integrations/climate.mqtt/), there are tests in home-assistant/core#121448 which show that it would be recognized.

Closed 2024-04-05.

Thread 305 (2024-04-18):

FXDQ32A3VEB  (FXDQ-A3) doesn't have X50A or S21 port (wiring diagram attached)

alexcf, 2024-04-18:
I've got a FXDQ32A3VEB (i think 4 actually!), which are connected to a Madoka (piece of shit*) controllers. Looks like they're using the Diii-Net method to connect them.

Looking at the board, I've got an X35A for power, but no X50A for comms. The notes say: X24A (wireless controller), X33A (adapter for wiring) and X38A (multi-tenant connector) - is X24A interchangeable with the S21? Pic attached.

\* why anyone in their right mind would think building a BLE based controller was a good idea needs a good talking to.
PS. RevK - great work :)
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

geni0602, 2024-04-18:
Did you try to measure the voltage on the x24a?
https://github.com/revk/ESP32-Faikin/wiki/Wiring#connector
Do you get 5v pin1 and 12-14v Pin 4 GND is pin 5?

alexcf, 2024-04-18:
OK, so closer inspection on the board (also finding out that my multimeter is broken), I noticed there is an X50A but it's not listed on the wiring diagram. I'm still going to test the voltage on those pins though, but... After a bit more digging, it looks like the X24A is designed for the infrared remote control, so generally just a receiver :(

alexcf, 2024-04-27:
Confirmed all working!

alexcf, 2024-04-27:
I was wrong. I couldn't get this working. It seems like the X50A isn't wired in. :(

yiannosi, 2024-10-19:
Did you find a solution? I think I am facing a similar problem..

Closed 2024-04-27.

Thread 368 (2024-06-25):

[BUG] - 'dict object' has no attribute

1mfaasj, 2024-06-25:
**Faikin hardware**
Bought from Amazon.co.uk

**Daikin hardware**
- BRP069C4x
- connected the faikin device in the S21 port.

**Describe the bug**
my Home Assistant log reports these warnings, very often. Similar to https://github.com/revk/ESP32-Faikin/issues/365 but now for different attributes. It began actually when you asked me to switch to beta and I enabled Additional HA switches.
now I switched back to 'normal' but the warnings stays.

```
Template variable warning: 'dict object' has no attribute 'power' when rendering '{{value_json.power}}'
Template variable warning: 'dict object' has no attribute 'streamer' when rendering '{{value_json.streamer}}'
```

I already used powerful mode and stream/filter options in the faikin interface:
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
but the warnings stays

when I execute
state/FaikinZolder1/ha
it gives me:
```
{
  "online": true,
  "target": 25,
  "temp": 24.5,
  "outside": 24,
  "liquid": 24.5,
  "comp": 0,
  "demand": 100,
  "Wh": 268700,
  "fanfreq": 0,
  "mode": "off",
  "fan": "auto",
  "swing": "off",
  "preset": "home"
}
```

revk, 2024-06-25:
`power` is not `powerful`

But odd. Does it all go away if you turn it on?

1mfaasj, 2024-06-25:
No, I've tried every option

revk, 2024-06-25:
- Ok what status is HA looking for?
- What does the status post have on MQTT?
- Are you on latest beta?

1mfaasj, 2024-06-25:
Hi the warning above disappeared when I clicked on some buttons, but after testing further with beta the mqtt device becomes unavailable in HA. Even after a reboot of the faikin device, HA or completely power off-on doesnt recover it.
After switching back to Normal release it is available again. I did this three times now (normal to beta and visa versa)
Any idea what is causing this?
It works when I use the Faikin interface by its IP address. Only not in HA.
No logs in HA about the unavailable state.

1mfaasj, 2024-06-25:
Looks similar https://github.com/revk/ESP32-Faikin/issues/369

revk, 2024-06-26:
I don't understand how, but the current beta release was built with an old version of the library that broke availability.

1mfaasj, 2024-06-26:
ok let me know if I can test

revk, 2024-06-26:
The beta is done, so yeh, test.

1mfaasj, 2024-06-27:
looks like the issue is resolved with the latest beta (both). thanks!

Closed 2024-06-27.

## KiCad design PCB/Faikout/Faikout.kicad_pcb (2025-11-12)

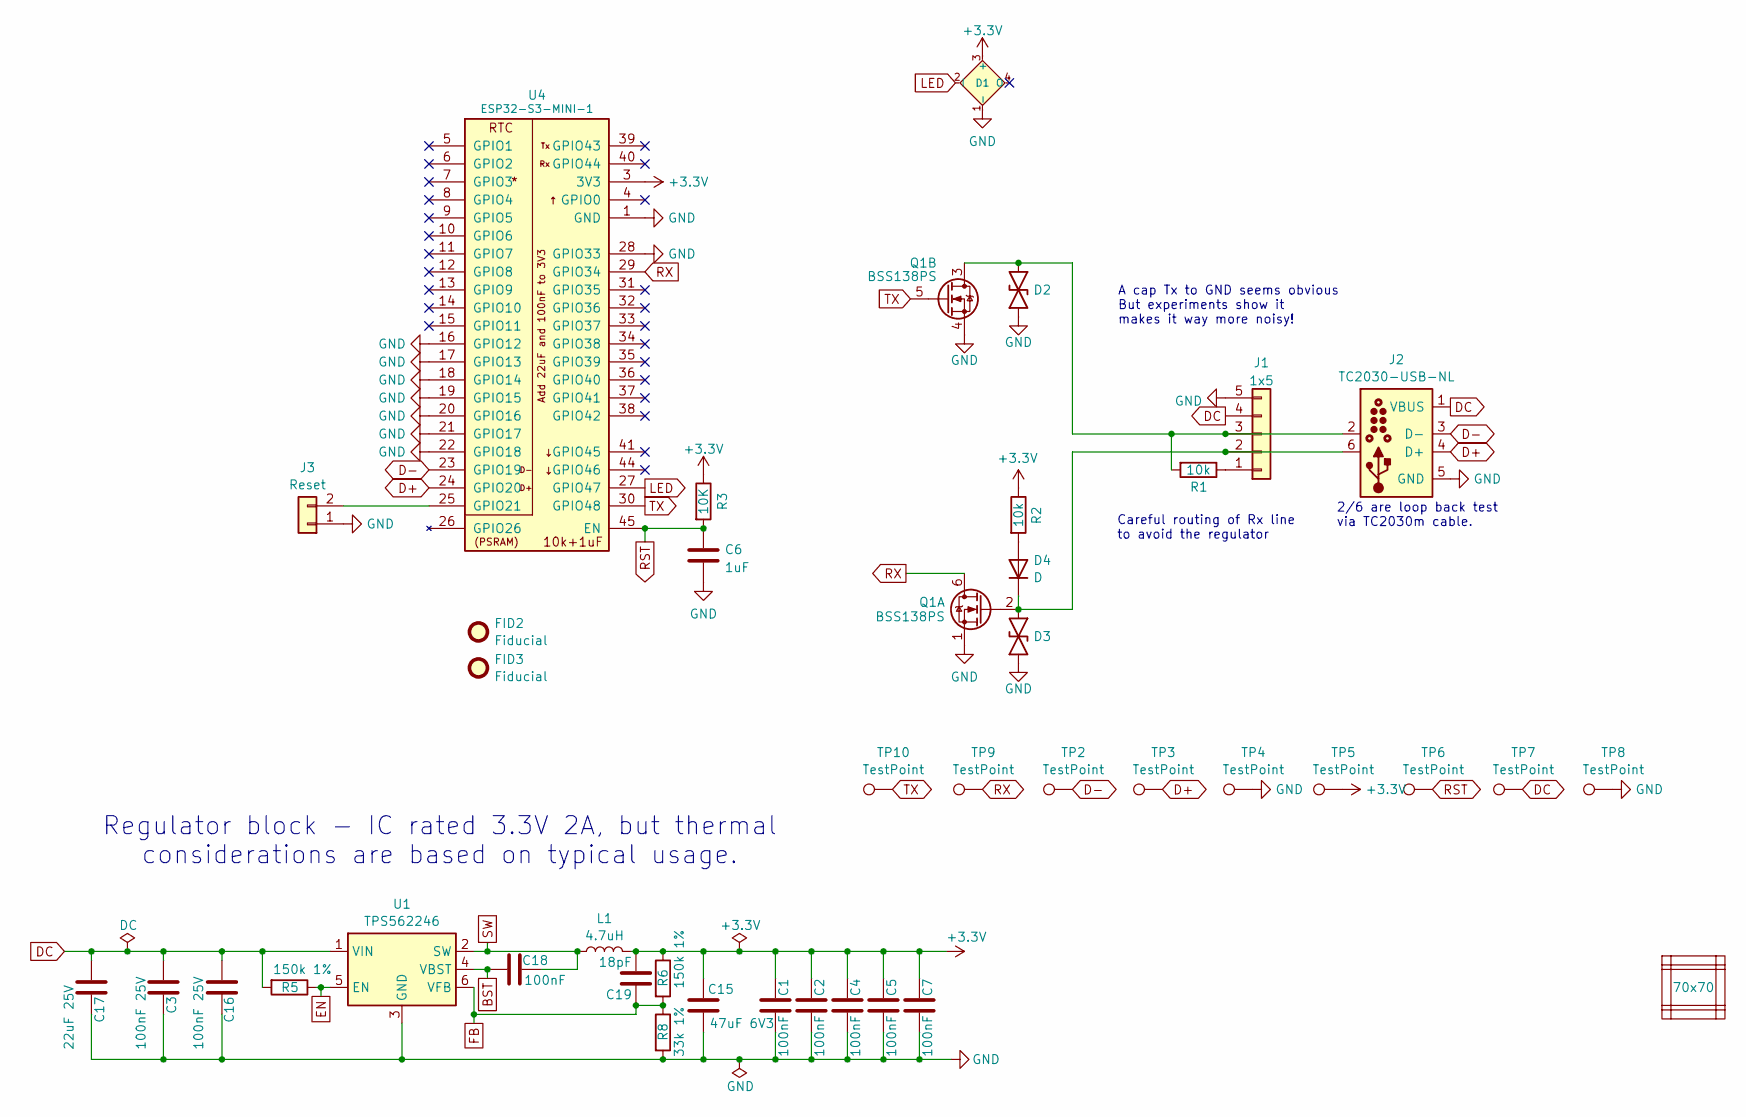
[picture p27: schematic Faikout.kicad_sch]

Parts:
C1, C2, C4, C5, C7, C18: 100nF; C_0201; MPN C76934
C3, C16: 100nF 25V; C_0402; MPN C56392
C6: 1uF; C_0201
C15: 47uF 6V3; C_0805; MPN C16780
C17: 22uF 25V; C_0805; MPN C45783
C19: 18pF; C_0201; MPN C62164
D1: XL-1615RGBC-2812B; SMD1615; MPN C5349954
D2, D3: DFN1006-2L; MPN C5137770
D4: D; D_0402; MPN C28642302
FID2, FID3: Fiducial; Fiducial_1mm_Mask2mm
J1: 1x5; JST_EH_S5B-EH_1x05_P2.50mm_Horizontal; MPN C265103
J2: TC2030-USB-NL; Tag-Connect_TC2030-IDC-NL_2x03_P1.27mm_Vertical
J3: Reset; AA-Pad
L1: 4.7uH; L_5x5; MPN C307876
PCB1: 70x70; PCB7070
Q1: BSS138PS; SOT-363_SC-70-6; MPN C193381
R1, R2: 10k; R_0201; MPN C106225
R3: 10K; R_0201; MPN C106225
R5, R6: 150k 1%; R_0201; MPN C310173
R8: 33k 1%; R_0201; MPN C320835
TP2, TP3, TP4, TP5, TP6, TP7, TP8, TP9, TP10: TestPoint; PAD-2mm
U1: TPS562246; SOT-563; MPN C41833479
U4: ESP32-S3-MINI-1; MPN C3013941
V1, V2, V3, V4, V5, V6: VCUT70N

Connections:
+3.3V: C1.2, C2.2, C4.2, C5.2, C7.2, C15.1, C19.2, D1.3 (+), L1.2, R2.1, R3.1, R6.1, TP5.1, U4.3 (3V3)
BST: C18.1, U1.4 (VBST)
D+: J2.4 (D+), TP3.1, U4.24 (GPIO20)
D-: J2.3 (D-), TP2.1, U4.23 (GPIO19)
DC: C3.1, C16.1, C17.1, J1.4, J2.1 (VBUS), R5.2, TP7.1, U1.1 (VIN)
EN: R5.1, U1.5 (EN)
FB: C19.1, R6.2, R8.1, U1.6 (VFB)
GND: C1.1, C2.1, C3.2, C4.1, C5.1, C6.2, C7.1, C15.2, C16.2, C17.2, D1.1 (-), D2.1, D3.1, J1.5, J2.5 (GND), J3.1, Q1.1 (SN), Q1.4 (DP), R8.2, TP4.1, TP8.1, U1.3 (GND), U4.1 (GND), U4.2 (GND), U4.16 (GPIO12), U4.17 (GPIO13), U4.18 (GPIO14), U4.19 (GPIO15), U4.20 (GPIO16), U4.21 (GPIO17), U4.22 (GPIO18), U4.28 (GPIO33), U4.42 (GND), U4.43 (GND), U4.46 (GND), U4.47 (GND), U4.48 (GND), U4.49 (GND), U4.50 (GND), U4.51 (GND), U4.52 (GND), U4.53 (GND), U4.54 (GND), U4.55 (GND), U4.56 (GND), U4.57 (GND), U4.58 (GND), U4.59 (GND), U4.60 (GND), U4.61 (GND), U4.62 (GND), U4.63 (GND), U4.64 (GND), U4.65 (GND)
LED: D1.2 (I), U4.27 (GPIO47)
unnamed: D4.2 (A), R2.2
unnamed: D3.2, D4.1 (K), J1.2, J2.6, Q1.2 (GN)
unnamed: J1.1, R1.1
unnamed: D2.2, J1.3, J2.2, Q1.3 (SP), R1.2
unnamed: J3.2, U4.25 (GPIO21)
RST: C6.1, R3.2, TP6.1, U4.45 (EN)
RX: Q1.6 (DN), TP9.1, U4.29 (GPIO34)
SW: C18.2, L1.1, U1.2 (SW)
TX: Q1.5 (GP), TP10.1, U4.30 (GPIO48)

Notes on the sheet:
Careful routing of Rx line to avoid the regulator
2/6 are loop back test via TC2030m cable.
A cap Tx to GND seems obvious But experiments show it makes it way more noisy!
Regulator block - IC rated 3.3V 2A, but thermal considerations are based on typical usage.

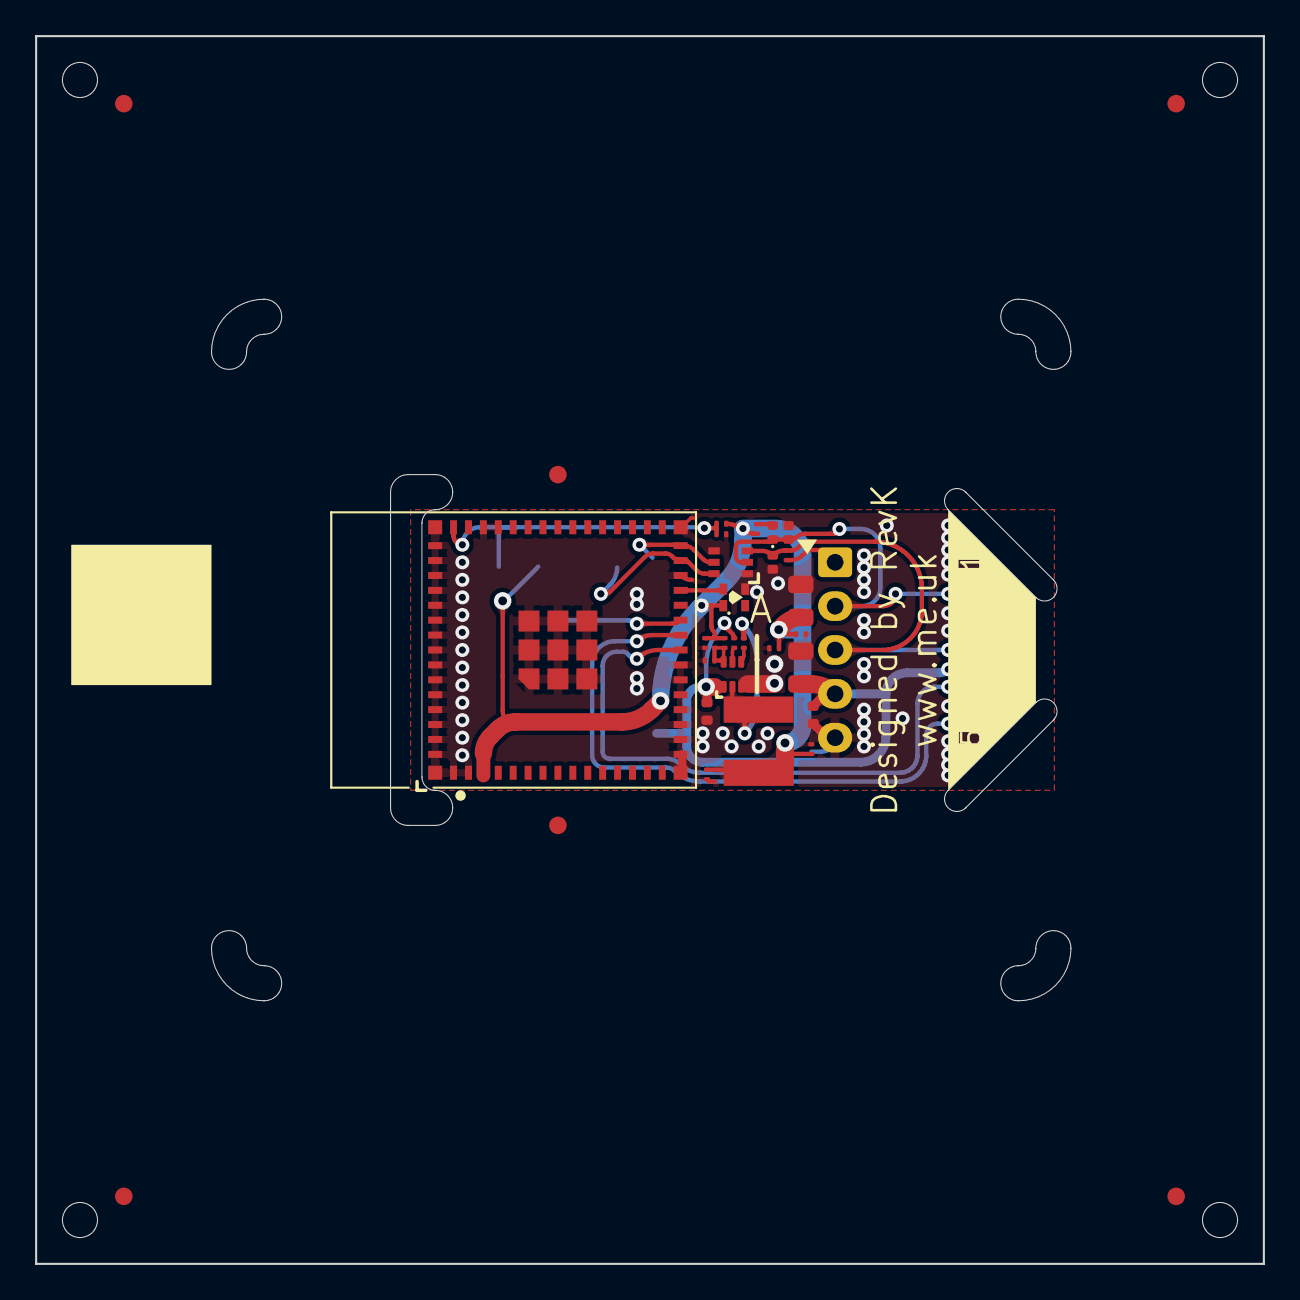
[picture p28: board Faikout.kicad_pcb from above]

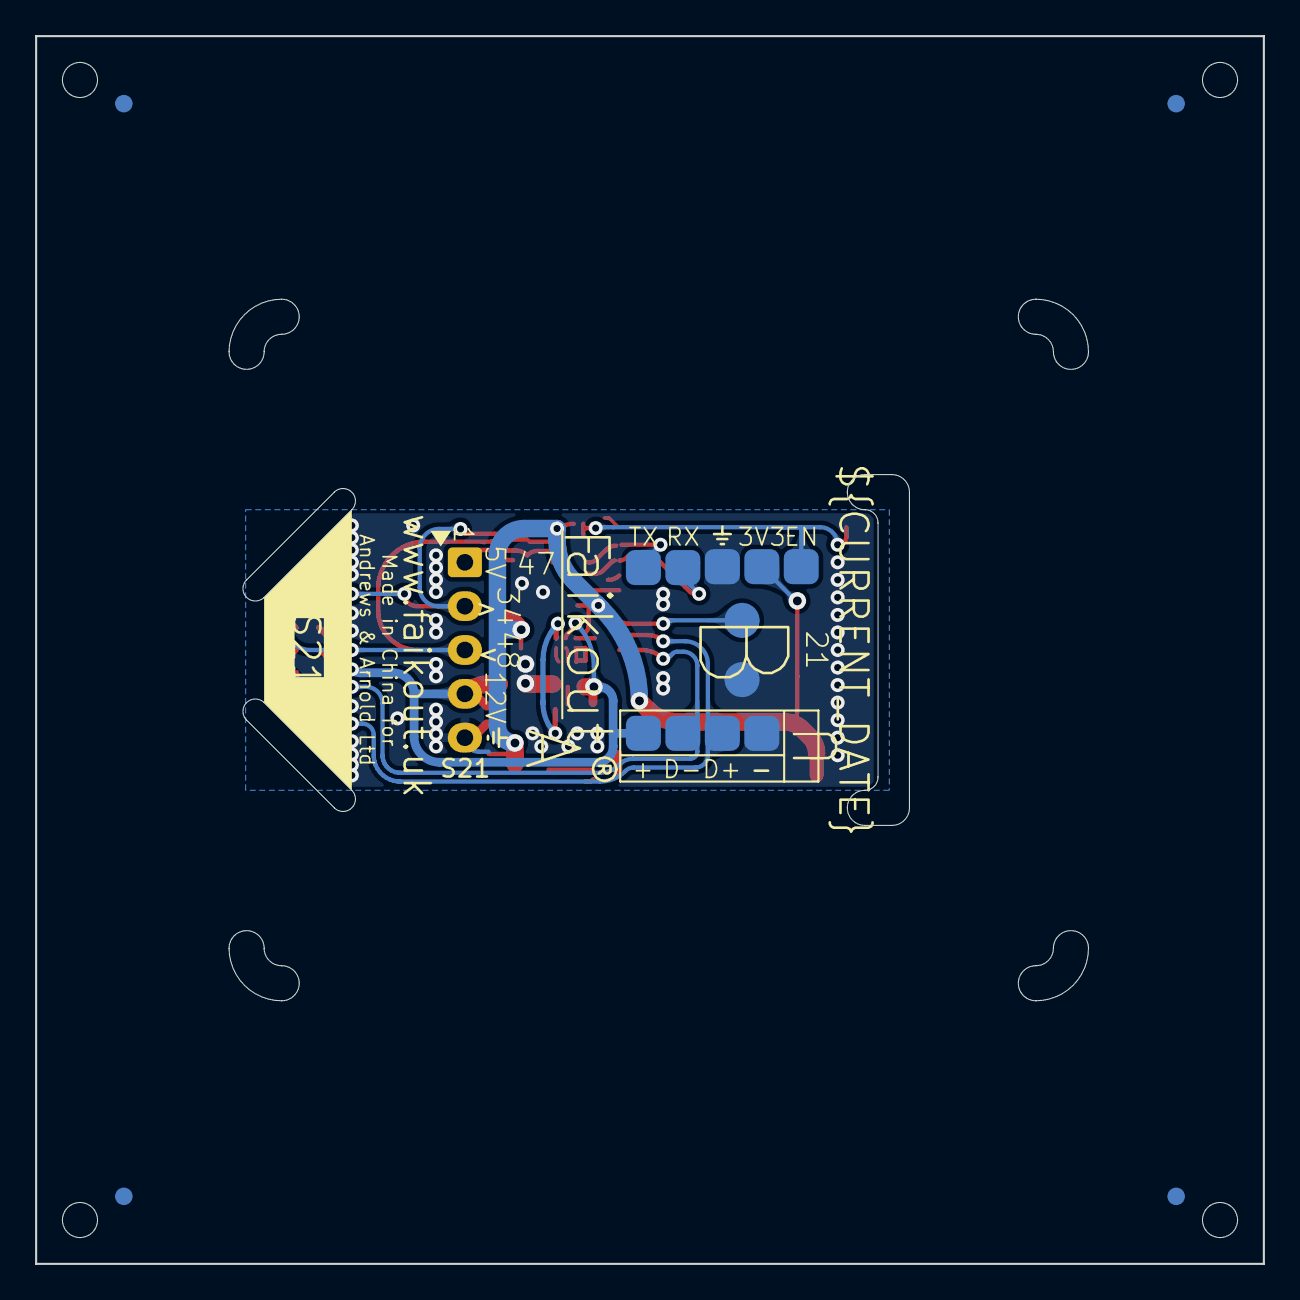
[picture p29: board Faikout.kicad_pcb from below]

Board: 2 copper layers, 70.0 x 70.0 mm, 47 parts (12 on the bottom side), 18 nets.

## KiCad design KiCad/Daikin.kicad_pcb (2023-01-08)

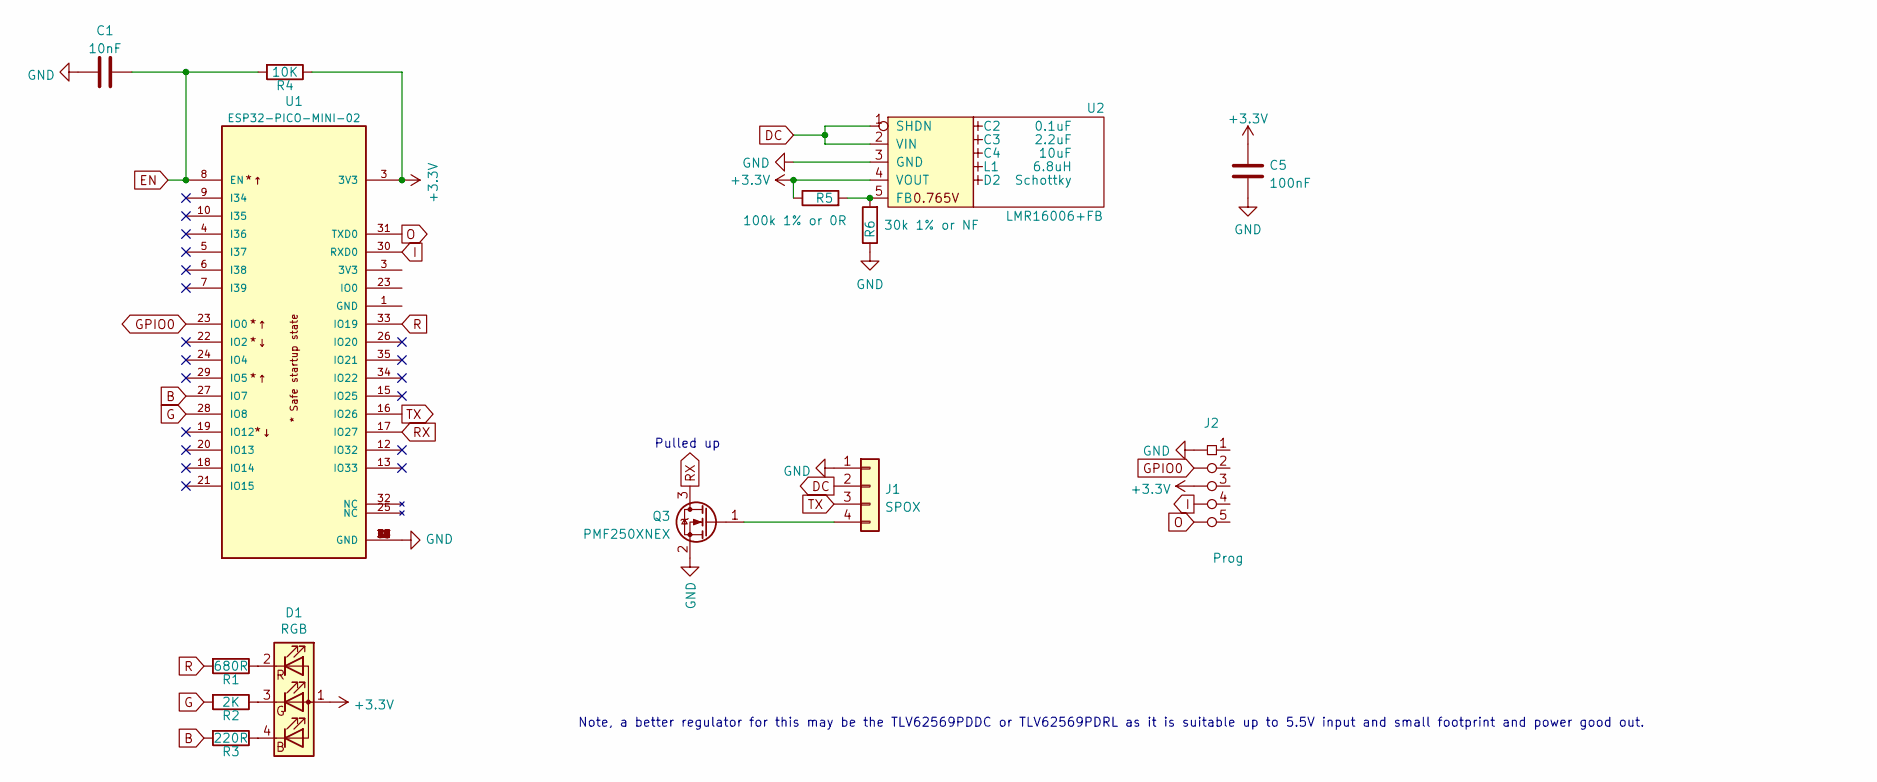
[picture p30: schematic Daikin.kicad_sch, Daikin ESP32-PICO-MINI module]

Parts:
C1: 10nF; C_0603; Part No 0603-10nF-50V
C2: 0.1uF; C_0603_; Part No 0603-100nF-50V
C3: 2.2uF; C_0805_; Part No 0805-2.2uF-25V
C4: 10uF; C_0805_; Part No 0805-10uF-16V
C5: 100nF; C_0603; Part No 0603-100nF-25V
D1: RGB; LED-RGB-1.6x1.6; Part No APTF1616LSEEZGKQBKC
D2: Schottky; D_1206_; Part No CD1206-B2100
J1: SPOX; Molex_MiniSPOX_H4RA; Part No 22057025
J2: Prog; Shelly
L1: 6.8uH; L_4x4_; Part No TYA40206R8M-10
Q3: PMF250XNEX; SOT-323_SC-70; Part No PMF250XNEX
R1: 680R; R_0603; Part No 0603-680R
R2: 2K; R_0603; Part No 0603-2K
R3: 220R; R_0603; Part No 0603-220R
R4: 10K; R_0603; Part No 0603-10K
R5: 100k 1% or 0R; R_0603; Part No 0603-100k
R6: 30k 1% or NF; R_0603; Part No 0603-30k
U1: ESP32-PICO-MINI-02; PARTREV v1.0
U2: LMR16006+FB; SOT-23-Thin-6-Reg; Part No LMR16006YQ3

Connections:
+3V3: C5.1, D1.1 (A), J2.3 (3V3), R4.1, R5.1, U1.3 (3V3), U2.4 (VOUT)
B: R3.2, U1.27 (IO7)
DC: J1.2, U2.1 (SHDN), U2.2 (VIN)
EN: C1.2, R4.2, U1.8 (EN)
G: R2.2, U1.28 (IO8)
GND: C1.1, C5.2, J1.1, J2.1 (GND), Q3.2 (S), R6.1, U1.1 (GND), U1.2 (GND), U1.11 (GND), U1.14 (GND), U1.36 (GND), U1.37 (GND), U1.38 (GND), U1.39 (GND), U1.40 (GND), U1.41 (GND), U1.42 (GND), U1.43 (GND), U1.44 (GND), U1.45 (GND), U1.46 (GND), U1.47 (GND), U1.48 (GND), U1.49 (GND), U1.50 (GND), U1.51 (GND), U1.52 (GND), U1.53 (GND), U2.3 (GND)
GPIO0: J2.2 (0), U1.23 (IO0)
I: J2.4 (Rx), U1.30 (RXD0)
unnamed: D1.2 (RK), R1.1
unnamed: D1.3 (GK), R2.1
unnamed: D1.4 (BK), R3.1
unnamed: J1.4, Q3.1 (G)
unnamed: R5.2, R6.2, U2.5 (FB)
O: J2.5 (Tx), U1.31 (TXD0)
R: R1.2, U1.33 (IO19)
RX: Q3.3 (D), U1.17 (IO27)
TX: J1.3, U1.16 (IO26)

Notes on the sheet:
Pulled up
Note, a better regulator for this may be the TLV62569PDDC or TLV62569PDRL as it is suitable up to 5.5V input and small footprint and power good out.

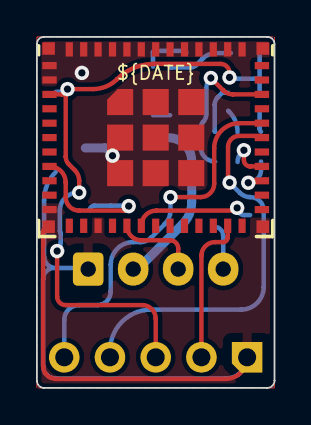
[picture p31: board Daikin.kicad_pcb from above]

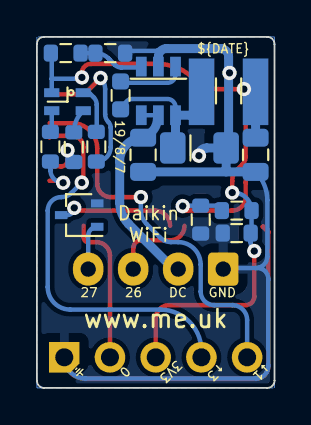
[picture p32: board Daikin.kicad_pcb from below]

Board: 2 copper layers, 13.2 x 19.5 mm, 19 parts (17 on the bottom side), 17 nets.

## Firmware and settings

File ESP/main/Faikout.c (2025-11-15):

/* Faikout app */
/* Copyright ©2022 Adrian Kennard, Andrews & Arnold Ltd. See LICENCE file for details .GPL 3.0 */

static const char TAG[] = "Faikout";

#include "revk.h"
#include "esp_sleep.h"
#include "esp_task_wdt.h"
#include <driver/gpio.h>
#include <driver/uart.h>
#include "esp_http_server.h"
#include <math.h>
#include "mdns.h"
#ifdef CONFIG_BT_NIMBLE_ENABLED
#include "bleenv.h"
#endif
#include "cn_wired.h"
#include "cn_wired_driver.h"
#include "daikin_s21.h"
#include "halib.h"

#ifdef  CONFIG_IDF_TARGET_ESP32S3
#include <driver/usb_serial_jtag.h>
#else
#define usb_serial_jtag_is_connected() (0)
#endif

#ifndef	CONFIG_HTTPD_WS_SUPPORT
#error Need CONFIG_HTTPD_WS_SUPPORT
#endif

#if 1
#define	SWING_OFF		"off"
#define	SWING_ON		"on"
#define	SWING_VERTICAL		"V"
#define	SWING_HORIZONTAL	"H"
#define	SWING_BOTH		"H+V"
#define	SWING_COMFORT		"C"     // Not standard
#else
#define	SWING_OFF		"SWING_OFF"
#define	SWING_ON		"SWING_ON"
#define	SWING_VERTICAL		"SWING_VERTICAL"
#define	SWING_HORIZONTAL	"SWING_HORIZONTAL"
#define	SWING_BOTH		"SWING_BOTH"
#define	SWING_COMFORT		"SWING_COMFORT" // Not standard
#endif

// Macros for setting values
// They set new values for parameters inside the big "daikin" state struct
// and also set appropriate flags, so that changes are picked up by the main
// loop and commands are sent to the aircon to apply the settings
#define	daikin_set_v(name,value)	daikin_set_value(#name,&daikin.name,CONTROL_##name,value)
#define	daikin_set_i(name,value)	daikin_set_int(#name,&daikin.name,CONTROL_##name,value)
#define	daikin_set_e(name,value)	daikin_set_enum(#name,&daikin.name,CONTROL_##name,value,CONTROL_##name##_VALUES)
#define	daikin_set_t(name,value)	daikin_set_temp(#name,&daikin.name,CONTROL_##name,value)

typedef struct poll_s
{
   uint8_t nak:3;               //      Count of NAKs in a row - if too many we set bad
   uint8_t ack:1;               //      We got an ACK so this is valid
   uint8_t bad:1;               //      Too many NAKs, assume not supported
} poll_t;
struct
{                               // Status of S21 messages that get a valid response - this is a count of NAKs, so 0 means working...
   poll_t DH1000;
   poll_t F1;
   poll_t F2;
   poll_t F3;
   poll_t F4;
   poll_t F5;
   poll_t F6;
   poll_t F7;
   poll_t F8;
   poll_t F9;
   poll_t FA;
   poll_t FB;
   poll_t FC;
   poll_t FG;
   poll_t FK;
   poll_t FN;
   poll_t FM;
   poll_t FP;
   poll_t FQ;
   poll_t FS;
   poll_t FT;
   poll_t RD;
   poll_t RG;
   poll_t RI;
   poll_t RM;
   poll_t RL;
   poll_t RN;
   poll_t RH;
   poll_t RX;
   poll_t Ra;
   poll_t Rd;
   uint8_t rgfan:1;             // Use RG for fan
} s21 = { 0 };

// Settings (RevK library used by MQTT setting command)

enum
{                               // Number the control fields
#define	b(name)		CONTROL_##name##_pos,
#define	t(name)		b(name)
#define	r(name)		b(name)
#define	i(name)		b(name)
#define	e(name,values)	b(name)
#define	s(name,len)	b(name)
#include "acextras.m"
};
#define	b(name)		const uint64_t CONTROL_##name=(1ULL<<CONTROL_##name##_pos);
#define	t(name)		b(name)
#define	r(name)		b(name)
#define	i(name)		b(name)
#define	e(name,values)	b(name) const char CONTROL_##name##_VALUES[]=#values;
#define	s(name,len)	b(name)
#include "acextras.m"

enum
{
   PROTO_TYPE_S21,
   PROTO_TYPE_X50A,
   PROTO_TYPE_CN_WIRED,
   PROTO_TYPE_ALTHERMA_S,
   PROTO_TYPE_MAX
};
const char *const prototype[] = { "S21", "X50A", "CN_WIRED", "Altherma_S" };

struct FanMode
{
   char mode;
   const char *name;
};

const struct FanMode fans_5_auto[] = {
   {'A', "auto"},
   {'1', "low"},
   {'2', "lowMedium"},
   {'3', "medium"},
   {'4', "mediumHigh"},
   {'5', "high"},
   {'Q', "night"},
   {0, NULL}
};

const struct FanMode fans_3_auto[] = {
   {'A', "auto"},
   {'1', "low"},
   {0, "lowMedium"},            // Not used
   {'3', "medium"},
   {0, "mediumHigh"},           // Not used
   {'5', "high"},
   {'Q', "quiet"},
   {0, NULL}
};

#define	PROTO_TXINVERT	1
#define	PROTO_RXINVERT	2
#define	PROTO_SCALE	4

// Globals
struct
{
   uint8_t loopback:1;
   uint8_t dumping:1;
   uint8_t hourly:1;            // Hourly stuff
   uint8_t protocol_set:1;
   uint8_t faikouton:1;         // Last faikout power state
   uint8_t startup:1;           // In a startup phase (i.e. full comms not yet confirmed)
} b = { 0 };

static httpd_handle_t webserver = NULL;
static uint8_t proto = 0;

static int
uart_enabled (void)
{
   return tx.set && rx.set;
}

static uint8_t
proto_type (void)
{
   return proto / PROTO_SCALE;
}

static int
invert_tx_line (void)
{
   return tx.invert ^ ((proto & PROTO_TXINVERT) ? 1 : 0);
}

static int
invert_rx_line (void)
{
   return rx.invert ^ ((proto & PROTO_RXINVERT) ? 1 : 0);
}

static const char *
proto_name (void)
{
   return uart_enabled ()? prototype[proto_type ()] : "MOCK";
}

static inline int
fan_5_auto (void)
{                               // Fan is 5 levels and auto
   return fantype == REVK_SETTINGS_FANTYPE_5_LEVEL_AUTO || (fantype == REVK_SETTINGS_FANTYPE_DEFAULT
                                                            && proto_type () == PROTO_TYPE_S21);
}

static inline int
fan_3_auto (void)
{                               // Fan is 3 levels and auto
   return fantype == REVK_SETTINGS_FANTYPE_3_LEVEL_AUTO || (fantype == REVK_SETTINGS_FANTYPE_DEFAULT
                                                            && proto_type () == PROTO_TYPE_CN_WIRED);
}

static const struct FanMode *
get_fan_modes (void)
{
   return fan_3_auto ()? fans_3_auto : fans_5_auto;
}

// Decode fan mode by name into a character (A12345Q)
static char
lookup_fan_mode (const char *name)
{
   const struct FanMode *f;

   for (f = get_fan_modes (); f->name; f++)
   {
      if (!strcmp (name, f->name))
      {
         if (f->mode)
            return f->mode;
         break;                 // The value isn't valid for this protocol
      }
   }

   return *name;                // Fallback
}

static const char *
get_temp_step (void)
{
   switch (proto_type ())
   {
   case PROTO_TYPE_CN_WIRED:
      return "1";
   case PROTO_TYPE_S21:
      return "0.5";
      // TODO(RevK): PROTO_TYPE_ALTHERMA_S
   default:                    // PROTO_TYPE_X50
      return "0.1";
   }
}

#ifdef ELA
static bleenv_t *bletemp = NULL;

static int
ble_sensor_connected (void)
{                               // We actually have BLE configured and connected and not missing
   return (bleenable && bletemp && !bletemp->missing) ? 1 : 0;
}

static int
ble_sensor_enabled (void)
{                               // We have BLE enabled and a BLE sensor defeined
   return (bleenable && *autob) ? 1 : 0;
}

#else // ELA

static int
ble_sensor_connected (void)
{                               // No BLE
   return 0;
}

static int
ble_sensor_enabled (void)
{                               // No BLE
   return 0;
}

#endif // ELA

// The current aircon state and stats
struct
{
   SemaphoreHandle_t mutex;     // Control changes
   uint64_t control_changed;    // Which control fields are being set
   uint64_t status_known;       // Which fields we know, and hence can control
   uint8_t control_count;       // How many times we have tried to change control and not worked yet
   uint32_t statscount;         // Count for b() i(), etc.
#define	b(name)		uint8_t	name;uint32_t total##name;
#define	t(name)		float name;float min##name;float total##name;float max##name;uint32_t count##name;
#define	r(name)		float min##name;float max##name;
#define	i(name)		int name;int min##name;int total##name;int max##name;
#define	e(name,values)	uint8_t name;
#define	s(name,len)	char name[len];
#include "acextras.m"
   float env_prev;              // Predictive, last period value
   float env_delta;             // Predictive, diff to last
   float env_delta_prev;        // Predictive, previous diff
   uint32_t controlvalid;       // uptime to which auto mode is valid
   uint32_t sample;             // Last uptime sampled
   uint32_t countApproaching,
     countApproachingPrev;      // Count of "approaching temp", and previous sample
   uint32_t countBeyond,
     countBeyondPrev;           // Count of "beyond temp", and previous sample
   uint32_t countTotal,
     countTotalPrev;            // Count total, and previous sample
   uint8_t fansaved;            // Saved fan we override at start
   uint8_t talking:1;           // We are getting answers
   uint8_t lastheat:1;          // Last heat mode
   uint8_t status_changed:1;    // Status has changed
   uint8_t mode_changed:1;      // Status or control has changed for enum or bool
   uint8_t status_report:1;     // Send status report
   uint8_t ha_send:1;           // Send HA config
   uint8_t remote:1;            // Remote control via MQTT
   uint8_t hysteresis:1;        // Thermostat hysteresis state
   uint8_t cnresend:2;          // Resends
   uint8_t action:3;            // hvac_action
   uint8_t protocol_ver;        // Protocol version
} daikin = { 0 };

enum
{
   HVAC_OFF,
   HVAC_PREHEATING,
   HVAC_HEATING,
   HVAC_COOLING,
   HVAC_DRYING,
   HVAC_FAN,
   HVAC_IDLE,
   HVAC_DEFROSTING,
};
const char *const hvac_action[] = { "off", "preheating", "heating", "cooling", "drying", "fan", "idle", "defrosting" };

const char *
daikin_set_value (const char *name, uint8_t *ptr, uint64_t flag, uint8_t value)
{                               // Setting a value (uint8_t)
   if (*ptr == value)
      return NULL;              // No change
   if (b.startup && !(daikin.status_known & flag))
      return "Setting cannot be controlled";
   xSemaphoreTake (daikin.mutex, portMAX_DELAY);
   *ptr = value;
   daikin.control_changed |= flag;
   daikin.mode_changed = 1;
   xSemaphoreGive (daikin.mutex);
   return NULL;
}

const char *
daikin_set_int (const char *name, int *ptr, uint64_t flag, int value)
{                               // Setting a value (uint8_t)
   if (*ptr == value)
      return NULL;              // No change
   if (b.startup && !(daikin.status_known & flag))
      return "Setting cannot be controlled";
   xSemaphoreTake (daikin.mutex, portMAX_DELAY);
   daikin.control_changed |= flag;
   daikin.mode_changed = 1;
   *ptr = value;
   xSemaphoreGive (daikin.mutex);
   return NULL;
}

const char *
daikin_set_enum (const char *name, uint8_t *ptr, uint64_t flag, char *value, const char *values)
{                               // Setting a value (uint8_t) based on string which is expected to be single character from values set
   if (!value || !*value)
      return "No value";
   if (value[1])
      return "Value is meant to be one character";
   char *found = strchr (values, *value);
   if (!found)
      return "Value is not a valid value";
   daikin_set_value (name, ptr, flag, (int) (found - values));
   return NULL;
}

const char *
daikin_set_temp (const char *name, float *ptr, uint64_t flag, float value)
{                               // Setting a value (float)
   if (*ptr == value)
      return NULL;              // No change
   if (proto_type () == PROTO_TYPE_CN_WIRED)
      value = roundf (value);   // CN_WIRED only does 1C steps
   else if (proto_type () == PROTO_TYPE_S21)
      value = roundf (value * 2.0) / 2.0;       // S21 only does 0.5C steps
   xSemaphoreTake (daikin.mutex, portMAX_DELAY);
   *ptr = value;
   daikin.control_changed |= flag;
   daikin.mode_changed = 1;
   xSemaphoreGive (daikin.mutex);
   return NULL;
}

void
set_uint8 (const char *name, uint8_t *ptr, uint64_t flag, uint8_t val)
{                               // Updating status
   xSemaphoreTake (daikin.mutex, portMAX_DELAY);
   if (!(daikin.status_known & flag))
   {
      daikin.status_known |= flag;
      daikin.status_changed = 1;
      daikin.ha_send = 1;
   }
   if (*ptr == val)
   {                            // No change
      if (daikin.control_changed & flag)
      {
         daikin.control_changed &= ~flag;
         daikin.status_changed = 1;
      }
   } else if (!(daikin.control_changed & flag))
   {                            // Changed (and not something we are trying to set)
      *ptr = val;
      daikin.status_changed = 1;
      daikin.mode_changed = 1;
   }
   xSemaphoreGive (daikin.mutex);
}

void
set_int (const char *name, int *ptr, uint64_t flag, int val)
{                               // Updating status
   xSemaphoreTake (daikin.mutex, portMAX_DELAY);
   if (!(daikin.status_known & flag))
   {
      daikin.status_known |= flag;
      daikin.status_changed = 1;
      daikin.ha_send = 1;
   }
   if (*ptr == val)
   {                            // No change
      if (daikin.control_changed & flag)
      {
         daikin.control_changed &= ~flag;
         daikin.status_changed = 1;
      }
   } else if (!(daikin.control_changed & flag))
   {                            // Changed (and not something we are trying to set)
      if (*ptr / 10 != val / 10)
         daikin.status_changed = 1;
      *ptr = val;
   }
   xSemaphoreGive (daikin.mutex);
}

void
set_float (const char *name, float *ptr, uint64_t flag, float val)
{                               // Updating status
   xSemaphoreTake (daikin.mutex, portMAX_DELAY);
   if (!(daikin.status_known & flag))
   {
      daikin.status_known |= flag;
      daikin.status_changed = 1;
      daikin.ha_send = 1;
   }
   if (lroundf (*ptr * 10) == lroundf (val * 10))
   {                            // No change (allow within 0.1C)
      if (daikin.control_changed & flag)
      {
         daikin.control_changed &= ~flag;
         daikin.status_changed = 1;
      }
   } else if (!(daikin.control_changed & flag))
   {                            // Changed (and not something we are trying to set)
      *ptr = val;
      daikin.status_changed = 1;
      if (flag == CONTROL_temp)
         daikin.mode_changed = 1;
   }
   xSemaphoreGive (daikin.mutex);
}
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
void
app_main ()
{
   ESP_LOGE (TAG, "Started");
#ifdef  CONFIG_IDF_TARGET_ESP32S3
   {                            // All unused input pins pull down
      gpio_config_t c = {.pull_down_en = 1,.mode = GPIO_MODE_DISABLE };
      for (uint8_t p = 0; p <= 48; p++)
         if (gpio_ok (p) & 2)
            c.pin_bit_mask |= (1LL << p);
      gpio_config (&c);
   }
#endif
   daikin.mutex = xSemaphoreCreateMutex ();
   b.startup = 1;
   daikin.status_known = CONTROL_online;
#define	t(name)	daikin.name=NAN;
#define	r(name)	daikin.min##name=NAN;daikin.max##name=NAN;
#include "acextras.m"
   revk_boot (&mqtt_client_callback);
   revk_start ();
   // Normalising settings
#ifdef  CONFIG_IDF_TARGET_ESP32S3
   if (!factorygpio.set)
   {
      jo_t j = jo_object_alloc ();
      jo_string (j, "factorygpio", "-21");
      revk_settings_store (j, NULL, REVK_SETTINGS_PASSOVERRIDE);
   }
#endif
   if (!strcmp (otahost, "ota.revk.uk") || !strcmp (otahost, "ota.faikin.uk"))
   {
      jo_t j = jo_object_alloc ();
      jo_string (j, "otahost", "ota.faikout.uk");
      revk_settings_store (j, NULL, REVK_SETTINGS_PASSOVERRIDE);
   }

   ESP_LOGD (TAG, "USB %d", usb_serial_jtag_is_connected ());
   if (tx.set && rx.set)
   {                            // Direct loopback check
      revk_gpio_input (rx);
      if (revk_gpio_get (rx))
      {
         ESP_LOGD (TAG, "Rx %d", revk_gpio_get (rx));
         revk_gpio_output (tx, 0);
         if (!revk_gpio_get (rx))
            b.loopback = 1;
         ESP_LOGD (TAG, "Rx %d", revk_gpio_get (rx));
         revk_gpio_set (tx, 1);
      }
   }
   if (usb_serial_jtag_is_connected ())
   {                            // ATE mode
      if (!b.loopback)
         revk_ate_fail ("Loopback fail");
      revk_blink (1, 0, b.loopback ? "G" : "R");
   } else
      revk_blink (1, 0, b.loopback ? "B" : "G");
   revk_ate_pass ();
   revk_blink_do ();            // Show LED ASAP

   if (*autotopic)
      revk_mqtt_sub (0, autotopic, autosub, *autopayload ? autopayload : "env");

   if (udp_discovery)
      revk_task ("daikin_discovery", legacy_discovery_task, NULL, 0);

   b.dumping = dump;

   if (webcontrol || websettings)
   {
      // Web interface
      httpd_config_t config = HTTPD_DEFAULT_CONFIG ();
      config.stack_size += 4096;        // Being on the safe side
      // When updating the code below, make sure this is enough
      // Note that we're also adding revk's own web config handlers
      config.max_uri_handlers = 16 + revk_num_web_handlers ();
      if (!httpd_start (&webserver, &config))
      {
         if (websettings)
            revk_web_settings_add (webserver);
         register_get_uri ("/", web_root);
         register_get_uri ("/apple-touch-icon.png", web_icon);
         register_get_uri ("/favicon.ico", web_favicon);
         if (webcontrol)
         {
            register_get_uri ("/control", web_control);
            register_ws_uri ("/status", web_status);
            register_get_uri ("/common/basic_info", legacy_web_get_basic_info);
            register_get_uri ("/aircon/get_model_info", legacy_web_get_model_info);
            register_get_uri ("/aircon/get_control_info", legacy_web_get_control_info);
            register_get_uri ("/aircon/set_control_info", legacy_web_set_control_info);
            register_get_uri ("/aircon/get_sensor_info", legacy_web_get_sensor_info);
            register_get_uri ("/common/register_terminal", legacy_web_register_terminal);
            register_get_uri ("/aircon/get_year_power_ex", legacy_web_get_year_power);
            register_get_uri ("/aircon/get_week_power_ex", legacy_web_get_week_power);
            register_get_uri ("/aircon/set_special_mode", legacy_web_set_special_mode);
            register_get_uri ("/aircon/set_demand_control", legacy_web_set_demand_control);
            register_get_uri ("/aircon/set_holiday", legacy_web_set_holiday);
         }
         // When adding, update config.max_uri_handlers
      }
   }
#ifdef	ELA
   if (bleenable)
      bleenv_run ();
   else
      esp_wifi_set_ps (WIFI_PS_NONE);
#endif
   if (!uart_enabled ())
   {                            // Mock for interface development and testing
      ESP_LOGE (TAG, "Dummy operational mode (no tx/rx set)");
      daikin.status_known |=
         CONTROL_power | CONTROL_fan | CONTROL_temp | CONTROL_mode | CONTROL_econo | CONTROL_powerful |
         CONTROL_comfort | CONTROL_streamer | CONTROL_sensor | CONTROL_quiet | CONTROL_swingv | CONTROL_swingh;
      daikin.power = 1;
      daikin.mode = 1;
      daikin.temp = 20.0;
   }
   strncpy (daikin.model, model, sizeof (daikin.model));        // Default model
   proto = protocol;
   if (protofix)
      b.protocol_set = 1;       // Fixed protocol - do not change
   else
      proto--;                  // We start by moving forward if protocol not set
   while (1)
   {                            // Main loop
      // We're (re)starting comms from scratch, so set "talking" flag.
      // This signals protocol integrity and actually enables communicating with the AC.
      if (!b.protocol_set && !b.loopback)
      {                         // Scanning protocols - more to next protocol
         proto++;
         if (proto >= PROTO_TYPE_MAX * PROTO_SCALE)
            proto = 0;
         if (proto_type () == PROTO_TYPE_CN_WIRED)
         {
            uint8_t invert_mask;

            if (nocnwired)
               continue;
            // Since CN_WIRED is a passive protocol (receive only, no actual responses),
            // we cannot have idea whether our tx polarity is correct. If we choose a wrong one,
            // the AC won't receive anything, but we'd have no way to detect that.
            // So, here we explicitly ban having different polarities. Invert either all or nothing.
            invert_mask = proto & (PROTO_TXINVERT | PROTO_RXINVERT);
            if (invert_mask == PROTO_TXINVERT || invert_mask == PROTO_RXINVERT)
               continue;
         }
         if ((proto_type () == PROTO_TYPE_S21 && nos21) ||      //
             (proto_type () == PROTO_TYPE_X50A && nox50a) ||    //
             (proto_type () == PROTO_TYPE_ALTHERMA_S && noas) ||        //
             ((proto & PROTO_TXINVERT) && noswaptx) ||  //
             ((proto & PROTO_RXINVERT) && noswaprx))
         {                      // not a protocol we want to scan, so try again
            usleep (1000);      // Yeh, silly, but someone could configure to do nothing
            continue;
         }
      }
      daikin.talking = 1;
      if (uart_enabled ())
      {                         // Poke UART
         uart_setup ();
         if ((proto_type () == PROTO_TYPE_X50A))
         {                      // Startup X50A
            daikin_x50a_command (0xAA, 1, (uint8_t[])
                                 {
                                 0x01}
            );
            daikin_x50a_command (0xBA, 0, NULL);
            daikin_x50a_command (0xBB, 0, NULL);
         }
         if (b.protocol_set && daikin.online != daikin.talking)
         {
            daikin.online = daikin.talking;
            daikin.status_changed = 1;
         }
      } else
      {                         // Mock configuration for interface testing
         proto = PROTO_TYPE_S21 * PROTO_SCALE;
         b.protocol_set = 1;
         daikin.control_changed = 0;
         daikin.online = 1;
      }
      if (!b.loopback)
         daikin.ha_send = 1;
      int poll = 0;
      do
      {
         // Polling loop. We exit from here only if we get a protocol error
         poll++;
         if (proto_type () != PROTO_TYPE_CN_WIRED)
         {
            /* wait for next second. For CN_WIRED we don't need to actively poll the
               A/C, so we don't need this delay. We just keep reading, packets should
               come once per second, and that's our timing */
            usleep (1000000LL - (esp_timer_get_time () % 1000000LL));
         }
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

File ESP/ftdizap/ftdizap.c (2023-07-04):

// Tweak FTDI EEPROM

#include <stdio.h>
#include <string.h>
#include <popt.h>
#include <time.h>
#include <sys/time.h>
#include <sys/types.h>
#include <sys/stat.h>
#include <fcntl.h>
#include <unistd.h>
#include <stdlib.h>
#include <ctype.h>
#include <err.h>
#include <libusb-1.0/libusb.h>
#include <libftdi1/ftdi.h>
#include <assert.h>

int debug = 0;
#define	ELEN	0x800           /* len of EEPROM */
#define	SPOS	0x0A0           /* Start of strings */
#define	CSUM	0x0FE           /* Pos of checksum */
unsigned char buf[ELEN];
unsigned char was[ELEN];
unsigned int spos = SPOS;

// Note CBUS mode documentation is lacking, depends on chip... See https://www.intra2net.com/en/developer/libftdi/documentation/ftdi_8c_source.html
// FT230/FT231 :-
// 0    TRISTATE
// 1    TXLED
// 2    RXLED
// 3    TXRXLED
// 4    PWREN
// 5    SLEEP
// 6    DRIVE_0
// 7    DRIVE_1
// 8    IOMODE
// 9    TXDEN
// 10   CLK24
// 11   CLK12
// 12   CLK6
// 13   BAT_DETECT
// 14   BAT_DETECT#
// 15   I2C_TXE#
// 16   I2C_RXF#
// 17   VBUS_SENSE
// 18   BB_WR#
// 19   BBRD#
// 20   TIME_STAMP
// 21   AWAKE#

#define inline

inline unsigned char
getbit (unsigned int n, unsigned int b)
{
   assert (n < ELEN);
   assert (b < 8);
   return (buf[n] >> b) & 1;
}

void
setbit (unsigned int n, unsigned int b, int v, const char *desc)
{
   assert (n < ELEN);
   assert (b < 8);
   assert (v < 2);
   int was = getbit (n, b);
   if (debug)
      fprintf (stderr, "0x%d    %s", was, desc);
   if (v < 0)
   {
      if (debug)
         fprintf (stderr, "\n");
      return;
   }
   if (v == was)
   {
      if (debug)
         fprintf (stderr, " unchanged\n");
      return;
   }
   if (debug)
      fprintf (stderr, " changed to 0x%d\n", v);
   buf[n] = (buf[n] & ~(1 << b)) | (v << b);
}

inline unsigned char
getbit2 (unsigned int n, unsigned int b)
{
   assert (n < ELEN);
   assert (b < 7);
   return (buf[n] >> b) & 3;
}

void
setbit2 (unsigned int n, unsigned int b, int v, const char *desc)
{
   assert (n < ELEN);
   assert (b < 8);
   assert (v < 4);
   int was = getbit (n, b);
   if (debug)
      fprintf (stderr, "0x%d    %s", was, desc);
   if (v < 0)
   {
      if (debug)
         fprintf (stderr, "\n");
      return;
   }
   if (v == was)
   {
      if (debug)
         fprintf (stderr, " unchanged\n");
      return;
   }
   if (debug)
      fprintf (stderr, " changed to 0x%d\n", v);
   buf[n] = (buf[n] & ~(3 << b)) | (v << b);

}

inline unsigned char
getbyte (unsigned int n)
{
   assert (n < ELEN);
   return buf[n];
}

void
setbyte (unsigned int n, int v, const char *desc)
{
   assert (n < ELEN);
   assert (v < 0x100);
   unsigned char was = getbyte (n);
   if (debug)
      fprintf (stderr, "0x%02X   %s", was, desc ? : "");
   if (v < 0)
   {
      if (debug)
         fprintf (stderr, "\n");
      return;
   }
   if (v == was)
   {
      if (debug)
         fprintf (stderr, " unchanged\n");
      return;
   }
   if (debug)
      fprintf (stderr, " changed to 0x%02X\n", v);
   buf[n] = v;
}

inline unsigned short
getword (unsigned int n)
{
   assert (n < ELEN / 2);
   return (buf[n * 2 + 1] << 8) | (buf[n * 2]);
}

void
setword (unsigned int n, int v, const char *desc)
{
   assert (n < ELEN / 2);
   assert (v < 0x10000);
   unsigned short was = getword (n);
   if (debug)
      fprintf (stderr, "0x%04X %s", was, desc ? : "");
   if (v < 0)
   {
      if (debug)
         fprintf (stderr, "\n");
      return;
   }
   if (v == was)
   {
      if (debug)
         fprintf (stderr, " unchanged\n");
      return;
   }
   if (debug)
      fprintf (stderr, " changed to 0x%04X\n", v);
   buf[n * 2 + 1] = (v >> 8);
   buf[n * 2] = v;
}

char *
getstring (unsigned int n, const char *desc)
{
   assert (n < ELEN / 2);
   int pos = getbyte (n * 2);
   int len = getbyte (n * 2 + 1);
   if (pos < SPOS || pos + len >= CSUM || (len && (len < 2 || buf[pos] != len || buf[pos + 1] != 3)))
   {
      warnx ("Bad string %s at 0x%04X+%d", desc, pos, len);
      return "";
   }
   len = (len - 2) / 2;
   char *ret = malloc (len + 1);
   if (!ret)
      errx (1, "malloc");
   for (int a = 0; a < len; a++)
      ret[a] = buf[pos + 2 + a * 2];
   ret[len] = 0;
   /* TODO does that mean unicode, we could UTF stuff? */
   return ret;
}

void
setstring (unsigned int n, const char *s, const char *desc)
{
   char *was = getstring (n, desc);
   if (!s)
      s = was;
   if (debug)
   {
      if (strcmp (s, was))
         fprintf (stderr, "%s changed from \"%s\" to \"%s\"\n", desc, was, s);
      else
         fprintf (stderr, "%s unchanged \"%s\"\n", desc, was);
   }
   int len = 2 + strlen (s) * 2;
   if (spos + len >= CSUM)
      errx (1, "Strings too long");
   buf[n * 2] = spos;
   buf[n * 2 + 1] = len;
   buf[spos++] = len;
   buf[spos++] = 0x03;          /* string */
   while (*s)
   {
      buf[spos++] = *s++;
      buf[spos++] = 0;
   }
   /* TODO does that mean unicode, we could UTF stuff? */
}

void
checksum (void)
{
   //Calculate and store checksum
   unsigned short c = 0xAAAA;
   for (int a = 0; a < 0x12; a++)
   {
      c ^= getword (a);
      c = (c << 1) | (c >> 15);
   }
   for (int a = 0x40; a < 0x7F; a++)
   {
      c ^= getword (a);
      c = (c << 1) | (c >> 15);
   }
   setword (0x7F, c, "Checksum");
}
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

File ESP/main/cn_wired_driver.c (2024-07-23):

#include "revk.h"
#include <driver/rmt_tx.h>
#include <driver/rmt_rx.h>
#include "cn_wired.h"
#include "cn_wired_driver.h"

static const char TAG[] = "Faikin";

#define	CN_WIRED_SYNC	2600    // uS
#define	CN_WIRED_START	(cnmark900?900:1000)    // uS
#define	CN_WIRED_SPACE	300     // uS
#define	CN_WIRED_0	400     // uS
#define	CN_WIRED_1	1000    // uS
#define	CN_WIRED_IDLE	16000   // uS
#define	CN_WIRED_TERM	2000    // uS
#define	CN_WIRED_MARGIN	200     // uS
rmt_channel_handle_t rmt_tx = NULL,
   rmt_rx = NULL;
rmt_encoder_handle_t rmt_encoder = NULL;
rmt_symbol_word_t rmt_rx_raw[70];       // Needs to allow for 66, extra is to spot longer messages
volatile size_t rmt_rx_len = 0; // Rx is ready
const rmt_receive_config_t rmt_rx_config = {
   .signal_range_min_ns = 1000, // shortest - to eliminate glitches
    // longest - needs to be over the 2600uS sync pulse...
   .signal_range_max_ns = (CN_WIRED_SYNC + CN_WIRED_MARGIN) * 1000,
};

// We want our TX line to sit high when idle. Unfortunately the new RMT driver
// doesn't really allow us to do that. Inside rmt_tx.c rmt_new_tx_channel() function
// does this (as of v5.2.2 release):
//    // idle level is determined by register value
//    rmt_ll_tx_fix_idle_level(hal->regs, channel_id, 0, true);
// So, it simply forces idle level to 0, and it stays so until the first tx happens.
// In order to circumvent the issue we invert the whole thing and apply GPIO inversion,
// so that hardcoded 0 becomes HIGH. Hence values here are swapped, not a bug!
static const uint16_t TX_HIGH = 0;
static const uint16_t TX_LOW  = 1;

const rmt_transmit_config_t rmt_tx_config = {
   .flags.eot_level = TX_HIGH,
};

bool
rmt_rx_callback (rmt_channel_handle_t channel, const rmt_rx_done_event_data_t * edata, void *user_data)
{
   if (edata->num_symbols < 64)
   {                            // Silly... restart rx
      rmt_rx_len = 0;
      rmt_receive (rmt_rx, rmt_rx_raw, sizeof (rmt_rx_raw), &rmt_rx_config);
      return pdFALSE;
   }
   // Got something
   rmt_rx_len = edata->num_symbols;
   return pdFALSE;
}

esp_err_t
cn_wired_driver_install (gpio_num_t rx_num, gpio_num_t tx_num, int rx_invert, int tx_invert)
{
   esp_err_t err = ESP_OK;

   if (rmt_rx || rmt_tx)
   {
      ESP_LOGE (TAG, "cn_wired driver already initialized");
      return ESP_FAIL;
   }

   if (!rmt_encoder)
   {
      rmt_copy_encoder_config_t encoder_config = {
      };
      err = REVK_ERR_CHECK (rmt_new_copy_encoder (&encoder_config, &rmt_encoder));
   }
   if (!err)
   {                         // Create rmt_tx
      rmt_tx_channel_config_t tx_chan_config = {
         .clk_src = RMT_CLK_SRC_DEFAULT,     // select source clock
         .gpio_num = tx_num, // GPIO number
         .mem_block_symbols = 72,    // symbols
         .resolution_hz = 1 * 1000 * 1000,   // 1 MHz tick resolution, i.e., 1 tick = 1 µs
         .trans_queue_depth = 1,     // set the number of transactions that can pend in the background
         .flags.invert_out = tx_invert ^ TX_LOW,    // See comments at TX_LOW/TX_HIGH definitions
#ifdef  CONFIG_IDF_TARGET_ESP32S3
         .flags.with_dma = true,
#endif
      };
      err = REVK_ERR_CHECK (rmt_new_tx_channel (&tx_chan_config, &rmt_tx));
      if (rmt_tx && !err)
         err = REVK_ERR_CHECK (rmt_enable (rmt_tx));
   }
   if (!err)
   {                         // Create rmt_rx
      rmt_rx_channel_config_t rx_chan_config = {
         .clk_src = RMT_CLK_SRC_DEFAULT,     // select source clock
         .resolution_hz = 1 * 1000 * 1000,   // 1MHz tick resolution, i.e. 1 tick = 1us
         .mem_block_symbols = 72,    // 
         .gpio_num = rx_num, // GPIO number
         .flags.invert_in = rx_invert,
#ifdef  CONFIG_IDF_TARGET_ESP32S3
         .flags.with_dma = true,
#endif
      };
      err = REVK_ERR_CHECK (rmt_new_rx_channel (&rx_chan_config, &rmt_rx));
      if (rmt_rx)
      {
         rmt_rx_event_callbacks_t cbs = {
            .on_recv_done = rmt_rx_callback,
         };
         err = REVK_ERR_CHECK (rmt_rx_register_event_callbacks (rmt_rx, &cbs, NULL));
         if (!err)
            err = REVK_ERR_CHECK (rmt_enable (rmt_rx));
      }
   }
   rmt_rx_len = 0;
   if (!err)
      err = REVK_ERR_CHECK (rmt_receive (rmt_rx, rmt_rx_raw, sizeof (rmt_rx_raw), &rmt_rx_config));
   return err;
}

void
cn_wired_driver_delete (void)
{
   if (rmt_tx)
   {
      REVK_ERR_CHECK (rmt_disable (rmt_tx));
      REVK_ERR_CHECK (rmt_del_channel (rmt_tx));
      rmt_tx = NULL;
   }
   if (rmt_rx)
   {
      REVK_ERR_CHECK (rmt_disable (rmt_rx));
      REVK_ERR_CHECK (rmt_del_channel (rmt_rx));
      rmt_rx = NULL;
   }
}

// Raw signal lengths for debugging stats
static uint32_t rx_len;
static uint32_t rx_sync;
static uint32_t rx_start;
static uint32_t rx_space;
static uint32_t rx_0;
static uint32_t rx_1;

void
cn_wired_stats (jo_t j)
{
   jo_int (j, "rmt_rx_len", rx_len);
   jo_int (j, "sync", rx_sync);
   jo_int (j, "start", rx_start);
   jo_int (j, "space", rx_space);
   jo_int (j, "0", rx_0);
   jo_int (j, "1", rx_1);
}
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

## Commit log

2024-02-14 Started on pass through
    [Faikin+.kicad_pcb, Faikin+.kicad_sch, bom.csv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]
2024-02-14 New pass through
    [Faikin+.kicad_pcb, Faikin+.kicad_sch]
2024-02-15 New board
    [Faikin+.kicad_pcb, bom.csv, designators.csv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]
2024-02-16 4 vcuts
    [Faikin+.kicad_pcb]
2024-02-16 PCB tweaks
    [Faikin.kicad_pcb]
2024-02-19 ESP32: Introduce build.bat for use under Windows
    Our build uses some auxiliary tools, which are also built from C sources in the
    process. Unfortunately Windows version of ESP32-IDF decided to ditch MinGW, and
    comes with a naked Windows cmd.exe shell with a minimalist set of tools (idf.py,
    git, and that's all). It's not possible to run idf.py from e. g. MinGW prompt;
    it doesn't allow doing that.
    Our auxiliary tools require a full POSIX environment with gcc and make.
    Work around IDF limitations by introducing a bridge script, which relies on a
    side-by-side installation of a POSIX environment, such as MSYS or Cygwin. Our
    auxiliary tools are now run via that environment, while idf.py keeps liv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
2024-02-23 Tweak artwork
    [Faikin.kicad_pcb, positions.csv]
2024-02-23 Bigger pads
    [Faikin.kicad_pcb, Faikin.kicad_sch, bom.csv]
2024-02-24 KiCad 8.0
    [Faikin.kicad_pcb, Faikin.kicad_sch]
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2024-03-12 Library update
    [Faikin.kicad_pcb]
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2024-05-05 ESP32: Build without BLE
    Rearrange #ifdef ELA so that the build completes correctly without bluetooth
    support; and auto mode doesn't get disabled as a side effect.
    Auto-generated settings.h cannot rely on ELA, because this macro is defined by
    bleenv.h, so we're using more fundamental CONFIG_BT_NIMBLE_ENABLED
    Required by ESP8266 port.
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2024-05-05 main/Faikin: Separate uart_setup()
    Move it out of app_main(). This function is large by itself, additionally it
    doesn't really use any local variables, so there's completely no reason for it
    to be nested. Increases readability of the code dramatically.
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2024-05-18 Update user comments layer
    [Faikin.kicad_pcb]
2024-06-08 Rework USB connector
    [Faikin.kicad_pcb, Faikin.kicad_sch, bom.csv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]
2024-06-08 Fix solder mask on USb
    [Faikin.kicad_pcb]
2024-06-08 Slightly rearranged
    [Faikin.kicad_pcb, positions.csv]
2024-06-08 Tidy USB even more
    [Faikin.kicad_pcb, positions.csv]
2024-06-23 TC2030-USB-NL cable pin out
    [Faikin.kicad_pcb, Faikin.kicad_sch, designators.csv]
2024-06-23 Reworked for TC2030-USB-NL
    [Faikin.kicad_pcb, Faikin.kicad_sch, designators.csv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]
2024-06-24 Tweaked PCb
    [Faikin.kicad_pcb, Faikin.kicad_sch]
2024-06-25 Tidy PCb
    [Faikin.kicad_pcb, Faikin.kicad_sch, bom.csv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]
2024-06-25 New header
    [Faikin+.kicad_pcb, Faikin+.kicad_sch, bom.csv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]
2024-06-26 Smaller positioning holes
    [Faikin.kicad_pcb]
2024-06-28 main/Faikin: Report correct temperature step for HomeAssistant
    Factor out a common routine and use it. CN_WIRED step is 1C.
    The issue reported in
    https://github.com/Sonic-Amiga/ESP8266-Faikin/issues/15#issuecomment-2193151580
2024-06-30 Solder paste
    [Faikin.kicad_pcb]
2024-06-30 3D case
    [Faikin.scad, Faikin.stl]
2024-07-03 ESP/release: New 8266 release.
    - Many upgrades and improvements from ESP32 version
    - Fixed compatibility with FTN15PV1L (CN_WIRED, https://github.com/Sonic-Amiga/ESP8266-Faikin/issues/15)
    (cherry picked from commit 35bdcbe081719c78d9885fe0850aba3f3efceb76)
2024-07-07 ESP/main: Separate CN_WIRED driver
    Restructure the code in a manner, similar to ESP8266 port. Introduce a
    replace-able CN_WIRED driver implementation in a separate file.
    [cn_wired.h, cn_wired_driver.c]
2024-07-07 main/Faikin: Fix a bug with reconfiguring CN_WIRED
    Every time we change tx/rx inversion, we need to reconfigure rmt from scratch
    by calling rmt_new_??_channel(), which is only possible after we stop and
    delete old channels. To make sure it's done properly, we need to always shut
    down the driver before changing protocol and/or inversion.
2024-07-09 main/cn_wired_driver: Invert TX
    There's a problem with setting TX line to high when idle. A workaround is to
    leave it low, invert the whole transmission, and then apply gpio inversion.
    [cn_wired_driver.c]
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2024-07-13 3D model update, and case
    [Faikin.kicad_pcb, Faikin.scad, Faikin.stl]
2024-07-13 Tweak LED and casework
    [Faikin.kicad_pcb, Faikin.scad, Faikin.stl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]
2024-07-15 TC2030 hole size adjuistment
    [Faikin.kicad_pcb, designators.csv]
2024-07-22 ESP/main: Tweak CN_WIRED rx/tx timings
    - Adjust signal_range_max_ns, so that we don't wait for too long
    - Sleep 20 ms between receiving a packet and sending our packet.
    This ensures that the packet we send falls in between packets AC sends to us.
    The same algorithm works on 8266.
    [cn_wired_driver.c]
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2024-08-05 main/Faikin: Proper HA fan modes for CN_WIRED
    C_WIRED uses 3 speeds + auto + quiet (which is called "night" in S21). Our user
    interface works with that correctly, but HA interface won't understand "quiet".
    Fix that.
2024-08-06 Slight tweak for LED visibility from other side
    [Faikin.kicad_pcb, Faikin.kicad_sch, bom.csv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]
2024-08-10 10k pull on rx now - for testing
    [Faikin.kicad_pcb, Faikin.kicad_sch, bom.csv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]
2024-08-10 main/Faikin: Handle S21 timeout as such
    In case of S21 response timeout, send "timeout" over mqtt instead of "noack".
    This makes origin of the problem more clear for those who read debug log.
    Another good side effect is that loopback status now also goes away if loopback
    is broken
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2024-08-16 Added diode
    [Faikin.kicad_pcb, Faikin.kicad_sch, bom.csv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]
2024-08-17 Removed Faikin+ as was a test board only
    [Faikin+.kicad_pcb, Faikin+.kicad_sch, bom.csv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]
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2024-08-19 main/Faikin: Fix "powerful" mode
    Now fully works on FTXF20D5V1B.
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2024-08-25 8266 release
    Version: 2591fe5
    Date : Aug 25 2024 23:42:05
    - Fixes to HomeAssistant support by RevK
    - "Powerful" mode now works on some A/Cs (ATX20 and compatibles)
    - Improvements to debug mode and command injection
    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
2024-09-19 Simulators/faikin-s21: Fixed "power" initialization
    Fixed stupid bug, power is now correct (0 or 1)
2024-09-21 ESP: Introduce udp_discovery setting
    It turns out that our legacy API isn't completely properly done; and it appears
    to disrupt Daikin app's advanced functionality (like power saving modes),
    causing it to crash.
    Let's mitigate that by introducing a setting, which allows for enable or disable
    auto-discovery on demand. Defaults to off since the feature is currently
    experimental.
2024-11-04 Fine tune
    [Faikin.kicad_pcb, positions.csv]
2025-01-03 Tweak wording
    [Faikin.scad]
2025-01-04 Latest case
    [Faikin.kicad_pcb, Faikin.scad, Faikin.stl]
2025-01-04 New case
    [Faikin.scad, Faikin.stl]
2025-01-04 Tidy STL
    [Faikin.kicad_pcb, Faikin.scad, Faikin.stl]
2025-01-12 Image cleanup
    [Faikin.scad, Faikin.stl]
2025-01-13 Re draw
    [Faikin.kicad_pcb]
2025-01-17 New panel
    [Faikin.kicad_pcb, designators.csv, positions.csv]
2025-01-22 Clean for new KiCAD
    [Faikin.kicad_pcb, Faikin.kicad_sch, bom.csv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]
2025-01-23 PCB Update
    [Faikin.kicad_pcb, Faikin.kicad_sch, bom.csv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]
2025-01-30 New render with datamatrix production code on panels
    [Faikin.kicad_pcb]
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2025-04-07 Spacing adjust
    [Faikin.kicad_pcb, Faikin.kicad_sch, bom.csv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]
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2025-05-03 Faikin power control fixes
2025-05-23 Render update
    [Faikin.kicad_pcb, Faikin.scad, Faikin.stl]
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2025-06-21 Update website
    [Faikin.kicad_pcb, Faikin.scad, Faikin.stl]
2025-07-04 Dev for 2AS supply
    [Faikin.kicad_pcb, Faikin.kicad_sch, bom.csv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]
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2025-07-09 Latest render
    [Faikin.kicad_pcb]
2025-07-20 Moved caps away from heat
    [Faikin.kicad_pcb, Faikin.kicad_sch, bom.csv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]
2025-07-20 Ordering new batch
    [Faikin.kicad_pcb, Faikin.kicad_sch]
2025-07-21 PCB tweak
    [Faikin.kicad_pcb, Faikin.kicad_sch, Faikin.scad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]
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2025-07-24 Tweak caps and inductor
    [Faikin.kicad_pcb, Faikin.kicad_sch, bom.csv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]
2025-07-24 You can never have too many caps.
    [Faikin.kicad_pcb, Faikin.kicad_sch, bom.csv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]
2025-07-31 New PCB
    [Faikin.kicad_pcb, Faikin.kicad_sch, Faikin.scad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]
2025-08-01 Case update
    [Faikin.stl]
2025-08-02 Latest tracking
    [Faikin.scad, Faikin.stl]
2025-08-04 New 0201 footprint
    [Faikin.kicad_pcb, Faikin.scad, Faikin.stl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]
2025-08-04 Updated 3D
    [Faikin.scad, Faikin.stl]
2025-08-05 Tweak case
    [Faikin.scad, Faikin.stl]
2025-08-08 Revised test points
    [Faikin.kicad_pcb, Faikin.kicad_sch, Faikin.scad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]
2025-08-09 Case tidy
    [Faikin.scad, Faikin.stl]
2025-08-11 Fit adjust
    [Faikin.scad, Faikin.stl]
2025-08-11 case tweaks
    [Faikin.stl, FaikinB.scad, FaikinB.stl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]
2025-08-12 Case tweak
    [Faikin.scad, Faikin.stl, FaikinB.scad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]
2025-08-12 Re-render cases
    [Faikin.scad, Faikin.stl, FaikinB.scad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]
2025-08-12 Separate STL files
    [Faikin.scad, Faikin.stl]
2025-08-12 Tweak case lip
    [FaikinB.scad, FaikinB.stl, FaikinT.scad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]
2025-08-12 Yet further revised case design
    [FaikinB.scad, FaikinB.stl, FaikinT.scad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]
2025-08-12 More tweaks
    [FaikinB.scad, FaikinB.stl, FaikinT.scad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]
2025-08-13 Track adjust
    [Faikin.kicad_pcb, bom.csv, positions.csv]
2025-08-13 Tweak layout, and more test points
    [Faikin.kicad_pcb, Faikin.kicad_sch, FaikinB.scad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]
2025-08-17 Re render
    [FaikinB.scad, FaikinT.scad, FaikinT.stl]
2025-08-18 New cases
    [FaikinB.scad, FaikinB.stl, FaikinT.scad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]
2025-08-20 Slight change to case parameters
    [FaikinB.scad, FaikinB.stl, FaikinT.scad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]
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2025-08-27 Back to ENIG finish for renders
    [Faikin.kicad_pcb, FaikinB.scad, FaikinB.stl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]
2025-09-08 Render (but wrong colour?)
    [Faikin.kicad_pcb, FaikinB.scad, FaikinT.scad]
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2025-09-28 Rework with new LED and TC2030 rotate
    [Faikin.kicad_sch, FaikinB.scad, FaikinB.stl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]
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2025-11-05 General render and README updates
    [FaikinB.scad, FaikinB.stl, FaikinC.scad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]
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
